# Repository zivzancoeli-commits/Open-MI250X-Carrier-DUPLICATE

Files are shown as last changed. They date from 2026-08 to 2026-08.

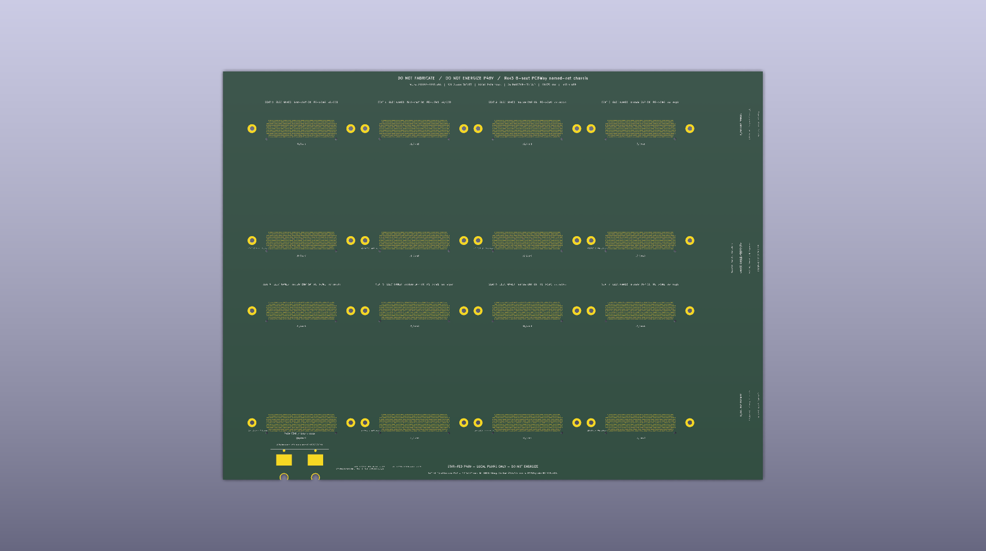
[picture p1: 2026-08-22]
Generated_Project/Rev3_8Seat_PCBWay_Chassis_v1/docs/previews/MI250X_8OAM_PCBWay_Chassis_Stub-top-render.png

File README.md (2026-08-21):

> **DUPLICATE working copy — not the original.**
> Original: https://github.com/zivzancoeli-commits/Open-MI250X-Carrier
> Marked duplicate: 2026-08-21

# Open MI250X Carrier

## Purpose
This project collects public evidence needed to design a minimal open-source carrier board for surplus AMD Instinct MI250X OAM modules. It is organized as a reverse-engineering knowledge base: public documentation is collected first, facts are extracted into notes, and unknown or proprietary behavior is tracked instead of assumed.

## Workflow
- Collect public links and local reference copies in [02_AMD_Docs](02_AMD_Docs/) and [13_Reference_Docs](13_Reference_Docs/).
- Extract design-relevant facts into [09_AI_Notes](09_AI_Notes/), separating verified information from questions.
- Use research in [08_Research_Papers](08_Research_Papers/) to understand topology, bandwidth, and system context before design decisions.
- Carry verified mechanical, PCIe, power, cooling, firmware, and software assumptions into schematic, layout, prototype, and validation work.

## Top-Level Folders
- [02_AMD_Docs](02_AMD_Docs/): upstream public links for OAM, AMD matrix cores, ROCm compatibility, and MI250X software support.
- [08_Research_Papers](08_Research_Papers/): architecture and data-movement research, currently focused on topology and bandwidth.
- [09_AI_Notes](09_AI_Notes/): topic notes for architecture, PCIe, power, cooling, clocking, management, ideas, questions, and unknowns.
- [13_Reference_Docs](13_Reference_Docs/): local indexes and reference material for AMD, ROCm, OAM/OCP, Molex, cooling, firmware, memory, and components.

## Known Information
- Manual project status items: gather public documentation, understand OAM, identify undocumented interfaces, create architecture, draw schematic, PCB layout, prototype.
- Manual note: undocumented behavior should be tracked as an open question rather than assumed.
- `Wanted_Documents.rtf` tracks OAM, AMD, PCIe, power, cooling, and photo references; no image files are currently present.
- MP2975 is listed as believed present on MI250X, but not visually confirmed.

## Project Roadmap
1. Documentation Collection
2. Knowledge Extraction
3. Reverse Engineering
4. Schematic Design
5. PCB Layout
6. Prototype
7. Bring-up and Validation

## Open Questions
- Mechanical, baseboard, connector, PCIe routing, REFCLK, PMBus, VRM, and OAM thermal references are listed as missing or incomplete.
- Three local PDFs could not be read because they report invalid PDF structure.

## TODO
- Keep `Wanted_Documents.rtf` aligned with files added under `13_Reference_Docs`.
- Move verified findings into `09_AI_Notes` with clear evidence and uncertainty labels.

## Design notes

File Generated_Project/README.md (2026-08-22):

# Generated Project — MI250X OAM Prototype Carrier Rev1

Auto-generated KiCad 9 hierarchical schematic for a **single AMD Instinct MI250X OAM** prototype carrier board.

**Status:** `0.1-prototype` — architectural scaffold, not layout-ready or procurement-ready.

## Open in KiCad

```
Generated_Project/Rev1_MI250X_Carrier/MI250X_Carrier_Rev1.kicad_pro
```

Requires **KiCad 9** (schematic format version `20250114`).

## Regenerate

```bash
python3 Generated_Project/tools/generate_kicad_project.py
```

## Hierarchy

| Sheet | File | Function |
|---|---|---|
| Root | `MI250X_Carrier_Rev1.kicad_sch` | Top-level sheet instances |
| OAM Interface | `sheets/02_oam_interface.kicad_sch` | Mirror Mezz Conn0/Conn1 placeholders |
| Host PCIe | `sheets/03_host_pcie.kicad_sch` | Gen4 x16 host edge / routing |
| Power System | `sheets/04_power_system.kicad_sch` | 12V input, OAM 12V, 3.3V management |
| Clocking & Reset | `sheets/05_clocking_reset.kicad_sch` | 100 MHz PE_REFCLK, PERST# |
| Management | `sheets/06_management.kicad_sch` | FRU EEPROM, I2C, PMBus, UART, temp sensor |
| Test Points | `sheets/07_test_points.kicad_sch` | Bring-up measurement access |
| Expansion | `sheets/08_expansion.kicad_sch` | Multi-OAM hooks (DNP on Rev1) |

## Documentation

- `Rev1_MI250X_Carrier/docs/sources.md` — verified references
- `Rev1_MI250X_Carrier/docs/assumptions.md` — prototype assumptions
- `Rev1_MI250X_Carrier/docs/open_questions.md` — blocking TODOs
- `Rev1_MI250X_Carrier/docs/oam_signal_map.md` — OCP logical signal names
- `ENGINEERING_REVIEW.md` — post-generation review report
- `BOM_Rev1_Prototype.md` — placeholder BOM

## Design rules

- OCP OAM signal **names** used where verified; physical pin numbers **TODO**.
- AMD-specific behavior marked **TODO** — not routed or assigned.
- Does not modify `16_KiCad_Design/` per `AI_DESIGN_RULES.md`.

## Buyable first system (copied tree, 2026-08-17)

Do not overwrite Rev1 or other Rev2 production folders. The 2-OAM **v1.0-mapped stub** (not fab-ready) is:

```
Generated_Project/Rev2_MI250X_Carrier_BuyableFirstSystem_v1/
```

Shopping list: `20_System_BOM/SHOPPING.md`. Pin map authority: `22_Pinmap_Research/` (OCP generic v1.0, 688 contacts, not r2.0).

## Rev3 8-seat PCBWay chassis (Chamber B PCB only, 2026-08-22)

**DO NOT ENERGIZE P48V.** POWER+MECH first-article zip is in `Rev3_8Seat_PCBWay_Chassis_v1/fab/`. Do not upload from this agent. Does not overwrite Rev1 or Rev2 trees.

```
Generated_Project/Rev3_8Seat_PCBWay_Chassis_v1/
```

Eight electrically designed OAM seats on a **12-layer 2.0 mm** stuffed-switch target. First article: seats **0–1** GCD0 x16. Compatible with the Chamber B sheet (X11DPH-T neighbour, not on this PCB). See `Rev3_8Seat_PCBWay_Chassis_v1/docs/STATUS.md`.

**8× full-width CONCEPT** (ideas only, **DO NOT FABRICATE** as live PE): `Rev3_8Seat_FULLWIDTH_CONCEPT/CONCEPT.md`. Late-bind reservations: `Rev3_8Seat_FULLWIDTH_CONCEPT/LATE_BIND.md` (**16× x16 + four BGA escapes = respin**). X11DPH-T **cannot light 8× full-width**. Do not invent overlay / ball maps / CEM/MCIO. **DO NOT ENERGIZE.** The POWER+MECH zip will **not** work as a live GPU chassis if sent to PCBWay.

## Exhaustive public-source hunt (copied tree, 2026-08-17)

Research only — **not fab-ready**. Findings: `Generated_Project/Rev2_MI250X_Carrier_ExhaustiveSourceHunt_v1/FINDINGS.md`.

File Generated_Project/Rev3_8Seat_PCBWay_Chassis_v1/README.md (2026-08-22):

# Rev3 — 8-seat chassis, 2-module first article (POWER+MECH)

**DO NOT ENERGIZE P48V** until Molex 1.2 A/contact at 48–59.5 V (2 oz) is written (ticket 167157).  
**Do not upload from this agent.** Eli uploads `fab/Rev3_8Seat_PCBWay_12L_492x372_qty5_gerbers.zip` if he accepts it.

Chamber B **OAM chassis PCB** only. Not a motherboard. Do not swap X11DPH-T.

- **First-article target: seats 0–1.** Without overlay, 2× MI250X = two modules **sit** and at most **GCD0** on each can be targeted (**2 GCDs**). **Not** 2× full-width (**4 GCDs**).
- Legal host PE today: Conn0 OCP `PCIE_*` = `PE_S0_GCD0_x16` + `PE_S1_GCD0_x16` toward the host keepout. GCD1 named-only. Not S1–S7. Conn1 has **0** `PCIE_*`.
- Host X11DPH-T: two GCD0 x16 **fit**; two full-width modules **do not**. **No CEM/MCIO MPN invented.**
- Same PCB populate **2 → 4 → 8**. Later-seat x16 names + SW0–SW3 DNP kept. Do not stuff switches this article.
- Pin names: OCP generic **v1.0**. **v1.x only.** r2.0 is UNUSABLE. P3V3 = Conn0 C1/C2.
- **P48V:** Anderson **6325G1** + 2× **1382** → star spines (not a 100 A flood) → per-seat **0476015.MR** 15 A. First populate F0/F1. Off-board 48 V: 240 V / 50 A single-phase class — **not** RST-5000-48 (3-phase).
- **P12V1 / P3V3:** **THL 40-4812WI** (40 W from 48 V) + **OKI-78SR-3.3/1.5-W36-C** (4.95 W from P12V1). No GPU VRM.
- TEST*/RFU/DO_NOT_USE **unmapped**. PVREF **not driven**. S1–S7 **no net**.
- Silk keeps **DO NOT ENERGIZE P48V**. PE stays unrouted (DNP switches).

| File | What |
|---|---|
| `fab/Rev3_8Seat_PCBWay_12L_492x372_qty5_gerbers.zip` | Gerbers, drill, IPC-356, PnP, FAB_NOTES, BOM |
| `docs/STATUS.md` | What Eli can upload vs what stays DNP |
| `docs/EPYC_2P_PUBLIC_SOURCES.md` | Research-only: opened AMD/OEM 2P xGMI URLs. **No 4P path in public docs.** Not a motherboard. |
| `docs/CONCEPT_8x_FULL_WIDTH.md` | Pointer to 8× full-width **CONCEPT** (ideas only) |
| `docs/LATE_BIND.md` | Pointer: reserved vs later-spin (**respin**, not silk ECO) |
| [`../Rev3_8Seat_FULLWIDTH_CONCEPT/LATE_BIND.md`](../Rev3_8Seat_FULLWIDTH_CONCEPT/LATE_BIND.md) | Late-bind table. **DO NOT FABRICATE** live PE. |
| [`../Rev3_8Seat_FULLWIDTH_CONCEPT/CONCEPT.md`](../Rev3_8Seat_FULLWIDTH_CONCEPT/CONCEPT.md) | 8× full-width fabric sketch. **DO NOT FABRICATE.** X11DPH-T cannot light 256 DS. |
| `docs/FAB_NOTES.md` | Stackup, skip-pin NC, do-not-energize |
| `docs/PCBWAY.md` | Guest quotes 2026-08-21. Agent does not upload. |
| `BOM.md` | PCB bill with buyable MPNs |
| `docs/previews/` | Top SVG/PNG |

```
python3 Generated_Project/Rev3_8Seat_PCBWay_Chassis_v1/tools/generate_from_v10_pinmap.py
python3 Generated_Project/Rev3_8Seat_PCBWay_Chassis_v1/tools/export_fab.py
```

Do not “Update PCB from Schematic”. Do not stuff PM8536 on this article. Do not upload to PCBWay from this tree. First article still cannot run 2 live GPUs without maps. **This zip will not work as a live GPU chassis if sent to PCBWay.**

**8× full-width CONCEPT** (sibling folder): ideas only. **DO NOT FABRICATE** as live PE. **DO NOT ENERGIZE.** Host stays X11DPH-T and **cannot light 8× full-width**. Routing 16× x16 + four 1311-ball escapes is a **respin** (`LATE_BIND.md`).

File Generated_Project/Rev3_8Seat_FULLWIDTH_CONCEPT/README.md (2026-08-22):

# Rev3 8× full-width CONCEPT (ideas only)

**CONCEPT / DO NOT FABRICATE / DO NOT ENERGIZE P48V.**

This is **not** a KiCad project to tape out and **not** the POWER+MECH first-article zip.

| File | What |
|---|---|
| [CONCEPT.md](CONCEPT.md) | Architecture: public fact vs hypothesis vs missing, mermaid + ASCII, can/cannot |
| [LATE_BIND.md](LATE_BIND.md) | Reserved vs later spin. **16× x16 + four BGA escapes = respin, not silk ECO.** |
| [concept_fabric.svg](concept_fabric.svg) | Block diagram (same story as the mermaid) |
| `../Rev3_8Seat_PCBWay_Chassis_v1/` | Existing 8-seat board (seats 0–1 first article). Four PM8536 DNP courtyards already placed. |

Host stays **X11DPH-T**. This CONCEPT **cannot light 8× full-width** on that host. Do not design a CPU board here. Do not invent overlay / ball maps / CEM/MCIO / r2.0 / S1–S7.

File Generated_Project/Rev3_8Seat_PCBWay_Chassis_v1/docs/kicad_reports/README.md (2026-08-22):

# KiCad 9.0.9 CLI reports (not a fab sign-off)

Run 2026-08-22 on the **12-layer 2.0 mm** POWER+MECH first article after zone fill (**2-module target: seats 0–1 GCD0 x16**).

- `drc.rpt` / `drc.json` — **0 errors**, **38** warnings, **268** unconnected items:
  - `lib_footprint_mismatch` **28** (warning): 16× 218910-1115 + SB175 + fuses/bucks (placed pads carry nets the library footprint does not).
  - `silk_overlap` / `silk_edge_clearance` / `text_height` (warning).
  - `isolated_copper` **5** (warning): leftover pour islands, not a submit blocker.
  - Unconnected **268**: PE / REFCLK / PERST# have names but no tracks (four DNP PM8536). Count may be truncated by the CLI.
- Layer SVG: Edge.Cuts, F.SilkS, F.Cu (filled), F.CrtYd, Dwgs.User, Cmts.User, In1/In4/In7/In10 (GND planes).
- PCB top preview: `../previews/MI250X_8OAM_PCBWay_Chassis_Stub-top.{svg,png}`.

Do not “Update PCB from Schematic”. **DO NOT ENERGIZE P48V.** Do not stuff the DNP switches. First article is seats 0–1 GCD0 x16 (2 GCDs). Later-seat 8-wide names stay; host X11DPH-T cannot light 4× x16 or 256 DS.

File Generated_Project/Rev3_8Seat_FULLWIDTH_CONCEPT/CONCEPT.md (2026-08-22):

# CONCEPT — 8× MI250X full-width chassis fabric

**CONCEPT / IDEAS ONLY. DO NOT FABRICATE. DO NOT ENERGIZE P48V.**  
**Not a motherboard. Not a PCBWay zip. Not a live PE design.**

This folder is an architecture sketch Eli can build later spins on. It sits beside the Rev3 8-seat board (`Generated_Project/Rev3_8Seat_PCBWay_Chassis_v1/`). First-article populate remains **seats 0–1, GCD0 x16 only**. The 8-wide names and four PM8536 DNP courtyards already on that board are the physical hooks for this CONCEPT — they are **not** routed, stuffed, or claimed DRC-clean as live PE.

Do **not** invent: AMD overlay pad numbers, PM8536 ball maps, CEM/MCIO pinouts, OAM r2.0 maps, S1–S7 assignments, TEST\*/RFU/DO_NOT_USE nets, or a host-cable MPN.

Labels: **Verified** (public doc / this repo’s pinmap CSVs) · **Hypothesis** (Eli invited; not a pin assignment) · **Missing** (blocks a later spin).

---

## What this CONCEPT is

Chassis **fabric** for eight OAM v1.x seats: 16 named x16 PE buses, four DNP switch courtyards, named host uplinks, and an xGMI mesh drawn as **boxes and port names only**.

Host of record stays SuperMicro **X11DPH-T** (~80 Gen3 lanes). **This CONCEPT cannot light 8× full-width on that host.** Do not design a new CPU board here.

## What this CONCEPT is not

- A fab package (Gerbers in `Rev3_8Seat_PCBWay_Chassis_v1/fab/` are POWER+MECH first article).
- A legal GCD1 pad map, xGMI pad map, or switch pinout.
- A claim that X11DPH-T can drive 256 downstream lanes.

---

## Public fact vs hypothesis vs missing

| Item | Class | Notes |
|---|---|---|
| 8 OAM v1.x seats, KOZ **103×166 mm**, 4×2 → floor **412×332 mm** on outline **492×372 mm** | **Verified** mech (KOZ/Fig 14); 4×2 tiling **Inferred** | Molex **218910-1115** ×16. P3V3 = Conn0 **C1/C2** only. **r2.0 unused.** |
| Conn0 `PCIE_TX/RX0–15` P/N = 64 pads, lanes 0–15 | **Verified** OCP host link | Architectural name `PE_Sn_GCD0_x16`. Pin list: PETp/n + PERp/n [15:0], Conn0, Required. |
| Conn1 `PCIE_*` | **Verified** **0** pads | GCD1 is **not** an OCP `PCIE_*` name. |
| `PE_Sn_GCD1_x16` (8 names) | **Hypothesis** name only | Overlay **Unknown**. **Do not assign S1–S7.** Conn1 `S7_*` = SERDES_7 reserved, **no net**. |
| 16 named x16 PE = “full width” | **Hypothesis** architecture | 8×2 GCD × x16. Dual-GCD is a public MI250X fact; the pad split is not. |
| PM8536B-FEI ×4, 96-lane Gen3, 1311-ball 37.5 mm 1.0 mm | **Verified** Microchip PFX package table | Courtyards **already on the Rev3 board**, **DNP**. **Ball map Missing.** |
| Each SW: 2 seats × 2 GCD × x16 DS + one x16 US (64 DS + 16 US) | **Hypothesis** partition | 80 of 96 lanes; 16 spare/SW. **Not a pinout.** |
| 256 DS + 64 US vs 4×96 = 384 | **Verified** arithmetic | Lane counts only. No balls, no routing. |
| X11DPH-T 3× x16 + 4× x8 ≈ **80** Gen3 | **Verified** SuperMicro | 4× US x16 = 64 **fit as a host uplink budget**. **256 DS do not.** CONCEPT **cannot light 8 full-width** on this host. |
| xGMI / Infinity Fabric mesh (`XGMI_Sn_P0`…) | **Hypothesis** boxes + port names | **Not** mapped to S1–S7. S1–S7 stay **no net**. |
| P48V SB175 star + per-seat `0476015.MR` | **Verified** on Rev3 copper | 240 V / 50 A **single-phase** → off-board **DPU-3200-48 class**. **Not** RST-5000-48 (3-phase). **DO NOT ENERGIZE.** |
| Host attach keepout + `PE_SWk_US_x16` names | **Hypothesis** names | **No** CEM/MCIO/SlimSAS MPN. Keepout only. |
| AMD 688-pad overlay | **Missing** | Blocks GCD1, xGMI, live PE. |
| PM8536 ball map | **Missing** | Blocks stuffing SW0–SW3. |
| Host plug + cable | **Missing** | Blocks lighting even named US links. |
| Molex 1.2 A/contact at 48–59.5 V (2 oz) | **Missing** (ticket 167157) | Blocks energize. |
| GPU cooling / cold plate | **Missing** | Not on this PCB. Do not shop onto the chassis BOM. |

---

## Seat grid (same PCB)

```
Y=20   SEAT0  SEAT1  SEAT2  SEAT3     |  SW0  SW1     host keepout
Y=186  SEAT4  SEAT5  SEAT6  SEAT7     |  SW2  SW3     (no cable MPN)
south: SB175 star + F0..F7           |  12V brick south of SW3
```

Populate on the **same copper**: seats **0–1** (first article, no stuffed switch) → **0–3** → all **8** + SW0–SW3. First article still cannot run live GPUs.

---

## PE fabric (named buses only)

**Verified** GCD0 pads: `OAM{n}_PCIE_*` = Conn0 OCP `PCIE_*`.  
**Hypothesis** names (not pad maps): `PE_Sn_GCD0_x16`, `PE_Sn_GCD1_x16`, `PE_SWk_US_x16`.

```
SW0 = seats 0,1    SW1 = seats 2,3    SW2 = seats 4,5    SW3 = seats 6,7
each:  PE_Sa_GCD0_x16 + PE_Sa_GCD1_x16 + PE_Sb_GCD0_x16 + PE_Sb_GCD1_x16  →  64 DS
       PE_SWk_US_x16  →  host keepout                                     →  16 US
```

```
8 × 2 × x16 = 256 DS
4 × x16 US  =  64 US
need 320 switch ports; 4 × 96 = 384  → 64 spare (hypothesis load)
```

Host **X11DPH-T ~80** can **name** 4× x16 US (64). It **cannot** present 256 host lanes. Switch concentration / oversubscription is an idea, not a working system. **Do not claim DRC-clean live PE.** PE / REFCLK / PERST# stay unrouted.

---

## Block diagram

```mermaid
flowchart LR
  subgraph HOST["Host of record — X11DPH-T  (~80 Gen3)  NOT on this PCB"]
    CPU["2× 6230  ·  3× x16 + 4× x8"]
  end

  subgraph KEEPOUT["Host keepout — names only · NO cable MPN"]
    US0["PE_SW0_US_x16"]
    US1["PE_SW1_US_x16"]
    US2["PE_SW2_US_x16"]
    US3["PE_SW3_US_x16"]
  end

  subgraph FABRIC["CONCEPT chassis fabric  ·  DO NOT FABRICATE as live PE"]
    SW0["U_SW0 DNP\nPM8536B-FEI\n96-lane · no ball map"]
    SW1["U_SW1 DNP"]
    SW2["U_SW2 DNP"]
    SW3["U_SW3 DNP"]
    S0["SEAT0\nGCD0 Verified Conn0 PCIE\nGCD1 named-only"]
    S1["SEAT1"]
    S2["SEAT2"]
    S3["SEAT3"]
    S4["SEAT4"]
    S5["SEAT5"]
    S6["SEAT6"]
    S7["SEAT7"]
  end

  CPU -.->|"64 US named; 256 DS do NOT fit"| KEEPOUT
  US0 --> SW0
  US1 --> SW1
  US2 --> SW2
  US3 --> SW3
  SW0 --> S0
  SW0 --> S1
  SW1 --> S2
  SW1 --> S3
  SW2 --> S4
  SW2 --> S5
  SW3 --> S6
  SW3 --> S7
```

---

## xGMI / Infinity Fabric — boxes and port names only

**Hypothesis.** These names are chassis-side idea labels (`XGMI_Sn_P0` …). They are **not** OCP pin names, **not** AMD overlay pads, and **must not** be tied to S1–S7 / TEST\* / RFU / DO_NOT_USE.

Legend (hypothesis): **P0** north · **P1** east · **P2** south · **P3** west. Edge ports that have no neighbour stay unused in the sketch.

### 4-OAM mesh (physical 2×2: seats 0, 1, 4, 5)

```
        XGMI_S0_P1 <----> XGMI_S1_P3
  SEAT0                    SEAT1
        XGMI_S0_P2          XGMI_S1_P2
           ^                   ^
           |                   |
           v                   v
        XGMI_S4_P0          XGMI_S5_P0
  SEAT4                    SEAT5
        XGMI_S4_P1 <----> XGMI_S5_P3
```

### 8-OAM mesh (4×2, all seats)

```mermaid
flowchart TB
  S0["SEAT0\nP0 P1 P2 P3"]
  S1["SEAT1"]
  S2["SEAT2"]
  S3["SEAT3"]
  S4["SEAT4"]
  S5["SEAT5"]
  S6["SEAT6"]
  S7["SEAT7"]
  S0 ---|"XGMI_S0_P1 ↔ XGMI_S1_P3"| S1
  S1 ---|"XGMI_S1_P1 ↔ XGMI_S2_P3"| S2
  S2 ---|"XGMI_S2_P1 ↔ XGMI_S3_P3"| S3
  S0 ---|"XGMI_S0_P2 ↔ XGMI_S4_P0"| S4
  S1 ---|"XGMI_S1_P2 ↔ XGMI_S5_P0"| S5
  S2 ---|"XGMI_S2_P2 ↔ XGMI_S6_P0"| S6
  S3 ---|"XGMI_S3_P2 ↔ XGMI_S7_P0"| S7
  S4 ---|"XGMI_S4_P1 ↔ XGMI_S5_P3"| S5
  S5 ---|"XGMI_S5_P1 ↔ XGMI_S6_P3"| S6
  S6 ---|"XGMI_S6_P1 ↔ XGMI_S7_P3"| S7
```

On-module GCD0↔GCD1 Infinity Fabric is a public dual-GCD fact and lives **on the module**, not as a chassis net.

---

## 48 V

Existing Rev3 path: Anderson **6325G1** + 2× **1382** (SB175) → star + Kelvin → per-seat **0476015.MR** 15 A → local Conn0 pours. **Not** a 100 A flood. **Not** Dell D3000E-S1 (12 V CRPS).

Wall: **240 V / 50 A single-phase** → off-board **DPU-3200-48 class**. **Do not specify RST-5000-48** (3-phase). Off-board PSU is **not** a PCB BOM item.

**DO NOT ENERGIZE** until Molex 1.2 A/contact at 48–59.5 V (2 oz) is written.

---

## Host attach

Keepout on the 40 mm strip + four named US links (`PE_SW0_US_x16` … `PE_SW3_US_x16`). First-article silk still calls **two** GCD0 x16 (`PE_S0_GCD0_x16` + `PE_S1_GCD0_x16`) because that is the only legal named host PE **today**.

No invented cable MPN. No CEM / SlimSAS / MCIO pinout. SuperMicro CBL-MCIO is a UBB cable, not this host.

---

## Later-spin checklist (do not do in this CONCEPT)

1. AMD overlay (GCD0 confirm, GCD1 pads, xGMI vs S1–S7 — or leave S1–S7 unmapped).
2. Public/legal PM8536 ball map, then escape (finer than 6/6 mil; requote).
3. Host plug with a **cited** datasheet; still do not invent OAM↔cable maps.
4. Molex 1.2 A/contact write-up, then reconsider energize.
5. Cooling — off this PCB.
6. A host that can actually light 256 DS if the goal is 8× full-width **host-equivalent** PE. X11DPH-T is not that host. This folder does **not** design that board.

See **[LATE_BIND.md](LATE_BIND.md)**: what is reserved vs what a later spin must add. **16× x16 PE + four 1311-ball escapes = respin, not a silk ECO.** Do not claim the POWER+MECH zip works as a live GPU chassis if sent to PCBWay.

---

## Can / cannot (this CONCEPT)

**Can (ideas / names / mech already on Rev3):**

- Sit 8 modules (KOZ, Molex, NPTH) on the existing 8-seat PCB.
- Name 16× x16 PE buses and 4× US x16 toward the keepout.
- Cite Conn0 OCP `PCIE_*` as GCD0 on every seat.
- Keep four PM8536 DNP courtyards as the public-MPN switch idea (384 vs 320 lane arithmetic).
- Draw xGMI as boxes and `XGMI_Sn_P*` names.
- Keep P48V star + per-seat fuses; 2→4→8 populate.

**Cannot:**

- Light **8× full-width** on X11DPH-T (~80 vs 256 DS).
- Map GCD1 pins, xGMI ports, or switch balls.
- Assign S1–S7 or TEST\*/RFU/DO_NOT_USE.
- Route or DRC-clean live PE.
- Invent CEM/MCIO/r2.0.
- Energize P48V or upload this CONCEPT to PCBWay as a live 8-wide.

**DO NOT FABRICATE this CONCEPT as live PE. DO NOT ENERGIZE P48V.**

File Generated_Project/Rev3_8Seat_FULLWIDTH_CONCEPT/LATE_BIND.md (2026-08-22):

# LATE BIND — what is reserved vs what a later spin must add

**DO NOT ENERGIZE P48V. First-article POWER+MECH zip remains sit-only.**  
**CONCEPT 8× full-width: DO NOT FABRICATE as live PE.**  
**Do not claim this board will work as a GPU chassis if sent to PCBWay.**

Routing **16× x16 PE** and escaping **four 1311-ball 1.0 mm BGAs** is a **copper respin**, not a silkscreen ECO. Named nets, courtyards, and comment-layer corridors do **not** become tracks when an overlay arrives.

Do **not** invent: AMD overlay pads, PM8536 balls, CEM/MCIO pinouts, r2.0 maps, S1–S7, TEST\*/RFU/DO_NOT_USE, or a host-cable MPN.

Same PCB **outline** (492×372 mm) for populate **2 → 4 → 8**. That is the only “no-respin” promise. PE / BGA / host plug are not.

Canonical CONCEPT: [CONCEPT.md](CONCEPT.md). Rev3 tree: `Generated_Project/Rev3_8Seat_PCBWay_Chassis_v1/`.

---

## Honesty: small change vs respin

| When maps arrive | Small (same outline / populate) | Respin (new copper / geometry) |
|---|---|---|
| Stuff more OAMs / F2–F7 | **Yes** — seats and fuses already on the board | |
| Assign already-named Conn0 `PCIE_*` nets | Names exist | **Tracks, vias, impedance** still a respin |
| GCD1, 16× x16, four-switch fabric | Names + DNP courtyards exist | **Escape + route 256 DS + 64 US** is a respin |
| Host connector | Keepout rectangle exists | **Footprint + pin map + routes** is a respin |
| PM8536 stuffed | 40 mm courtyards exist | **1311-ball fanout** (finer than guest **6/6 mil**, requote) is a respin |

---

## Missing doc → reserved now → later spin adds

### Overlay (AMD 688-pad)

| | |
|---|---|
| Reserved | **GCD0:** public Conn0 `PCIE_TX/RX0–15` P/N (64 pads/seat) already named `OAM{n}_PCIE_*`. Architectural bus `PE_Sn_GCD0_x16`. Seats **0–1** called out toward the host keepout. **GCD1:** names `PE_Sn_GCD1_x16` only. Conn1 has **0** `PCIE_*`. S1–S7 **no net**. |
| Later spin | Confirm GCD0 against overlay. Assign **GCD1 pads and nets**, then **route**. Do **not** guess tracks now. Do **not** assign S1–S7 / TEST\*/RFU/DO_NOT_USE here. |
| Not small | Any PE pair routing. |

### PM8536B-FEI ×4

| | |
|---|---|
| Reserved | Four **DNP** 40 mm courtyards **SW0–SW3** (already on the Rev3 board). Package table (public): 96-lane Gen3, 1311-ball 37.5 mm, 1.0 mm. Hypothesis load (not a pinout): 64 DS + 16 US per switch. |
| Later spin | Legal/public **ball map** → footprint → **escape**. Requote vs 6/6 mil guest stack. |
| Not small | BGA fanout. Courtyard ≠ footprint. |

### Host plug

| | |
|---|---|
| Reserved | Host-strip **keepout** + names `PE_S0_GCD0_x16`, `PE_S1_GCD0_x16` (first article) and `PE_SW0..3_US_x16` (CONCEPT). **No MPN.** |
| Later spin | Place a **real** connector from a cited datasheet. Still do not invent OAM↔cable maps. |
| Not small | Footprint + PE to that connector. X11DPH-T still **cannot light 256 DS**. |

### Molex 1.2 A / cooling

| | |
|---|---|
| Reserved | Silk **DO NOT ENERGIZE P48V**. Ticket **167157** OPEN. Coolers **not on this PCB**. |
| Later spin | Molex current write-up (off-board decision to energize). Cooling is **off-board** — do not shop onto the chassis BOM. |
| Not a PCB ECO | Neither item is a silkscreen fix. |

### 2 → 4 → 8 populate

| | |
|---|---|
| Reserved | Same **492×372** outline, 8 KOZ, 16× Molex, 32× M3.5 NPTH, SB175 star, per-seat `0476015.MR`. First article: seats **0–1**, F0/F1. |
| Later spin | Stuff more seats/fuses. **Still no live PE** until overlay + routes + host plug + Molex current. |

---

## Comment-layer corridors (no copper, no fake pins)

On the Rev3 PCB, **Dwgs.User / Cmts.User** only (not fab silk, not tracks):

| Corridor | Approx. box (mm) | Meaning |
|---|---|---|
| Seats 0–1 GCD0 → host keepout | (105, 138) – (452, 178) | Planning note for `PE_S0_GCD0_x16` + `PE_S1_GCD0_x16` toward the existing keepout. Conn0 Y-band. |
| Seats 0–1 GCD0 → SW0 courtyard | (105, 22) – (452, 56) | Planning note toward **U_SW0** DNP courtyard. Not a ball map. |

These boxes overlap later KOZs on purpose: they are **intent**, not a route. Inner layers named `signal_reserved` in generation meta are the same class of note — **not** escaped pairs.

---

## PCBWay

The zip in `Rev3_8Seat_PCBWay_Chassis_v1/fab/` is **POWER+MECH sit-only**. Sending it does **not** yield a working 2× or 8× GPU chassis. **Do not upload from this agent.** **DO NOT ENERGIZE.**

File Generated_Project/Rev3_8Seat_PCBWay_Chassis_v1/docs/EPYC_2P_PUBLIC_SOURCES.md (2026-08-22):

# AMD EPYC 2P platform — public source list and synthesis

**Tree:** `Generated_Project/Rev3_8Seat_PCBWay_Chassis_v1/docs/`  
**Date:** 2026-08-22  
**Scope:** research only. Public AMD architecture overviews, NUMA pubs, tuning guides, OEM board/server manuals that show 2P xGMI, and older SP3 material if it actually specifies 4P.  
**Not in scope:** a 4-socket motherboard, an SP5 pin map, an invented xGMI mesh, PE/OAM maps, or any Gerber change.

Labels used below:

| Label | Meaning |
|---|---|
| **Opened** | This URL was retrieved and read for this note. |
| **Login-gated** | AMD names the document publicly but the body requires an AMD Documentation Hub login. The title is real; the body was **not** used. |
| **NDA / not public** | AMD (or an AMD reply on a public forum) states the document is partner-only. |

---

## Conclusion (quote-backed)

**No 4P path in public docs** for Socket SP5 (EPYC 9004 Genoa / 9005 Turin), and no public SP3 4P design document was found either.

Every AMD architecture overview that was opened states **single- or dual-socket only**. Inter-socket xGMI is written as a **pairwise** connection between **two identical** SoCs, using **3 or 4** G-links (each up to x16, i.e. 48 or 64 lanes per socket consumed, leaving **80 or 64 PCIe Gen5 lanes per socket**, **160 or 128 system-wide**). No opened AMD or OEM document specifies a 4-socket SP5 topology, a 4-way xGMI mesh, or a way to scale a 2P board to 4P.

Closest AMD sentence (Turin, opened):

> “AMD EPYC 9005 Series Processors support **single- or dual-socket** system configurations. […] In dual-socket systems, **two identical** EPYC 9005 series SoCs are connected via their corresponding External Global Memory Interconnect [xGMI] links. […] System manufacturers can elect to use either **3 or 4** of these xGMI/Infinity Fabric links […]. A typical dual socket system will reconfigure **64 PCIe lanes (4 links)** from each socket […] the system has a total of **128 PCIe lanes**. […] reducing the number of Infinity Fabric G-Links […] from 4 to 3 […] up to **160 lanes** for PCIe (**80 per socket**) by utilizing only **48 lanes** per socket […].”  
> — [AMD EPYC 9005 Processor Architecture Overview (58462)](https://docs.amd.com/api/khub/documents/iZ5eCtQ5v6PyPN7wEd8HQg/content)

Closest SP3 sentence (Naples, opened):

> “**Platform support for one or two SoCs (1P or 2P).**”  
> — [NUMA Topology for AMD EPYC Naples Family Processors (56308)](https://www.amd.com/content/dam/amd/en/documents/epyc-technical-docs/specifications/56308-numa-topology-for-epyc-naples-family-processors.pdf)

There is **no quote-backed exception** in the opened set that says “wire four SP5 sockets together.” SuperMicro’s **H13QSH** is a **quad MI300A / socket SH5** board, not SP5 EPYC 4P. That is a different product and socket. It is listed below so it is not mistaken for an SP5 4P path.

This note does **not** design a 4P board.

---

## How this list was built

Public AMD Documentation Hub / `amd.com` DAM PDFs, OEM motherboard manuals (SuperMicro, GIGABYTE, ASUS), Dell technical guides, and a small number of secondary pages that restate AMD BIOS wording were opened. Search queries included `SP5`, `9004`, `9005`, `xGMI`, `G-link`, `4P`, `quad-socket`, `NUMA topology`, `thermal design guide`, and SP3 `7001/7002/7003`.

URLs that timed out, returned a login splash, or were not retrieved are marked that way. Nothing below invents a pin, a G-link pairing beyond “socket 0 ↔ socket 1”, or an OAM/PE map.

---

## 1. AMD architecture overviews (opened)

These are the primary public statements of 1P/2P, xGMI link count, and leftover PCIe.

| # | Title | URL | Socket / gen | What it actually specifies |
|---|---|---|---|---|
| A1 | AMD EPYC 9005 Processor Architecture Overview (58462, 2025-04-23) | https://docs.amd.com/api/khub/documents/iZ5eCtQ5v6PyPN7wEd8HQg/content | SP5 / 9005 Turin | **1P or 2P only.** `P` SKUs are 1P. 2P requires identical OPNs. IOD “extend[s] the data fabric to a **potential second processor** via its xGMI, or G-links.” **Up to 4 xGMI (G-links), up to 32 Gbps.** Each processor has **4 P-links and 4 G-links**. A G-link is either 2P Infinity Fabric **or** extra PCIe Gen5. **1P: 128 PCIe Gen5.** **2P: 3 or 4 xGMI links** (each up to 16 lanes). **4×x16 xGMI → 64 leftover lanes/socket, 128 system.** **3×x16 xGMI → 80 leftover lanes/socket, 160 system.** Figure 3-3 caption: “Two EPYC 9005 Processors connect through **4 xGMI links** (NPS1).” Lists **login-required** SP5/SP6 NUMA topology (not used here). |
| A2 | Catalog page for 58462 | https://docs.amd.com/v/u/en-US/58462_amd-epyc-9005-tg-architecture-overview | same | Confirms document ID 58462, rev 1.0, 2025-04-23. Points at A1. |
| A3 | 5th Gen AMD EPYC Processor Architecture white paper (70353, March 2025) | https://docs.amd.com/api/khub/documents/UIqhAbjRhgnzgzzdVU4pUw/content | SP5 / 9005 | Marketing/architecture WP. “most powerful **two-socket** servers.” Infinity Fabric is “for interprocessor communication in **2P configurations**.” “We support the use of **three or four links**, each […] **32 Gb/s x16 PCIe**.” Three links → extra 16 lanes/CPU → **160 lanes** total. Four links → “**512 GB/s** between processors.” I/O die has **eight 16-lane SERDES** (128 lanes) with constraints in “server design documentation” (**not attached, not public here**). Bonus PCIe Gen3: **12 lanes in 2-socket**, 8 in 1-socket. Figure 7: 2-socket configuration. **No 4P.** |
| A4 | 4th Gen AMD EPYC Processor Architecture white paper | https://www.amd.com/content/dam/amd/en/documents/products/epyc/4th-gen-epyc-processor-architecture-white-paper.pdf | SP5 / 9004 Genoa; also 8004/SP6 | “**UP TO 128 PCIE GEN 5 LANES IN A 1P CONFIGURATION; UP TO 160 LANES IN A 2P CONFIGURATION (EPYC 9004 SERIES)**.” Non-`P` SKUs: “single-socket and **2-socket**.” `P` SKUs dedicate G-links to PCIe. “**three or four 16-lane ‘G’ links** are used to connect to the **second processor**.” Three links + one extra PCIe link/CPU → **160 lanes** (Figure 9 in the paper). IOD: typically four SERDES to the **second processor**, four to I/O. “**Up to 4 links** of […] Infinity Fabric.” **No 4P.** |
| A5 | Same 4th-gen white paper (Boston mirror) | https://download.boston.co.uk/downloads/1/3/4/13433918-2d48-4eb6-846d-edac7581d95e/221704010-A_en_4th%20Gen%20AMD%20EPYC%20Architecture%20-%20White%20Paper_pdf.pdf | same as A4 | Same text as A4 (opened as a second copy). “no-compromise single-socket servers as well as […] **two-socket** servers.” |
| A6 | AMD EPYC 7003 Series Microarchitecture Overview (57075 rev 3.0, Mar 2022) | https://docs.amd.com/api/khub/documents/cdbcpYJAub6P1i3lB2DRJg/content | SP3 / 7003 Milan | **1P or 2P only.** `P` SKUs 1P. Identical OPNs in 2P. Figure 2-6: “Two EPYC 7003 Processors connect through **4 xGMI links** (NPS1).” 3 or 4 Infinity Fabric links. Each link up to 16 PCIe lanes. Typical 2P: **64 lanes/socket for xGMI, 64 leftover, 128 system**; 3-link: **80 leftover/socket, 160 system.** 1P: 128 PCIe Gen4. Dual-socket: 16 memory channels (8/socket). Resources list **login-required** SP3 NUMA topology. **No 4P.** |

---

## 2. AMD tuning / datacenter guides that restate 2P xGMI (opened)

These copy the architecture-overview 2P language. They are listed because they are public, opened, and consistent. They do **not** add a 4P topology.

| # | Title | URL | What it actually specifies |
|---|---|---|---|
| T1 | Best Practices for Cloud Infrastructure… AMD EPYC 9005 (58466) | https://www.amd.com/content/dam/amd/en/documents/epyc-technical-docs/tuning-guides/58466-amd-epyc-9005-tg-cloud-datacenter.pdf | “support both **single- (1P) and dual- (2P)** socket systems.” §3.3.2: two SoCs connect via xGMI; OEM may use **3 or 4** Infinity Fabric links; links share PCIe PHY; “up to half of the 128 PCIe” per socket used for fabric in typical 2P. |
| T2 | Windows Network Tuning Guide, EPYC 9005 (58473) | https://www.amd.com/content/dam/amd/en/documents/epyc-technical-docs/tuning-guides/58473_amd-epyc-9005-tg-windows-network.pdf | “**Dual-socket systems use xGMI links between the sockets.**” Width can be reduced to save power. No 4P. |
| T3 | Linux Network Tuning Guide, EPYC 9005 | https://docs.amd.com/api/khub/documents/N_j16eBDeBn3UvmUky4C_w/content | Points at A1 sections Memory/I/O, NUMA, Dual-Socket. 12 DDR5 channels/socket; 24 on 2P. LLC-as-NUMA points at **login-required** SP5/SP6 NUMA PDF. |
| T4 | RHEL Tuning Guide, EPYC 9005 (58469) | https://www.amd.com/content/dam/amd/en/documents/epyc-technical-docs/tuning-guides/58469_amd-epyc-9005-tg-redhat-enterprise-linux.pdf | NUMA distances; cites **login-required** SP5/SP6 NUMA topology. 1P/2P language only. |
| T5 | Windows Server Tuning Guide, EPYC 9005 (58471) | https://www.amd.com/content/dam/amd/en/documents/epyc-technical-docs/tuning-guides/58471_amd-epyc-9005-tg-windows-server.pdf | NPS 0/1/2/4. NPS0 = one NUMA node across **both sockets** (2P only). Cites login-required SP5/SP6 NUMA. Example: “**2 socket**, 128-core.” |
| T6 | Cloud Infrastructure… EPYC 9004 | https://docs.amd.com/api/khub/documents/lMgojqchIqt9ewPEdr8Mzw/content | Same 2P block as A1 but for 9004: “**potential second processor**,” **up to 4 xGMI @ 32 Gbps**, **4 P-links + 4 G-links**, **128 lanes 1P / 160 lanes 2P**. Figure 2-9 / 5-2: two processors through **4 xGMI links**. §5.3.2: 3 or 4 links; typical 64 leftover/socket (128 system) or 80 leftover (160 system). BIOS: 3–4 xGMI max speed up to 32 Gbps; force width x4/x8/x16. **NPS0 only on dual-socket.** |
| T7 | HPC Tuning Guide, EPYC 9004 | https://docs.amd.com/api/khub/documents/NgOfoW49HKdzztTeLBbekA/content | Same 2P xGMI / 128 vs 160 lane text as T6. |
| T8 | Linux Network Tuning Guide, EPYC 9004 | https://docs.amd.com/api/khub/documents/ScFqtjHuoA5CBw6e~hb01Q/content | Same IOD/xGMI paragraph as T6. Dual-socket chapter. Cites **login-required** “Socket SP5 Platform NUMA Topology for AMD Family 19h Models 10h–1Fh.” |
| T9 | DPDK Tuning Guide, EPYC 9004 (58017) | https://www.amd.com/content/dam/amd/en/documents/epyc-technical-docs/tuning-guides/58017-amd-epyc-9004-tg-data-plane-dpdk.pdf | §2.13 Dual-Socket. Figure: two 9004 CPUs through **4 xGMI links (NPS1)**. 3 or 4 links; 64 leftover/socket typical; 80 leftover if 3-link. |
| T10 | FSI Tuning Guide, EPYC 9004 | https://docs.amd.com/api/khub/documents/LIobwJKhWK3VDZV53PMpdw/content | Same dual-socket xGMI paragraph. Resources: login-required SP5 NUMA + memory population. |
| T11 | EPYC 9004 Series Memory Population Recommendations (public summary) | https://docs.amd.com/api/khub/documents/zynTogiENLgLxWEd4075vQ/content | Public DIMM-population advice. Full “Memory Population Guidelines for AMD Family 19h Models 10h–1Fh” is **login required**. No 4P. |
| T12 | Workload Tuning Guide, EPYC 7002 (56745 rev 0.80, 2019) | https://www.amd.com/content/dam/amd/en/documents/epyc-technical-docs/tuning-guides/2019-amd-epyc-7002-tg-bios-workload-56745_0_80.pdf | BIOS: xGMI link max speed, Dynamic Link Width Management (16→8 lanes). Socket-to-socket only. No 4P topology. |
| T13 | Workload Tuning Guide, EPYC 7003 | https://docs.amd.com/api/khub/documents/KFDbj~3u_tw4TqOAZdwoDA/content | xGMI DLWM 16→8; force width 8 or 2 “on certain platforms.” Still 2-socket language. |
| T14 | Linux Network Tuning Guide, EPYC 7003 | https://docs.amd.com/api/khub/documents/C4jRQ~IJbgFXMY7_n0n4ZQ/content | “In a **two-socket** system, there are xGMI links between the sockets.” |
| T15 | NGINX Tuning Guide, EPYC 7002 | https://www.amd.com/content/dam/amd/en/documents/epyc-technical-docs/tuning-guides/amd-epyc-7002-tg-nginx.pdf | “**Platform support for one or two sockets (1P or 2P).**” Example: “2P, 128C/256T.” |
| T16 | NGINX Tuning Guide, EPYC 7003 | https://docs.amd.com/api/khub/documents/QEMcz2ixKRwqpE6WbWO18A/content | “support **single- or dual-socket** […] except […] ‘P’ suffix […] single-socket.” |

---

## 3. AMD NUMA topology pubs (opened)

| # | Title | URL | Socket / gen | What it actually specifies |
|---|---|---|---|---|
| N1 | NUMA Topology for AMD EPYC Naples Family Processors (56308) | https://www.amd.com/content/dam/amd/en/documents/epyc-technical-docs/specifications/56308-numa-topology-for-epyc-naples-family-processors.pdf | SP3 / 7001 Naples | Bullet: “**Platform support for one or two SoCs (1P or 2P).**” Figures show Socket0 and Socket1 with Infinity Fabric **between those two**. Channel / channel-pair / **socket interleaving (2P system)**. **No 4P figure, no 4P interleave mode.** |
| N2 | Socket SP3 Platform NUMA Topology for AMD Family 19h Models 00h–0Fh (56795 rev 1.00, July 2021) | https://www.amd.com/content/dam/amd/en/documents/processor-tech-docs/design-guides/56795_1_00-PUB.pdf | SP3 / 7003 Milan (Family 19h 00h–0Fh) | “**Platform support for one or two sockets (1P or 2P).**” NPS4 / NPS2 / NPS1 / **NPS0 (2P only)**. Far-hop is “**1-hop xGMI**” to the **other socket** (singular). In 2P, “the system allows for one of the sockets to have no memory.” **No third/fourth socket.** |

Public 9004/9005 NUMA *behavior* (NPS0/1/2/4, LLC-as-NUMA) is in A1 and T6–T10. The dedicated SP5 NUMA PDFs are **login-gated** (section 7). Those gated titles do **not** claim 4P in the public citations; they are named “Socket SP5” / “SP5/SP6,” not 4P.

---

## 4. OEM manuals that show 2P xGMI (opened)

None of these manuals is a 4-socket SP5 board. Block diagrams that were readable show **two** SP5 sockets with xGMI **between them**.

| # | Title | URL | 1P/2P/4P | xGMI as published | PCIe leftover (as published) |
|---|---|---|---|---|---|
| O1 | SuperMicro H13DSG-OM User’s Manual (MNL-2665) | https://www.supermicro.com/manuals/motherboard/H13/MNL-2665.pdf | **Dual** AMD EPYC 9004/9005, **two SP5** sockets (rev 2.00+ for 9005). GPU-oriented. | Block diagram labels **xGMI x16** at **32.0 GT/s** between SOCKET1 and the second SP5 socket (PEG G0/G1/G2/G3 style G-links). BIOS: xGMI Link Width Control / Link Max Speed. | Manual is a GPU board with many PCIe 5.0 x16 / MCIO ports via switches; it does **not** publish an AMD-style “128 vs 160 leftover” table. It **does** show pairwise xGMI, not a 4-socket mesh. |
| O2 | SuperMicro H13DSH User’s Manual (MNL-2577) | https://www.supermicro.com/manuals/motherboard/H13/MNL-2577.pdf | **Dual** 9004/9005 SP5, 24 DIMM, 400 W TDP. | Dual-socket SP5. One extracted label **xGMI x4** (OCR of a dense block diagram; treat width as OEM drawing, not an AMD 4P spec). | Dual-socket I/O: risers + 10× MCIO. No 4P. |
| O3 | SuperMicro H13DSG-O-CPU User’s Manual (MNL-2560) | https://www.supermicro.com/manuals/motherboard/H13/MNL-2560.pdf | **Dual** 9004/9005 SP5. | Silkscreen/block text: **xGMI0, xGMI1, xGMI2, xGMI3** on CPU 1 (P0) and CPU 2 (P1), plus a **“2 Link xGMI”** callout. BIOS xGMI Configuration / Link Width / Max Speed. Still **two** sockets. | Dual GPU-class I/O. “2 Link xGMI” is an OEM 2P option (fewer fabric links, more PE), not a 4P recipe. AMD public docs emphasize 3 or 4 links; this OEM drawing also mentions a 2-link 2P variant. **Do not generalize it into a 4-socket map.** |
| O4 | GIGABYTE MZ73-LM2 User Manual (rev 3.0) | https://download.gigabyte.com/FileList/Manual/server_manual_e_mz73lm2_e_v3.0.pdf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 | **Dual** EPYC 9005/9004, **2× LGA 6096 SP5**, cTDP 500 W. | Block diagram: **“4 x16 xGMI3 up to 32GT/s”** drawn **between CPU0 and CPU1**. BIOS: “Configures the number of **xGMI2 links used on a multi-socket system**. Options: Auto, **3 xGMI Links**, **4 xGMI Links**, **2 xGMI Links + 2 PCI**.” 3-link and 4-link max speed settings. | Four PCIe Gen5 x16 slots (two from each CPU) + MCIO/SlimSAS. BIOS explicitly trades 2 xGMI links for 2 PCI. Matches AMD 3-vs-4-link 2P story. **No fourth socket.** |
| O5 | GIGABYTE MZ73-LM2 product page | https://www.gigabyte.com/Enterprise/Server-Motherboard/MZ73-LM2-rev-3x | Dual SP5, 24 DIMM, 4× PCIe Gen5 x16 | Dual processor. “If only 1 CPU is installed, some PCIe or memory functions might be unavailable.” | Slot_4/3 from CPU_0, Slot_2/1 from CPU_1. No xGMI pinout beyond “dual processor.” |
| O6 | ASUS RS720A-E12-RS12 User Guide | https://dlcdnets.asus.com/pub/ASUS/E25587_RS720A-E12-RS12_UM_V3_WEB.pdf?model=RS720A-E12-RS12 | **2 × Socket SP5**, board **K14PP-D24** | Spec table: “**xGMI (External Global Memory Interface Link)**.” TOC lists “K14PP-D24 block diagram.” Dual-socket server, not 4P. | Up to 9 PCIe Gen5 slots on the system; no AMD leftover-lane table. |
| O7 | ASUS RS720A-E12-RS12 datasheet (Genoa SP5) | https://dlcdnets.asus.com/pub/ASUS/server/RS720A-E12-RS12/Datasheet/Datasheet_RS720A-E12-RS12_AMD_GenoaSP5_9004_V4.pdf | 2 × SP5, 9004 | Same “xGMI (External Global Memory Interface Link)” line. | Expansion slots as in O6. |
| O8 | Dell PowerEdge R7625 Technical Guide | https://www.delltechnologies.com/asset/en-us/products/servers/technical-support/poweredge-r7625-technical-guide.pdf | **Two** EPYC 9004, 2U | New-tech table: “**AMD Interchip global memory interconnect (xGMI) up to 64 lanes**.” CPU interconnect: **xGMI 32 GT/s** (vs 16 GT/s on prior 2P). | “Integrated I/O support for up to **128 lanes** with PCI Express 5 **on Dell platforms (AMD support up to 160 I/O lanes with 2P)**.” Dell chose 128 on this platform; AMD’s 160 is acknowledged as a 2P option, not 4P. |
| O9 | Dell PowerEdge R7615 Technical Guide | https://www.delltechnologies.com/asset/en-gb/products/servers/technical-support/poweredge-r7615-technical-guide.pdf | **One** EPYC 9004 (1P sibling of R7625) | Still lists xGMI as a CPU feature (up to 64 lanes) because the silicon has G-links; this chassis is 1P. | 1P PCIe Gen5. Useful contrast: Dell 1P vs 2P SKUs, not 4P. |
| O10 | ASUS K14PA-U12 User Manual | https://dlcdnets.asus.com/pub/ASUS/server/K14PA-U12/Manual/C22536_K14PA-U12_WEB.pdf?model=K14PA-U12 | **1 × SP5** (contrast) | Single-socket CEB. **No second socket, no xGMI between CPUs.** 1P uses G-links as PCIe (AMD `P`-link/G-link story). | 3× PCIe Gen5 x16 + 8× MCIO. Included so 1P boards are not misread as 2P/4P. |

### Related OEM that is **not** SP5 4P (opened so it is not an accidental “exception”)

| # | Title | URL | What it actually is |
|---|---|---|---|
| X1 | SuperMicro H13QSH User’s Manual (MNL-2692) | https://www.supermicro.com/manuals/motherboard/H13/MNL-2692.pdf | “**Quad AMD Instinct MI300A APUs in sockets SH5**.” BIOS has xGMI Configuration (link width). **Socket SH5, Instinct APU, not EPYC SP5.** A 4-package MI300A board is **not** a written path to scale SP5 2P to 4P. |
| X2 | SuperMicro H13QSH product page | https://www.supermicro.com/en/products/motherboard/h13qsh | “Quad Socket **SH5**,” MI300A, up to 760 W. Same non-exception. |
| X3 | SuperMicro + AMD H13 MI300A System Solution (channel PDF) | https://www.supermicro.com/sites/default/files/content_resources/static_resources/channel_training/20240828_Supermicro_+_AMD_H13_MI300A_System_Solution.pdf | Quad MI300A, motherboard MBD-H13QSH. Not SP5 EPYC. |

---

## 5. Other opened public pages (BIOS / secondary)

| # | Title | URL | Use |
|---|---|---|---|
| S1 | Broadcom: Socket/Inter-Chip Global Memory Interconnect (xGMI) | https://techdocs.broadcom.com/us/en/storage-and-ethernet-connectivity/ethernet-nic-controllers/bcm957xxx/adapters/Tuning/bios-tuning/socketinter-chip-global-memory-i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 | Restates AMD CBS xGMI width (16→8 DLWM). Explicit: “**The Socket/Inter-Chip Global Memory Interconnect option only applies to a 2P system.**” |
| S2 | Cisco UCS C225 M6 / C245 M6 performance tuning (7003) | https://www.cisco.com/c/en/us/products/collateral/servers-unified-computing/ucs-c-series-rack-servers/performance-tuning-wp.html | 2-socket Milan. C245: **4 xGMI** up to 18 Gbps. C225: **3 xGMI** up to 16 Gbps. BIOS can set link count 1–4. Still 2P servers. |
| S3 | NASA HECC: AMD Rome processors | https://www.nas.nasa.gov/hecc/support/kb/entry/658 | One 2P Rome node: **3 xGMI links, 48 PCIe lanes**, xGMI speed BIOS 10.667–18 GT/s, DLWM 16→8. |
| S4 | ServeTheHome: Dell 160 PCIe lane design (SP3 2P) | https://www.servethehome.com/dell-and-amd-showcase-future-of-servers-160-pcie-lane-design/ | Dell R7525 2P; some SKUs “**without XGMI**” so G-links become extra PCIe (the 3-link / 160-lane 2P option). Not 4P. |
| S5 | Hot Chips 35: Zen 4 core and 4th Gen EPYC (AMD, 2023) | https://hc2023.hotchips.org/assets/program/conference/day1/CPU1/HC_Zen4_Epyc_Final_20230825%20-%20Embargoed%20until%20Aug%2029%202023.pdf | Slides label **xGMI / PCIe** on the IOD. Benchmarks are **2P**. No 4P SP5 topology. |
| S6 | SUSE SBP: Optimizing Linux for EPYC 9004 | https://documentation.suse.com/sbp/tuning-performance/html/SBP-AMD-EPYC-4-SLES15SP4/index.html | “**1-socket and 2-socket** models.” Dual-socket must use identical processors. |
| S7 | Giga Computing: EPYC 9005 SP5 platform blog | https://www.gigacomputing.com/en/blog-detail/amd-epyc-9005/ | SP5 shared by 9004 and 9005. Dual-socket “adds […] I/O.” Not a design guide. |
| S8 | Wikipedia: Epyc (secondary) | https://en.wikipedia.org/wiki/Epyc | SKU tables list **1P/2P** and “128 (160 in 2-socket systems).” Not an AMD design spec; consistent with A1–A4. |
| S9 | AMD EPYC product page | https://www.amd.com/en/products/processors/server/epyc.html | OEM list. No 4P SP5 claim. |

Dell Naples NUMA white paper (opened): https://dl.dell.com/manuals/all-products/esuprt_software/esuprt_it_ops_datcentr_mgmt/servers-solution-resources_white-papers3_en-us.pdf — “at most […] **eight NUMA nodes in a dual sockets system**.” Socket interleaving “**only available with 2-processor configurations**.”

---

## 6. Synthesis — only from the opened sources

### Socket and generation

| Platform | Socket | Public AMD max sockets | xGMI in 2P | Leftover PCIe (AMD text) |
|---|---|---|---|---|
| 7001 Naples | SP3 | **1P or 2P** (N1) | Infinity Fabric between S0 and S1 (figures in N1). Link count not numbered as “3 or 4” in 56308. | Not tabulated in 56308. |
| 7002 Rome / 7003 Milan | SP3 | **1P or 2P** (A6, T15, N2) | **3 or 4** links, each up to x16 (A6). OEM 2P examples: 3 links (NASA Rome, Cisco C225) or 4 links (Cisco C245). | **1P: 128 Gen4.** **2P typical: 64 leftover/socket, 128 system.** **2P 3-link: 80 leftover/socket, 160 system.** |
| 9004 Genoa / 9005 Turin | SP5 | **1P or 2P** (A1, A3, A4, T1, T6) | **Up to 4 G-links**, 3 or 4 used between **two** identical SoCs, up to 32 Gbps / 32 GT/s class (A1, A3, O1, O4, O8). | **1P: 128 Gen5** (+ bonus Gen3). **2P 4-link: 64 leftover/socket, 128 system.** **2P 3-link: 80 leftover/socket, 160 system.** Dell R7625: 128 on that OEM, while “AMD support up to 160 […] with 2P” (O8). |

`P`-suffix SKUs are 1P: G-links stay PCIe (A1, A4, A6).

### What “xGMI” is, in writing

- Same **PHY** as PCIe. Protocol on those lanes is Infinity Fabric when used as G-links (A1, A3, A4).
- Each G-link is **up to 16 lanes** (A1, A4, A6).
- A 2P OEM picks **3 or 4** of the four G-links for socket-to-socket fabric (A1, A4, T6). Gigabyte BIOS also offers **2 xGMI + 2 PCI** (O4). SuperMicro H13DSG-O-CPU silkscreen includes **“2 Link xGMI”** (O3). Those are still **two sockets**.
- AMD figures are captioned “**Two** EPYC … Processors connect through **4 xGMI links**” (A1 Fig. 3-3; A6 Fig. 2-6; T6 Fig. 2-9 / 5-2). Pairwise, not a ring of four.
- Far NUMA hop is “**the other processor**” / “**1-hop xGMI**” (A1, N2) — singular other socket.

### What public docs do **not** specify

- No SP5 **4-socket** supported configuration.
- No G-link pairing for sockets 2 and 3.
- No public SP5 **pin map**, G-link ball map, or WAFL pin map (A3 defers SERDES constraints to “server design documentation”).
- No public **Thermal Design Guide** or **Mechanical Design Guide** for SP5 (section 7).
- No public instruction to daisy-chain two 2P boards, or to treat unused G-links as a second xGMI pair to a third CPU.

---

## 7. Documents AMD names but that are not public (not used as design sources)

These titles are real (cited from opened public PDFs). Their bodies were **not** read.

| Document (as named by AMD) | Status | Cited from |
|---|---|---|
| Socket SP5 Platform NUMA Topology for AMD Family 19h Models 10h–1Fh | **Login required** | T8, T10, T11 |
| Socket SP5/SP6 Platform NUMA Topology for AMD Family 1Ah Models 00h–0Fh and Models 10h–1Fh | **Login required** | A1, T3, T4, T5 |
| Memory Population Guidelines for AMD Family 19h Models 10h–1Fh | **Login required** | T10, T11 |
| Memory Population Guidelines for AMD Family 1Ah … Socket SP5 | **Login required** | A1, T5 |
| Socket SP3 Platform NUMA Topology for AMD Family 19h Models 00h–0Fh | A **public** copy of 56795 **was** opened (N2). 7003 overview still says “Login required” for some listings. | A6 vs N2 |
| Memory Population Guidelines for AMD EPYC 7003 | **Login required** | A6 |
| Processor Programming Reference (PPR) / “server design documentation” (SERDES constraints, bifurcation) | **devhub.amd.com; login** (A1, A3) | A1, A3 |
| Thermal Design Guide (TDG) and Mechanical Design Guide (MDG) for SP5 / EPYC 9005 | **NDA / TIP.** Public AMD Community thread: AMD reply that TDG/MDG “are NDA-restricted and only available through AMD’s Technical Information Portal (TIP) to qualified partners.” | Search hit https://pcforum.amd.com/s/question/0D5Pd00001HFLveKAH/where-are-the-thermal-design-guide-and-mechanical-drawings-for-the-epyc-9005-series-processors (page fetch timed out; title and AMD quote are from the public search snippet). **Do not treat as a pin map.** |
| 58015 EPYC 9004 architecture overview on DAM | https://www.amd.com/content/dam/amd/en/documents/epyc-technical-docs/tuning-guides/58015-epyc-9004-tg-architecture-overview.pdf returned an **AMD Technical Information Portal login splash** when fetched. Same 2P facts are already in A4/T6. | — |

---

## 8. Is there an obvious, written way to scale SP5 2P to 4P?

**No.** Reasoned only from the opened sources:

1. **AMD’s written socket max is 2.** A1: “single- or dual-socket.” A3: Infinity Fabric “in **2P** configurations,” “three or four **links between processors**.” A4: “connect to the **second** processor.” A6/N1/N2: “one or two.” T15: “1P or 2P.” S1: xGMI BIOS “**only applies to a 2P system**.”
2. **xGMI is pairwise.** Figures show two packages and four G-links **between those two**. There is no public 4-node xGMI diagram for SP5. Four G-links on one IOD are accounted for as **all going to the one other socket** (or converted back to PCIe). Using them to reach *two* other sockets would contradict the published 3-vs-4-link **2P** I/O tradeoff (A1, A3, A4).
3. **OEM 2P boards match that pairwise picture.** MZ73-LM2: “4 x16 xGMI3” between CPU0 and CPU1 (O4). H13DSG-OM: xGMI x16 between two SP5 sockets (O1). ASUS K14PP-D24: two SP5 + xGMI (O6). Dell R7625: two CPUs, xGMI up to 64 lanes (O8). None is a 4-socket SP5 motherboard.
4. **SP3 does not supply a hidden 4P recipe.** Naples NUMA (N1) and Milan NUMA (N2) both say **1P or 2P**. No opened AMD SP3 PDF specified 4P, a 4-socket pinout, or a 4-way xGMI map. Searching Dell/HPE/SuperMicro for a public EPYC 4P *SP3* board that publishes such a map did not yield one to open. **Do not invent one.**
5. **The only 4-package AMD board opened is not SP5 EPYC.** H13QSH is **quad MI300A / SH5** (X1–X3). Different socket, different product. It is not a written SP5 2P→4P path.

If a later NDA document (TDG, PPR, SP5 NUMA PDF behind login) said otherwise, that text is **not public** and is **not used here**. Public writing stops at 2P, pairwise xGMI.

---

## 9. What this note does not do

- Does not design, sketch, or imply a 4-socket SP5 motherboard.
- Does not invent G-link ↔ G-link pairing, WAFL maps, or SP5 pin maps.
- Does not invent PE/OAM maps or host-slot maps for the Rev3 chassis.
- Does not touch Gerbers, schematics, or netlists in this tree.
- Does not treat login-gated or NDA titles as readable specs.

**End of sourced note.**

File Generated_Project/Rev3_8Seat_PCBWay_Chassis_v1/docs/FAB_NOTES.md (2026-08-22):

# Fab notes — Rev3 8-seat PCBWay POWER+MECH first article

**Do not upload from this agent.** Eli uploads if he accepts the zip.  
**DO NOT ENERGIZE P48V** until the Molex **1.2 A/contact at 48–59.5 V (2 oz)** write-up is in hand (ticket **167157**).

## What this zip is

Gerbers + drill + IPC-D-356 + pick-and-place for a **12-layer, 2.0 mm, 492 × 372 mm** FR-4 coupon matching the live **2026-08-21** PCBWay guest quote (qty **5**, **ENIG**, **2 oz outer / 1 oz inner**, green soldermask / white silk). Min geometry in the project is **6/6 mil (0.15 mm)** and **0.3 mm** drill — the quoted form.

Silk keeps **DO NOT ENERGIZE P48V**. “DO NOT FABRICATE” is dropped on this first article because POWER+MECH copper DRC is **0 errors** after zone fill. PE / switch balls are **not** routed.

**This zip will not work as a live GPU chassis if sent to PCBWay.** It is sit-only (mech + named P48V). Routing **16× x16 PE** and escaping four **1311-ball** BGAs is a **respin**, not a silk ECO — see `docs/LATE_BIND.md`. The 8× full-width CONCEPT stays **DO NOT FABRICATE**.

## Stackup (planning, matches the quoted coupon)

| Layer | KiCad | Cu | Use |
|---:|---|---:|---|
| 1 | F.Cu | 2 oz | Mezz, local P48V / P12V1 / P3V3, SB175, fuses, bucks |
| 2 | In1.Cu | 1 oz | GND plane |
| 3–4 | In2/In3 | 1 oz | PE reserved (empty this article) |
| 5 | In4.Cu | 1 oz | GND plane |
| 6–7 | In5/In6 | 1 oz | Reserved |
| 8 | In7.Cu | 1 oz | GND plane |
| 9–10 | In8/In9 | 1 oz | Reserved |
| 11 | In10.Cu | 1 oz | GND plane |
| 12 | B.Cu | 2 oz | Reserved / host-stub |

Dielectric thicknesses in the `.kicad_pcb` are evened to ~2.0 mm. PCBWay will issue the signed stack after engineering review.

## Skip-pin / NC

Published OCP v1.0 P48V map **already satisfies Skip Pins**. TEST* / RFU / DO_NOT_USE pads have **no net and no extra copper**. Do **not** add NC pads. Do **not** short them.

## P48V

- Inlet: Anderson **6325G1** housing + **2× 1382** 1/0 AWG contacts (SB175, 175 A / 600 V). PCB landing is on-board (NPTH copper inside Edge.Cuts). Kelvin pads at the star.
- Star net `P48V_STAR` is **not** a board-wide 100 A flood.
- Per seat: Littelfuse **0476015.MR** (15 A, 125 VDC Nano2) then a **local** F.Cu island on the 16 verified Conn0 P48V pads.
- Brick input: Littelfuse **0476002.MR** (2 A, 125 VDC) into THL 40-4812WI.
- **Dell D3000E-S1 is 12 V — never tie to OAM P48V.**
- First populate: seats **0–1** / fuses **F0–F1**. Off-board 48 V is 240 V / 50 A **single-phase** class (DPU-3200-48 class). **Not** RST-5000-48 (3-phase). Not a PCB BOM item.
- Mezz pad-to-pad gap is **0.40 mm** (Molex 0.9 mm pitch). OCP 25 mil (0.64 mm) is held on star/fuse copper. Custom DRC waives vendor pitch on mezz pads only.

## P12V1 / P3V3

- **TRACO THL 40-4812WI**: 18–75 V in, 12 V / 3.35 A / **40 W**. OCP allows P12V1 ≤50 W; this buyable 1×1 module is the first-article cap. Isolated module; primary and secondary returns bonded to board GND.
- **Murata OKI-78SR-3.3/1.5-W36-C**: 3.3 V / 1.5 A / 4.95 W from P12V1 (≤5 W). No GPU multiphase VRM.
- P12V2 is named from v1.0 and is **Unknown / may be NC** — not supplied.

## Switches / host

- **2-module first article** does **not** stuff PM8536. Four **PM8536B-FEI** courtyards stay DNP for the later 8-seat path.
- Legal named host PE: Conn0 OCP `PCIE_*` = `PE_S0_GCD0_x16` + `PE_S1_GCD0_x16` toward the existing host keepout. GCD1 named-only (Conn1 has 0 `PCIE_*`; not S1–S7).
- Host **X11DPH-T**: two GCD0 x16 **fit**; two full-width modules (4× x16) **do not**. No CEM / SlimSAS / MCIO MPN invented. Do not swap the host board.
- Later-seat 16× x16 names remain. No PE tracks this article.

## SMT / mezz attach

16× 688-ball Molex **218910-1115** is **not** a default PCBWay stack. Call it out on the order. Guest form only showed an $88 SMT floor.

## What Eli can upload vs what stays DNP

See `docs/STATUS.md`. Upload the `fab/` zip as a Standard 12L coupon. Do not stuff PM8536. Do not energize P48V. POWER+MECH still cannot run 8 live GPUs without maps.

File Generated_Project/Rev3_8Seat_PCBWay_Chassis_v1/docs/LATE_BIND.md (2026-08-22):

# Pointer — late-bind reservations

**DO NOT ENERGIZE. CONCEPT: DO NOT FABRICATE as live PE.**

Routing 16× x16 PE and four 1311-ball escapes is a **respin**, not a silk ECO. This board will **not** work as a live GPU chassis if sent to PCBWay.

Canonical: [`Generated_Project/Rev3_8Seat_FULLWIDTH_CONCEPT/LATE_BIND.md`](../../Rev3_8Seat_FULLWIDTH_CONCEPT/LATE_BIND.md)

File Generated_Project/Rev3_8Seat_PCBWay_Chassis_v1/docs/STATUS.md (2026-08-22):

# STATUS — Rev3 8-seat PCBWay chassis PCB

**Tree:** `Generated_Project/Rev3_8Seat_PCBWay_Chassis_v1/`  
**Date:** 2026-08-22  
**Pin map:** `22_Pinmap_Research/extracted/OAM_v1.0_OCP_Generic_Pin_Map.csv` (1376 named pads). xlsx in `22_Pinmap_Research/downloads/` wins on mismatch; this generator consumes the CSV (P3V3 = Conn0 C1/C2 checked). **v1.x only.** r2.0 is UNUSABLE.

**DO NOT ENERGIZE P48V.** POWER+MECH first-article Gerbers are in `fab/`. **Do not upload from this agent.** Eli uploads if he accepts the zip.

Labels: **Verified** / **Inferred** / **Unknown**. Do not treat Inferred as a pin assignment.

This tree is the **Chamber B OAM chassis PCB only** (8-seat OAM carrier). It is **not** a motherboard. Do **not** swap or design an X11/Xeon host board. It must stay compatible with Eli’s 2026-08-21 sheet. It does **not** shop GPUs, 48 V shelves, cooling loops, or a whole-system cart.

**First-article target:** seats **0–1** (2 modules) on this same 8-seat PCB. **Without an AMD overlay, “2× MI250X” on this zip means two modules can sit and at most GCD0 on each can be targeted (2 GCDs) — not 2 modules at full width (4 GCDs).** Host **X11DPH-T** (3× x16 + 4× x8): two GCD0 x16 **fit**; two full-width modules **do not**. Later-seat 8-wide names stay. POWER+MECH: still cannot run live GPUs without maps + Molex current write-up. **DO NOT ENERGIZE.**

Regenerate (do not hand-edit pad nets):

```
python3 Generated_Project/Rev3_8Seat_PCBWay_Chassis_v1/tools/generate_from_v10_pinmap.py
```

---

## Compatibility vs the sheet

| Sheet item | On this PCB? | Fits / does not |
|---|---|---|
| 8× OAM KOZ 103×166 mm, 16× Molex **218910-1115**, 32× M3.5 NPTH φ3.9 mm | **Yes** (this board) | **Fits.** 4×2 tiling **412×332 mm** (Inferred) on outline **492×372 mm**. |
| Board in Chamber B next to E-ATX **304.8×330.2 mm** | Mechanical neighbour, not a part | **Fits as a neighbour.** Chassis PCB 492×372 can sit in Chamber B beside the host. Coolers are **not** on this PCB. |
| 8× MI250X when modules exist | 8 electrically designed seats | **Later-seat names kept.** Chassis can still sit/wire 8× named x16. **This host cannot LIGHT 8× full-width** (~80 vs 256 DS). Not the first-article target. |
| SuperMicro **X11DPH-T** (3× Gen3 x16 + 4× Gen3 x8) | **Not on this PCB** | **Fits as the host.** First-article keepout: **two** named x16 (`PE_S0_GCD0_x16` + `PE_S1_GCD0_x16`). Two GCD0 x16 **fit**. Two full-width modules (4× x16) **do not**. **No CEM/MCIO MPN invented.** |
| First stuffing **2×** MI250X (**P41933-001**) | Seats **0–1** | **Stated first-article target.** Two modules can **sit**. At most **GCD0** on each can be **named toward the host keepout** (2 GCDs). **Not** 2× full-width (4 GCDs). GPUs **do-not-order**. Same PCB for 4 then 8. |
| 2× Xeon Gold **6230** | **Not on this PCB** | Host CPUs. Compatible as the locked host SKU. |
| **NH-D9 DX-3647** (NOT U14S) | **Not on this PCB** | **Fits the sheet.** U14S collides on dual 3647 — do not use U14S. Coolers live on the host, not here. |
| 1000 W ATX/EPS | **Not on this PCB** | **Host only.** Do not treat it as OAM P48V. |
| Chamber A desk **mATX B550M 244×244** | **Not on this PCB** | Chamber A. Do not put it on the chassis. |
| Dell **D3000E-S1** | **Not on this PCB** | **Does not fit as GPU P48V.** It is **12 V CRPS**. Do not tie OAM P48V to it. |
| Molex **218910-1115** ×16 | **Yes** | **Fits** the OCP 5.00 mm stack. Street ~$50–$96 ea. **Do not order** from this tree. |
| **PM8536B-FEI** ×4 | Courtyard **DNP** | **Not stuffed for 2-module first article.** Kept for later 8-seat path. Ball map not public. |
| xGMI / Infinity Fabric S1–S7 | No net | **Does not fit** (overlay Unknown). Not routed. |
| Custom cold plate / GPU HS | **Not on this PCB** | **Do not shop** onto this BOM. |

---

## What 2× can and cannot do (this zip)

Hypothesis **verified** from `22_Pinmap_Research/extracted/OAM_v1.0_OCP_Generic_Pin_Map.csv` (1376 pads) + `OAM_Pin_list_Rev1.0.csv`:

| Fact | Evidence | Label |
|---|---|---|
| Conn0 `PCIE_TX/RX0–15` P/N = **64 pads**, lanes 0–15 | Generic pin map; pin list `PETp/n` + `PERp/n [15:0]` = “PCIe or equivalent **host link**”, Conn0, Required | **Verified** OCP names. Architectural name: `PE_Sn_GCD0_x16`. |
| Conn1 `PCIE_*` count | **0** | **Verified** |
| Conn1 `S7_*` = SERDES_7 reserved link, 64 pads | Pin list “SerDes Reserved Link”; interconnect “defined by Module and System integrator” | **Named, no net.** Not a legal GCD1 PE map. |
| S1–S7 | 448 SerDes pads, **no net** | **Verified** unmapped on this chassis. |

**Can (first article, seats 0–1):**

- Two OAM modules **sit** (KOZ, Molex, M3.5 NPTH, named P48V after F0/F1, P12V1, P3V3, GND).
- At most **GCD0** on each is a legal named host PE (`PE_S0_GCD0_x16`, `PE_S1_GCD0_x16`) toward the existing host keepout — **2 GCDs**, not 4.
- Those two x16 names **fit** X11DPH-T’s 3× x16 slots **as a lane budget**. No connector MPN is placed.

**Cannot:**

- 2 modules at **full width** (4 GCDs). GCD1 pins **Unknown**; not assigned to S1–S7.
- Light even the 2 GCD0 links: Molex 1.2 A/contact **OPEN**, no host cable MPN, PE **not routed**, switches **DNP**.
- Invent CEM / Molex-to-CEM / MCIO-on-carrier without a cited public footprint **and** without inventing the OAM↔MCIO map. None placed. SuperMicro CBL-MCIO is a UBB cable, not this host.
- Feed P48V from RST-5000-48 (3-phase) on a 240 V / 50 A **single-phase** wall. Off-board 48 V stays DPU-3200-48 class, not a PCB BOM item.
- Use OAM r2.0 (P3V3 = Conn0 C1/C2 only).

---

## 8× full-width CONCEPT (ideas only — DO NOT FABRICATE)

Eli asked for an **8× MI250X full-width chassis CONCEPT** to build ideas on. It is **not** this zip, **not** a new CPU board, and **not** a live PE design.

Canonical doc: [`Generated_Project/Rev3_8Seat_FULLWIDTH_CONCEPT/CONCEPT.md`](../../Rev3_8Seat_FULLWIDTH_CONCEPT/CONCEPT.md) (also `docs/CONCEPT_8x_FULL_WIDTH.md`).

| | |
|---|---|
| What | 8 seats, 16 named x16 PE, four DNP PM8536 courtyards already on this board, xGMI as **boxes + port names** (`XGMI_Sn_P*`) only |
| Host | Still **X11DPH-T** (~80 lanes). **This CONCEPT cannot light 8× full-width on that host** (256 DS). 4× named US x16 = 64 **fit as an uplink budget only**. |
| Do not | Invent overlay pads, PM8536 balls, CEM/MCIO, r2.0, S1–S7, TEST\*/RFU/DO_NOT_USE, or a cable MPN |
| Silk / comments | CONCEPT / DO NOT FABRICATE on **Cmts.User** (not fab silk). **Do not claim DRC-clean live PE.** **DO NOT ENERGIZE.** |

Lane arithmetic (not a pinout): 256 DS + 64 US vs 4×96 = 384. Each SW hypothesis: 2 seats × 2 GCD × x16 DS + one x16 US.

---

## Late bind (maps later — not a silk ECO)

Eli wants the chassis ready so overlay / switch balls / host-plug MPNs need only small changes. **Honest bound:** named nets, DNP courtyards, host keepout, and comment-layer corridors are reserved. **Routing 16× x16 PE and escaping four 1311-ball BGAs is a copper respin, not a silkscreen ECO.** This zip will **not** work as a live GPU chassis if sent to PCBWay.

Canonical: [`Generated_Project/Rev3_8Seat_FULLWIDTH_CONCEPT/LATE_BIND.md`](../../Rev3_8Seat_FULLWIDTH_CONCEPT/LATE_BIND.md) (also `docs/LATE_BIND.md`).

| Missing doc | Already reserved | Later spin must add |
|---|---|---|
| **Overlay** | GCD0 = public Conn0 `PCIE_*` named on every seat. GCD1 **named-only**. S1–S7 **no net**. | Assign GCD1 from overlay; **route**. No guessed tracks now. |
| **PM8536** | Four DNP 40 mm courtyards SW0–SW3. | Footprint + **escape** when a public/NDA map exists. Finer than 6/6 mil; requote. |
| **Host plug** | Keepout + named US x16 (`PE_SWk_US_x16`) and first-article `PE_S0/S1_GCD0_x16`. | Place a **real** MPN. No CEM/MCIO invented now. |
| **Molex 1.2 A** | Silk DO NOT ENERGIZE. Ticket 167157 OPEN. | Off-board write-up. Blocks energize. |
| **Cooling** | Not on this PCB. | Off-board. Do not shop onto the chassis BOM. |
| **2→4→8** | Same **492×372** outline, 8 seats, star + per-seat fuses. | Populate more seats. Still no live PE until routes exist. |

Comment-layer corridors (Dwgs.User / Cmts.User, **no copper**): seats 0–1 GCD0 toward host keepout and toward SW0. Not fake pins.

---

## What this tree is

8 electrically designed OAM seats on one **12-layer, 2.0 mm** FR-4 chassis. **First article = seats 0–1.** Later 4- and 8-seat names stay on the same copper.

| | |
|---|---|
| Outline | **492 × 372 mm** (fits PCBWay advanced finished ML **508 × 600**) |
| 8-KOZ floor | **412 × 332 mm** = 4×2 of 103×166 mm |
| Seat grid | col pitch 103 mm, row pitch 166 mm. Row 0 (Y=20): seats **0 1 2 3**. Row 1 (Y=186): seats **4 5 6 7**. |
| Connectors | **16×** Molex **218910-1115** (2 per seat), rot 180 **Inferred** |
| Holes | **32×** M3.5 NPTH φ3.9 mm (Fig 2), 8 mm MIN land |
| Layers | **12L 2.0 mm** stuffed-switch **prefer** (guest **$2237.90 + $68.43 DHL = $2306.33**, 14–15 days). **8L 2.0 mm $832.74** is the DNP-switch / mezz+power prefer. 16L Advanced **$2937.84**. |
| P48V | Anderson **6325G1** + 2× **1382** → star + Kelvin → per-seat **0476015.MR** 15 A → **local F.Cu pours**. **Not** a 100 A flood. |
| P12V1 / P3V3 | **THL 40-4812WI** (40 W from 48 V) + **OKI-78SR-3.3/1.5-W36-C** (4.95 W from P12V1). No GPU VRM. |
| Switches | **U_SW0–U_SW3** **PM8536B-FEI DNP** (later path; **not** stuffed for 2-module first article). |
| Host region | X=452–492 mm strip. First-article silk: **two** x16 names toward keepout. **No CEM/MCIO invented.** |
| PE names | First article: `PE_S0_GCD0_x16` + `PE_S1_GCD0_x16`. Later seats keep `PE_S2…S7_GCD0/GCD1_x16`. GCD1 = **named only**. |

Populate path: **2** (seats 0–1, no stuffed switch) → **4** (seats 0–3) → **8** (all seats + SW0–SW3). Same copper.

---

## Verified (this named-net chassis)

| Item | Evidence |
|---|---|
| 1376 named pads, Conn0+Conn1 688 each | v1.0 CSV row count |
| P3V3 = Conn0 C1, C2 (2 pads) | v1.0 map; matches v1.5 Table 4. r2.0 (P3V3=6) UNUSABLE |
| Shared OCP rails `P48V` `P12V1` `P12V2` `P3V3` `GND` | v1.0 names on all 8. **No VRM.** P12V2 **Unknown / may be NC**. |
| P48V: 16 Conn0 pads/seat | H59 K59 H60 K60 H61 J61 K61 L61 H62 J62 K62 L62 H63 J63 H64 J64 |
| Molex 218910-1115 CSA **60 V** at OCP P48V | Written **2026-08-18** Molex engineering via Brian Park / ticket **167157**, COFC **80170713**. Eli ack **2026-08-19**. Published OCP P48V map **already satisfies Skip Pins** — do **not** add extra NC pads. |
| Connector MPN 218910-1115, hermaphroditic, 5.00 mm | Farnell 2189101115; OCP v1.5 §5/§6.2 |
| Module PCB 102×165; KOZ 103×166; M3.5 φ3.9 | OCP v1.5 Fig 2 / Fig 14 |
| PM8536B-FEI package | Microchip PFX: 96-lane Gen3, **1311-ball 37.5×37.5 mm FCBGA, 1.0 mm pitch**. PCBWay can assemble 1.0 mm without HDI. ~$460–475, ~18 wk. PRIMARY DNP ×4. |
| Conn0 host PE | 64 `PCIE_*` pads, lanes 0–15. Pin list: PETp/n + PERp/n “PCIe or equivalent host link”. **Only legal named host PE.** |
| Conn1 PCIE | **0** pads. S7_* = SERDES_7 reserved, **no net**. |
| X11DPH-T lane budget | SuperMicro: 3× Gen3 x16 + 4× Gen3 x8 = **80** Gen3 lanes. Two GCD0 x16 **fit**. Two full-width modules (4× x16) **do not**. DRAM/PMem does **not** add lanes. |
| HOST_PWRGD | OCP: Power Enable when rails in spec. ≥100 ms after MODULE_PWRGD (v1.5). |
| PCBWay guest quotes 2026-08-21, 492×372, qty 5, ENIG, 2 oz outer / 1 oz inner (12L/16L) | See `PCBWAY.md`. **Prefer 12L 2.0 mm stuffed-switch: PCB $2237.90 + DHL $68.43 = $2306.33**, 14–15 days (four PM8536 DNP courtyards; this article does not stuff them). **Prefer 8L 2.0 mm DNP-switch: $832.74 + $68.43**. Caveat: quotes are **6/6 mil + 0.3 mm hole**; 1.0 mm 1311-ball escape will cost more. SMT 16× 688-ball Unknown ($88 floor). **Do not upload.** |

### Pad accounting (one 688+688 map; PCB instantiates it eight times)

| Class | Pads / map | All 8 seats |
|---|---:|---|
| `power_shared` | 728 | named `P48V`/`P12V1`/`P12V2`/`P3V3`/`GND` |
| `pcie_stub` | 64 | Conn0 16-lane PCIE = `PE_Sn_GCD0_x16`. First article: seats 0–1 toward host keepout. GCD1 named-only. **No CEM.** |
| `clock_reset` | 16 | per-seat REFCLK / PERST# / HOST_PWRGD (+ other OCP clock/reset names) |
| `mgmt_stub` | 17 | named (SMBus etc.). Overlay still Unknown. |
| `ocp_sideband` | 19 | named; ID/CONFIG resistors **not placed** |
| `module_output_do_not_drive` | 2 | PVREF. **Never drive.** |
| `serdes_named_not_routed` | 448 | **No net.** No xGMI. SERDES_7 as GCD1 PE is **Inferred**, not routed. |
| `unmapped_nc` | **59** | TEST*/RFU/DO_NOT_USE. **No net.** |

Seat 0 connector centres (match Rev2 2-seat): Conn0 **(71.5, 154.0)**, Conn1 **(71.5, 52.0)** mm.

---

## Inferred

| Item | Basis | Do not treat as |
|---|---|---|
| 8-GPU floor **412 × 332 mm** | 4×2 tiling of 103×166 mm KOZ | A Universal Baseboard drawing |
| 20 mm service margin + 40 mm host strip → **492 × 372 mm** | Planning envelope | A fab panel drawing or CEM connector |
| Footprint rotation **180°** | Fig 2 PIN A3 on +X vs candidate land A3 at x=−29.45 | Proven module↔baseboard silk until overlay-checked |
| Four 40 mm PM8536 courtyards in the 40 mm host strip | SW0–SW3 stacked in Y; 12 V brick moved south of SW3 | A stuffed BGA pinout |
| Calling Conn0 PCIE “GCD0” | OCP host-link name + dual-GCD public fact; overlay still Unknown | AMD pin assignment |
| First-article host path = two Conn0 x16 toward keepout | Lane budget vs X11DPH-T 3× x16 | A CEM/MCIO cable or PE-to-slot map |
| GCD1 = Conn1 SERDES_7 | OAM v1.5 “second PE x16 may be SERDES_7” | Proven MI250X mapping |

---

## Unknown (blocking energize / overlay / order)

| Item | Status |
|---|---|
| AMD MI250X 688-pad overlay | **Unknown** (NDA) |
| Which S1–S7 are xGMI / Infinity Fabric | **Unknown**. **No net.** |
| Dual-GCD host PCIe 1×16 vs 2×8 / `PE_BIF[1:0]` | **Unknown** |
| Host connector in the silk REGION | **Unknown**. Not invented. |
| P12V2 required on 48 V MI250X | **Unknown**. Do not short to P12V1. |
| SMBus slave / FRU / PMBus map | **Unknown**. Do not invent 0x50. |
| HOST_PWRGD delays vs rail windows | AMD timing **Unknown** (OCP ≥100 ms note only) |
| LINK_CONFIG[4:0] MI250X coding | **Unknown** |
| PIN A3 footprint rotation 180° | **Inferred** |
| 1.2 A per used 218910-1115 power contact at 48–59.5 V (2 oz) | **OPEN** (ticket 167157 follow-up) |
| skip/void is NC on the same MPN | **OPEN** (same follow-up) |

---

## P48V — DO NOT ENERGIZE

| Item | Status |
|---|---|
| Dell D3000E-S1 | **Verified 12 V CRPS**. Not GPU P48V. Never mix. |
| OCP P48V window | **Verified** 44–59.5 V |
| Molex 218910-1115 catalog line | Still prints 30 V; **written CSA 60 V** at OCP P48V 2026-08-18 (COFC 80170713) |
| Skip Pins | Published OCP P48V assignment **already satisfies**; no extra NC pads |
| 1.2 A/contact at 48–59.5 V, 2 oz | **OPEN** |
| P48V copper | **Local per-seat F.Cu pours** + SB175 star. **Not** a board-wide 100 A plane |
| Off-board 48 V PSU / shelf | **Not a PCB BOM item.** 240 V / 50 A **single-phase** wall class (DPU-3200-48 class). **Not** RST-5000-48 (3-phase). First populate: seats 0–1 / F0–F1 only. |

Voltage/skip-pin is no longer a 30 V catalog brick wall. **Current-rating follow-up still blocks energize.** Keep silk **DO NOT ENERGIZE P48V**.

---

## What Eli can upload vs what stays DNP

| Eli can upload / buy onto this PCB | Stays DNP / not this zip |
|---|---|
| `fab/Rev3_8Seat_PCBWay_12L_492x372_qty5_gerbers.zip` (Gerbers, drill, IPC-356, PnP, FAB_NOTES, BOM, top preview) | **Sit-only POWER+MECH.** Will **not** work as a live GPU chassis. **Do not upload from this agent.** |
| 12L 2.0 mm 492×372 ENIG 2 oz/1 oz green/white qty 5 — guest **$2237.90 + $68.43 DHL** | 8L DNP-switch coupon is cheaper if he never stuffs switches |
| 16× **218910-1115**, 32× M3.5 NPTH, Anderson **6325G1** + **2× 1382**, **0476015.MR** ×8, **0476002.MR**, **THL 40-4812WI**, **OKI-78SR-3.3/1.5-W36-C** | **PM8536B-FEI** ×4 (courtyard only; ball map not public) |
| Local P48V / P12V1 / P3V3 copper + GND planes + star/fuses | PE / REFCLK / PERST# **tracks** (named, not routed) |
| Silk **DO NOT ENERGIZE P48V** | Host CEM connector (keepout only; no MPN invented) |
| Skip-pin NC (TEST*/RFU/DO_NOT_USE have no net) | AMD overlay, xGMI S1–S7, PVREF drive, D3000E-S1 |

**Energize is still blocked** on Molex 1.2 A/contact (ticket 167157). First article is POWER+MECH **sit-only**. Routing 16× x16 / four BGA escapes is a **respin** — see `LATE_BIND.md`.

---

## KiCad CLI

See `docs/kicad_reports/` (KiCad **9.0.9**). ERC dangling hierarchical labels are expected. DRC on fabricated copper: **0 errors**, **38** warnings (lib footprint mismatch, leftover silk at SB175, isolated copper). Unconnected PE / REFCLK / PERST# nets are expected (four DNP switches). Do not “Update PCB from Schematic”.

---

## Still open (not a reason to withhold the zip)

1. **Molex 1.2 A/contact at 48–59.5 V (2 oz)** — silk stays DO NOT ENERGIZE.
2. **AMD overlay** still Unknown. Do not invent it.
3. **PM8536B-FEI** ×4 DNP until a public/legal ball map exists. 1.0 mm escape will need finer than **6/6 mil** and a requote.
4. **No CEM / MCIO host MPN** (deliberate). Two GCD0 x16 fit the host; two full-width modules do not.
5. **218910-1115 mezz attach** is a factory process.
6. **PIN A3** rotation 180° still Inferred.
7. P12V1 first-article module is **40 W** (THL 40-4812WI) vs OCP ≤50 W.
8. GCD1 x16 pins remain **Unknown**. `PE_Sn_GCD1_x16` is a name, not a pad map. First article cannot run 2 live GPUs without maps + Molex current.

**Do not energize OAMs. Do not stuff the DNP switches on this article.**

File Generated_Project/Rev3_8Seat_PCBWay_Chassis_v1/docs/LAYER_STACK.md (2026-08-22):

# Layer stack — planning only (not a PCBWay-signed stackup)

**Generated KiCad:** **12 layer, 2.0 mm** stuffed-switch **target** (8× electrically designed seats + four DNP **PM8536B-FEI PRIMARY**, full-width capable). Plan **12–16L, not 4**. PCBWay can assemble 1.0 mm without HDI.  
**Documented cheaper option:** **8 layer, 2.0 mm** DNP-switch / mezz+power-only — **not** the 8×-running target.  
**PEX8780-AB80BI G** is a cheaper 80-lane alt in **docs only** — not placed.  
**DO NOT ENERGIZE P48V.** Fab zip is in `fab/`. Do not upload from this agent.

PCBWay: 12L is inside Standard 1–14. Outline 492×372 < advanced finished ML **508×600**. Guest quotes 2026-08-21 used **2 oz outer / 1 oz inner**, ENIG, qty 5. See `PCBWAY.md`.

Thickness sum below is **planning**. Dielectric thicknesses are evened to hit ~2.0 mm with 2 oz outer (70 µm) and 1 oz inner (35 µm). A real stackup comes from PCBWay after an engineering review (especially for 1.0 mm-pitch 1311-ball escape).

## 12L 2.0 mm — stuffed-switch TARGET (this `.kicad_pcb`)

| Layer | KiCad name | Type | Cu | Assignment |
|---:|---|---|---:|---|
| 1 | F.Cu | signal | 2 oz | Mezz SMD, **local P48V pours**, SB175, silk |
| 2 | In1.Cu | power | 1 oz | **GND** plane |
| 3 | In2.Cu | signal | 1 oz | PE / switch reserved |
| 4 | In3.Cu | signal | 1 oz | PE / switch reserved |
| 5 | In4.Cu | power | 1 oz | **GND** plane |
| 6 | In5.Cu | signal | 1 oz | Reserved |
| 7 | In6.Cu | signal | 1 oz | Reserved |
| 8 | In7.Cu | power | 1 oz | **GND** plane |
| 9 | In8.Cu | signal | 1 oz | Reserved |
| 10 | In9.Cu | signal | 1 oz | Reserved |
| 11 | In10.Cu | power | 1 oz | **GND** plane |
| 12 | B.Cu | signal | 2 oz | Reserved / host-stub |

Guest **8L 2.0 mm $832.74** (qty 5, 7–8 days) is the **preferred 8L / no-switch / DNP-switch** coupon if all four PM8536 stay DNP; stuffing them is a **12–16L** job.

**Hypothesis discarded:** a board-wide inner/outer **P48V plane** carrying ~100 A. Replaced by SB175 star + per-seat fuse keepouts + **local** 2 oz F.Cu pours on the 16 verified Conn0 P48V pads.

Inner GND planes are via-stitched at the inlet, bucks, and around each mezz (not via-in-pad).

## 8L 2.0 mm — cheaper DNP-switch option (not generated)

| Layer | Type | Cu | Assignment |
|---:|---|---:|---|
| 1 | signal | 2 oz | Mezz + local P48V + SB175 |
| 2 | GND | 1 oz | GND |
| 3 | signal | 1 oz | Reserved |
| 4 | GND | 1 oz | GND |
| 5 | signal | 1 oz | Reserved |
| 6 | GND | 1 oz | GND |
| 7 | signal | 1 oz | Reserved |
| 8 | signal | 2 oz | Reserved |

Use only if all four PM8536 stay DNP forever and PE is not fanned out. **Not** the 8×-running target. Do not treat this as the PEX8780 stuffed stack — PEX8780 is docs-only.

## Rules of thumb used

- P48V star/fuse copper clearance **0.64 mm** (OCP UBB v1.5 >40 V internal 25 mil). Mezz pad islands use **0.20 mm** (vendor 0.9 mm pitch). Custom DRC waives vendor pitch on mezz pads only.
- GND zone clearance **0.25 mm**.
- Min geometry in this zip **6/6 mil (0.15 mm)** and **0.3 mm** drill — the quoted form. A 1.0 mm 1311-ball PM8536 escape will need finer than 6/6 and a requote; switches stay DNP on this article.
- Inner GND planes are via-stitched at KOZ interiors, bucks, and the P12V1/P3V3 alley (not via-in-pad).

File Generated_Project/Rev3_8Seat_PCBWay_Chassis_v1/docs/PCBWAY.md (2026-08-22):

# PCBWay target (planning + first-article zip)

**Date:** 2026-08-21 quotes; fab zip generated 2026-08-22.  
**Source of limits:** https://www.pcbway.com/capabilities.html (Standard PCB + Advanced PCB tables).  
**Guest quotes:** live PCBWay guest cart 2026-08-21, outline **492 × 372 mm**, **qty 5 minimum** (**qty 1 rejected**), **2 oz outer OK**, **ENIG**.  
**Prefer 2.0 mm thickness.**  
**Do not upload from this agent.** Eli uploads `fab/Rev3_8Seat_PCBWay_12L_492x372_qty5_gerbers.zip` if he accepts it.

## Target coupon

## Target coupon

| Item | This stub | PCBWay capability used | Status |
|---|---|---|---|
| Outline | **492 × 372 mm** | Standard multilayer max **560 × 1150 mm**; advanced finished multilayer **508 × 600 mm** (normal process) | **Fits both.** |
| 8-KOZ reserve | **412 × 332 mm** | n/a (mechanical) | **Inferred** 4×2 tiling of verified 103×166 mm KOZ. |
| Margin | 20 mm service + 40 mm host-stub strip | n/a | Host strip holds 4× 37.5 mm PM8536 courtyards stacked in Y + cable keepout. |
| Layers (**no-switch / DNP-switch**) | **8L 2.0 mm** preferred 8L stack | Standard | Live guest quote below. Mezz + local P48V only. |
| Layers (**stuffed-switch**) | **12L 2.0 mm Standard** preferred (four PM8536B-FEI DNP courtyards) | Standard 1–14; 16L is Advanced | **Live guest quote.** Generated KiCad is **12L 2.0 mm**. |
| Copper | **2 oz outer** (quotes); 1 oz inner on 12L/16L | Outer 1–8 oz; inner 1–4 oz (4–10 L) | Local P48V pours live on **F.Cu 2 oz**. |
| Finish | ENIG **in the guest quote**; still **TBD** for attach | HASL / ENIG / OSP | Do not pick until Molex attach process is known. |
| Qty | Guest form **qty 5 min** (qty 1 rejected). **Not ordered.** | — | |

## Live 4L / 8L guest quotes 2026-08-21 (do not upload / do not order)

All: **492 × 372 mm**, **qty 5**, **ENIG**, **2 oz outer**. Prefer **2.0 mm**.

| Stack | PCB | DHL | Total | Days | Use |
|---|---:|---:|---:|---|---|
| 4L 1.6 mm | $528.88 | $57.23 | $586.11 | 4–5 | Too thin for 8 mezz + future switch. |
| 4L 2.0 mm | $501.50 | $68.43 | $569.93 | — | Cheaper than 4L 1.6. Form reset track/space to **8/8 mil**. Still not the switch stack. |
| **8L 2.0 mm** | **$832.74** | **$68.43** | **$901.17** | **7–8** | **Preferred 8L stack. No-switch / DNP-switch / mezz+power.** |
| 8L 1.6 mm | $1498.93 | — | — | 12–13 | **Avoid.** |

SMT for **16× 688-ball Molex** is **Unknown** (form only showed an **$88 floor**). Mezz attach is not a default PCBWay stack.

## Live 12L / 16L guest quotes 2026-08-21 (do not upload / do not order)

All: **492 × 372 mm**, **qty 5**, **ENIG**, **2 oz outer / 1 oz inner**. Prefer **12L 2.0 mm** as the stuffed-switch stack (four PM8536B-FEI DNP courtyards). Prefer **8L 2.0 mm ($832.74)** as the DNP-switch / mezz+power-only stack.

| Stack | PCB | DHL | Total | Days | Use |
|---|---:|---:|---:|---|---|
| **12L 2.0 mm Standard** | **$2237.90** | **$68.43** | **$2306.33** | **14–15** | **Preferred stuffed-switch. Generated KiCad.** |
| 12L 1.6 mm Standard | $2194.09 | $57.23 | $2251.32 | — | Prefer 2.0 mm. |
| 16L 2.0 mm Advanced | $2937.84 | $68.43 | $3006.27 | 20–21 | Standard form max **14L**; 16L is Advanced. |
| 16L 1.6 mm Advanced | $2937.84 | $57.23 | $2995.07 | — | Prefer 2.0 mm if 16L ever needed. |

**Caveat:** these quotes are **6/6 mil + 0.3 mm hole**. A **1.0 mm-pitch 1311-ball** PM8536 escape likely needs finer rules and will cost more.

## Old MFC cart is UNRELATED

A previous qty-**5** MFC/PCBWay-style cart for a **220 × 120 mm** board is **not this coupon**.

- Do **not** reuse that quote, that qty, or that outline.
- This board is **492 × 372 mm**, 16× 218910-1115, 8 electrically designed seats.
- **Do not upload from this agent.** Eli uploads the `fab/` zip if he accepts it.

## Layer stack

See `docs/LAYER_STACK.md`.

- **8L 2.0 mm ($832.74)** = preferred DNP-switch / mezz+power-only.
- **12L 2.0 mm Standard ($2237.90 + $68.43 DHL = $2306.33)** = preferred stuffed-switch (generated KiCad).

**Do not upload. Do not order from this agent.**

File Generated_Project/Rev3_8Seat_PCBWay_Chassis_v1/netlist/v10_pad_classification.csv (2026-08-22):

connector | pad | v10_signal | class | oam0_net | oam1_net | oam2_net | oam3_net | oam4_net | oam5_net | oam6_net | oam7_net | wired_on_all_8 | notes
Conn0 | C1 | P3V3 | power_shared | P3V3 | P3V3 | P3V3 | P3V3 | P3V3 | P3V3 | P3V3 | P3V3 | yes | OCP-named power/ground on all 8 seats. P48V = local per-seat pour on 16 Conn0 pads after fuse keepout; NOT a 100A flood. P12V2 Unknown/may be NC. Do not tie P48V to D3000E-S1 (12 V). DO NOT ENERGIZE.
Conn0 | D1 | PERST# | clock_reset | OAM0_PERST# | OAM1_PERST# | OAM2_PERST# | OAM3_PERST# | OAM4_PERST# | OAM5_PERST# | OAM6_PERST# | OAM7_PERST# | yes
Conn0 | E1 | GND | power_shared | GND | GND | GND | GND | GND | GND | GND | GND | yes | OCP-named power/ground on all 8 seats. P48V = local per-seat pour on 16 Conn0 pads after fuse keepout; NOT a 100A flood. P12V2 Unknown/may be NC. Do not tie P48V to D3000E-S1 (12 V). DO NOT ENERGIZE.
Conn0 | F1 | RFU | unmapped_nc |  |  |  |  |  |  |  |  | no | Named in v1.0 but AMD overlay unknown or reserved; no copper
Conn0 | G1 | PVREF | module_output_do_not_drive | OAM0_PVREF | OAM1_PVREF | OAM2_PVREF | OAM3_PVREF | OAM4_PVREF | OAM5_PVREF | OAM6_PVREF | OAM7_PVREF | yes | Module output. Never drive from carrier. Per-OAM nets. Do not short seats together.
Conn0 | H1 | HOST_PWRGD | clock_reset | OAM0_HOST_PWRGD | OAM1_HOST_PWRGD | OAM2_HOST_PWRGD | OAM3_HOST_PWRGD | OAM4_HOST_PWRGD | OAM5_HOST_PWRGD | OAM6_HOST_PWRGD | OAM7_HOST_PWRGD | yes
Conn0 | J1 | GND | power_shared | GND | GND | GND | GND | GND | GND | GND | GND | yes | OCP-named power/ground on all 8 seats. P48V = local per-seat pour on 16 Conn0 pads after fuse keepout; NOT a 100A flood. P12V2 Unknown/may be NC. Do not tie P48V to D3000E-S1 (12 V). DO NOT ENERGIZE.
Conn0 | C2 | P3V3 | power_shared | P3V3 | P3V3 | P3V3 | P3V3 | P3V3 | P3V3 | P3V3 | P3V3 | yes | OCP-named power/ground on all 8 seats. P48V = local per-seat pour on 16 Conn0 pads after fuse keepout; NOT a 100A flood. P12V2 Unknown/may be NC. Do not tie P48V to D3000E-S1 (12 V). DO NOT ENERGIZE.
Conn0 | D2 | WARMRST# | clock_reset | OAM0_WARMRST# | OAM1_WARMRST# | OAM2_WARMRST# | OAM3_WARMRST# | OAM4_WARMRST# | OAM5_WARMRST# | OAM6_WARMRST# | OAM7_WARMRST# | yes
Conn0 | E2 | GND | power_shared | GND | GND | GND | GND | GND | GND | GND | GND | yes | OCP-named power/ground on all 8 seats. P48V = local per-seat pour on 16 Conn0 pads after fuse keepout; NOT a 100A flood. P12V2 Unknown/may be NC. Do not tie P48V to D3000E-S1 (12 V). DO NOT ENERGIZE.
Conn0 | F2 | RFU | unmapped_nc |  |  |  |  |  |  |  |  | no | Named in v1.0 but AMD overlay unknown or reserved; no copper
Conn0 | G2 | PVREF | module_output_do_not_drive | OAM0_PVREF | OAM1_PVREF | OAM2_PVREF | OAM3_PVREF | OAM4_PVREF | OAM5_PVREF | OAM6_PVREF | OAM7_PVREF | yes | Module output. Never drive from carrier. Per-OAM nets. Do not short seats together.
Conn0 | H2 | MODULE_PWRGD | clock_reset | OAM0_MODULE_PWRGD | OAM1_MODULE_PWRGD | OAM2_MODULE_PWRGD | OAM3_MODULE_PWRGD | OAM4_MODULE_PWRGD | OAM5_MODULE_PWRGD | OAM6_MODULE_PWRGD | OAM7_MODULE_PWRGD | yes
Conn0 | J2 | GND | power_shared | GND | GND | GND | GND | GND | GND | GND | GND | yes | OCP-named power/ground on all 8 seats. P48V = local per-seat pour on 16 Conn0 pads after fuse keepout; NOT a 100A flood. P12V2 Unknown/may be NC. Do not tie P48V to D3000E-S1 (12 V). DO NOT ENERGIZE.
Conn0 | A3 | MANF_MODE# | ocp_sideband | OAM0_MANF_MODE# | OAM1_MANF_MODE# | OAM2_MANF_MODE# | OAM3_MANF_MODE# | OAM4_MANF_MODE# | OAM5_MANF_MODE# | OAM6_MANF_MODE# | OAM7_MANF_MODE# | yes
Conn0 | B3 | GND | power_shared | GND | GND | GND | GND | GND | GND | GND | GND | yes | OCP-named power/ground on all 8 seats. P48V = local per-seat pour on 16 Conn0 pads after fuse keepout; NOT a 100A flood. P12V2 Unknown/may be NC. Do not tie P48V to D3000E-S1 (12 V). DO NOT ENERGIZE.
Conn0 | C3 | PWRBRK# | clock_reset | OAM0_PWRBRK# | OAM1_PWRBRK# | OAM2_PWRBRK# | OAM3_PWRBRK# | OAM4_PWRBRK# | OAM5_PWRBRK# | OAM6_PWRBRK# | OAM7_PWRBRK# | yes
Conn0 | D3 | GND | power_shared | GND | GND | GND | GND | GND | GND | GND | GND | yes | OCP-named power/ground on all 8 seats. P48V = local per-seat pour on 16 Conn0 pads after fuse keepout; NOT a 100A flood. P12V2 Unknown/may be NC. Do not tie P48V to D3000E-S1 (12 V). DO NOT ENERGIZE.
Conn0 | E3 | UART_TXD | mgmt_stub | OAM0_UART_TXD | OAM1_UART_TXD | OAM2_UART_TXD | OAM3_UART_TXD | OAM4_UART_TXD | OAM5_UART_TXD | OAM6_UART_TXD | OAM7_UART_TXD | yes
Conn0 | F3 | GND | power_shared | GND | GND | GND | GND | GND | GND | GND | GND | yes | OCP-named power/ground on all 8 seats. P48V = local per-seat pour on 16 Conn0 pads after fuse keepout; NOT a 100A flood. P12V2 Unknown/may be NC. Do not tie P48V to D3000E-S1 (12 V). DO NOT ENERGIZE.
Conn0 | G3 | I2C_D | mgmt_stub | OAM0_I2C_D | OAM1_I2C_D | OAM2_I2C_D | OAM3_I2C_D | OAM4_I2C_D | OAM5_I2C_D | OAM6_I2C_D | OAM7_I2C_D | yes
Conn0 | H3 | GND | power_shared | GND | GND | GND | GND | GND | GND | GND | GND | yes | OCP-named power/ground on all 8 seats. P48V = local per-seat pour on 16 Conn0 pads after fuse keepout; NOT a 100A flood. P12V2 Unknown/may be NC. Do not tie P48V to D3000E-S1 (12 V). DO NOT ENERGIZE.
Conn0 | J3 | SMBus_SLV_CLK | mgmt_stub | OAM0_SMBus_SLV_CLK | OAM1_SMBus_SLV_CLK | OAM2_SMBus_SLV_CLK | OAM3_SMBus_SLV_CLK | OAM4_SMBus_SLV_CLK | OAM5_SMBus_SLV_CLK | OAM6_SMBus_SLV_CLK | OAM7_SMBus_SLV_CLK | yes
Conn0 | K3 | GND | power_shared | GND | GND | GND | GND | GND | GND | GND | GND | yes | OCP-named power/ground on all 8 seats. P48V = local per-seat pour on 16 Conn0 pads after fuse keepout; NOT a 100A flood. P12V2 Unknown/may be NC. Do not tie P48V to D3000E-S1 (12 V). DO NOT ENERGIZE.
Conn0 | L3 | SMBus_SLV_D | mgmt_stub | OAM0_SMBus_SLV_D | OAM1_SMBus_SLV_D | OAM2_SMBus_SLV_D | OAM3_SMBus_SLV_D | OAM4_SMBus_SLV_D | OAM5_SMBus_SLV_D | OAM6_SMBus_SLV_D | OAM7_SMBus_SLV_D | yes
Conn0 | A4 | FW_RECOVERY# | ocp_sideband | OAM0_FW_RECOVERY# | OAM1_FW_RECOVERY# | OAM2_FW_RECOVERY# | OAM3_FW_RECOVERY# | OAM4_FW_RECOVERY# | OAM5_FW_RECOVERY# | OAM6_FW_RECOVERY# | OAM7_FW_RECOVERY# | yes
Conn0 | B4 | GND | power_shared | GND | GND | GND | GND | GND | GND | GND | GND | yes | OCP-named power/ground on all 8 seats. P48V = local per-seat pour on 16 Conn0 pads after fuse keepout; NOT a 100A flood. P12V2 Unknown/may be NC. Do not tie P48V to D3000E-S1 (12 V). DO NOT ENERGIZE.
Conn0 | C4 | TEST_MODE# | unmapped_nc |  |  |  |  |  |  |  |  | no | Named in v1.0 but AMD overlay unknown or reserved; no copper
Conn0 | D4 | GND | power_shared | GND | GND | GND | GND | GND | GND | GND | GND | yes | OCP-named power/ground on all 8 seats. P48V = local per-seat pour on 16 Conn0 pads after fuse keepout; NOT a 100A flood. P12V2 Unknown/may be NC. Do not tie P48V to D3000E-S1 (12 V). DO NOT ENERGIZE.
Conn0 | E4 | UART_RXD | mgmt_stub | OAM0_UART_RXD | OAM1_UART_RXD | OAM2_UART_RXD | OAM3_UART_RXD | OAM4_UART_RXD | OAM5_UART_RXD | OAM6_UART_RXD | OAM7_UART_RXD | yes
Conn0 | F4 | GND | power_shared | GND | GND | GND | GND | GND | GND | GND | GND | yes | OCP-named power/ground on all 8 seats. P48V = local per-seat pour on 16 Conn0 pads after fuse keepout; NOT a 100A flood. P12V2 Unknown/may be NC. Do not tie P48V to D3000E-S1 (12 V). DO NOT ENERGIZE.
Conn0 | G4 | I2C _CLK | mgmt_stub | OAM0_I2C_CLK | OAM1_I2C_CLK | OAM2_I2C_CLK | OAM3_I2C_CLK | OAM4_I2C_CLK | OAM5_I2C_CLK | OAM6_I2C_CLK | OAM7_I2C_CLK | yes
Conn0 | H4 | GND | power_shared | GND | GND | GND | GND | GND | GND | GND | GND | yes | OCP-named power/ground on all 8 seats. P48V = local per-seat pour on 16 Conn0 pads after fuse keepout; NOT a 100A flood. P12V2 Unknown/may be NC. Do not tie P48V to D3000E-S1 (12 V). DO NOT ENERGIZE.
Conn0 | J4 | PRSNT0# | clock_reset | OAM0_PRSNT0# | OAM1_PRSNT0# | OAM2_PRSNT0# | OAM3_PRSNT0# | OAM4_PRSNT0# | OAM5_PRSNT0# | OAM6_PRSNT0# | OAM7_PRSNT0# | yes
Conn0 | K4 | GND | power_shared | GND | GND | GND | GND | GND | GND | GND | GND | yes | OCP-named power/ground on all 8 seats. P48V = local per-seat pour on 16 Conn0 pads after fuse keepout; NOT a 100A flood. P12V2 Unknown/may be NC. Do not tie P48V to D3000E-S1 (12 V). DO NOT ENERGIZE.
Conn0 | L4 | SLV_ALERT# | mgmt_stub | OAM0_SLV_ALERT# | OAM1_SLV_ALERT# | OAM2_SLV_ALERT# | OAM3_SLV_ALERT# | OAM4_SLV_ALERT# | OAM5_SLV_ALERT# | OAM6_SLV_ALERT# | OAM7_SLV_ALERT# | yes
Conn0 | A5 | GND | power_shared | GND | GND | GND | GND | GND | GND | GND | GND | yes | OCP-named power/ground on all 8 seats. P48V = local per-seat pour on 16 Conn0 pads after fuse keepout; NOT a 100A flood. P12V2 Unknown/may be NC. Do not tie P48V to D3000E-S1 (12 V). DO NOT ENERGIZE.
Conn0 | B5 | S1_RX15P | serdes_named_not_routed |  |  |  |  |  |  |  |  | no | Named SerDes (xGMI/IF candidate). NO NET on any seat. Do not route S1-S7.
Conn0 | C5 | GND | power_shared | GND | GND | GND | GND | GND | GND | GND | GND | yes | OCP-named power/ground on all 8 seats. P48V = local per-seat pour on 16 Conn0 pads after fuse keepout; NOT a 100A flood. P12V2 Unknown/may be NC. Do not tie P48V to D3000E-S1 (12 V). DO NOT ENERGIZE.
Conn0 | D5 | S1_RX7P | serdes_named_not_routed |  |  |  |  |  |  |  |  | no | Named SerDes (xGMI/IF candidate). NO NET on any seat. Do not route S1-S7.
Conn0 | E5 | GND | power_shared | GND | GND | GND | GND | GND | GND | GND | GND | yes | OCP-named power/ground on all 8 seats. P48V = local per-seat pour on 16 Conn0 pads after fuse keepout; NOT a 100A flood. P12V2 Unknown/may be NC. Do not tie P48V to D3000E-S1 (12 V). DO NOT ENERGIZE.
Conn0 | F5 | RFU | unmapped_nc |  |  |  |  |  |  |  |  | no | Named in v1.0 but AMD overlay unknown or reserved; no copper
Conn0 | G5 | GND | power_shared | GND | GND | GND | GND | GND | GND | GND | GND | yes | OCP-named power/ground on all 8 seats. P48V = local per-seat pour on 16 Conn0 pads after fuse keepout; NOT a 100A flood. P12V2 Unknown/may be NC. Do not tie P48V to D3000E-S1 (12 V). DO NOT ENERGIZE.
Conn0 | H5 | S1_TX15P | serdes_named_not_routed |  |  |  |  |  |  |  |  | no | Named SerDes (xGMI/IF candidate). NO NET on any seat. Do not route S1-S7.
Conn0 | J5 | GND | power_shared | GND | GND | GND | GND | GND | GND | GND | GND | yes | OCP-named power/ground on all 8 seats. P48V = local per-seat pour on 16 Conn0 pads after fuse keepout; NOT a 100A flood. P12V2 Unknown/may be NC. Do not tie P48V to D3000E-S1 (12 V). DO NOT ENERGIZE.
Conn0 | K5 | S1_TX7P | serdes_named_not_routed |  |  |  |  |  |  |  |  | no | Named SerDes (xGMI/IF candidate). NO NET on any seat. Do not route S1-S7.
Conn0 | L5 | GND | power_shared | GND | GND | GND | GND | GND | GND | GND | GND | yes | OCP-named power/ground on all 8 seats. P48V = local per-seat pour on 16 Conn0 pads after fuse keepout; NOT a 100A flood. P12V2 Unknown/may be NC. Do not tie P48V to D3000E-S1 (12 V). DO NOT ENERGIZE.
Conn0 | A6 | GND | power_shared | GND | GND | GND | GND | GND | GND | GND | GND | yes | OCP-named power/ground on all 8 seats. P48V = local per-seat pour on 16 Conn0 pads after fuse keepout; NOT a 100A flood. P12V2 Unknown/may be NC. Do not tie P48V to D3000E-S1 (12 V). DO NOT ENERGIZE.
Conn0 | B6 | S1_RX15N | serdes_named_not_routed |  |  |  |  |  |  |  |  | no | Named SerDes (xGMI/IF candidate). NO NET on any seat. Do not route S1-S7.
Conn0 | C6 | GND | power_shared | GND | GND | GND | GND | GND | GND | GND | GND | yes | OCP-named power/ground on all 8 seats. P48V = local per-seat pour on 16 Conn0 pads after fuse keepout; NOT a 100A flood. P12V2 Unknown/may be NC. Do not tie P48V to D3000E-S1 (12 V). DO NOT ENERGIZE.
Conn0 | D6 | S1_RX7N | serdes_named_not_routed |  |  |  |  |  |  |  |  | no | Named SerDes (xGMI/IF candidate). NO NET on any seat. Do not route S1-S7.
Conn0 | E6 | GND | power_shared | GND | GND | GND | GND | GND | GND | GND | GND | yes | OCP-named power/ground on all 8 seats. P48V = local per-seat pour on 16 Conn0 pads after fuse keepout; NOT a 100A flood. P12V2 Unknown/may be NC. Do not tie P48V to D3000E-S1 (12 V). DO NOT ENERGIZE.
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

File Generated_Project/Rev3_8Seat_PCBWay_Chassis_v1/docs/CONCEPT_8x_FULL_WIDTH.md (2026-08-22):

# Pointer — 8× full-width CONCEPT

**CONCEPT / DO NOT FABRICATE / DO NOT ENERGIZE.**

Canonical write-up (sibling folder, not a fab zip):

[`Generated_Project/Rev3_8Seat_FULLWIDTH_CONCEPT/CONCEPT.md`](../../Rev3_8Seat_FULLWIDTH_CONCEPT/CONCEPT.md)

First article on this board remains seats **0–1**, GCD0 x16 only. The 8-wide names and SW0–SW3 DNP courtyards are hooks for that CONCEPT. Routing 16× x16 and four 1311-ball escapes is a **respin** — [`LATE_BIND.md`](../../Rev3_8Seat_FULLWIDTH_CONCEPT/LATE_BIND.md). **X11DPH-T cannot light 8× full-width.** Do not claim DRC-clean live PE.

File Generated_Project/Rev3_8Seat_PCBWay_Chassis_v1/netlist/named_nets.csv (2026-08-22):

net | oam | connector | pads
GND | 0 | Conn0 | E1 J1 E2 J2 B3 D3 F3 H3 K3 B4 D4 F4 H4 K4 A5 C5 E5 G5 J5 L5 A6 C6 E6 G6 J6 L6 B7 D7 F7 H7 K7 B8 D8 F8 H8 K8 A9 C9 E9 G9 J9 L9 A10 C10 E10 G10 J10 L10 B11 D11 F11 H11 K11 B12 D12 F12 H12 K12 A13 C13 E13 G13 J13 L13 A14 C14 E14 G14 J14 L14 B15 D15 F15 H15 K15 B16 D16 F16 H16 K16 A17 C17 E17 G17 J17 L17 A18 C18 E18 G18 J18 L18 B19 D19 F19 H19 K19 B20 D20 F20 H20 K20 A21 C21 E21 G21 J21 L21 A22 C22 E22 G22 J22 L22 B23 D23 F23 H23 K23 B24 D24 F24 H24 K24 A25 C25 E25 G25 J25 L25 A26 C26 E26 G26 J26 L26 B27 D27 F27 H27 K27 B28 D28 F28 H28 K28 A29 C29 E29 G29 J29 L29 A30 C30 E30 G30 J30 L30 B31 D31 F31 H31 K31 B32 D32 F32 H32 K32 A33 C33 E33 G33 J33 L33 A34 C34 E34 G34 J34 L34 B35 D35 F35 H35 K35 B36 D36 F36 H36 K36 A37 C37 E37 G37 J37 L37 A38 C38 E38 G38 J38 L38 B39 D39 F39 H39 K39 B40 D40 F40 H40 K40 A41 C41 E41 G41 J41 L41 A42 C42 E42 G42 J42 L42 B43 D43 F43 H43 K43 B44 D44 F44 H44 K44 A45 C45 E45 G45 J45 L45 A46 C46 E46 G46 J46 L46 B47 D47 F47 H47 K47 B48 D48 F48 H48 K48 A49 C49 E49 G49 J49 L49 A50 C50 E50 G50 J50 L50 B51 D51 F51 H51 K51 B52 D52 F52 H52 K52 A53 C53 E53 F53 G53 J53 L53 A54 C54 E54 F54 G54 J54 L54 B55 D55 E55 F55 G55 H55 K55 B56 D56 E56 F56 G56 H56 K56 A57 B57 C57 D57 E57 F57 G57 H57 J57 K57 L57 A58 B58 C58 D58 E58 F58 G58 J58 L58 G59 J59 L59 G60 G61 G62 G63 G64
GND | 0 | Conn1 | C1 E1 G1 J1 C2 E2 G2 J2 B3 D3 F3 H3 K3 B4 D4 F4 H4 K4 A5 C5 E5 G5 J5 L5 A6 C6 E6 G6 J6 L6 B7 D7 F7 H7 K7 B8 D8 F8 H8 K8 A9 C9 E9 G9 J9 L9 A10 C10 E10 G10 J10 L10 B11 D11 F11 H11 K11 B12 D12 F12 H12 K12 A13 C13 E13 G13 J13 L13 A14 C14 E14 G14 J14 L14 B15 D15 F15 H15 K15 B16 D16 F16 H16 K16 A17 C17 E17 G17 J17 L17 A18 C18 E18 G18 J18 L18 B19 D19 F19 H19 K19 B20 D20 F20 H20 K20 A21 C21 E21 G21 J21 L21 A22 C22 E22 G22 J22 L22 B23 D23 F23 H23 K23 B24 D24 F24 H24 K24 A25 C25 E25 G25 J25 L25 A26 C26 E26 G26 J26 L26 B27 D27 F27 H27 K27 B28 D28 F28 H28 K28 A29 C29 E29 G29 J29 L29 A30 C30 E30 G30 J30 L30 B31 D31 F31 H31 K31 B32 D32 F32 H32 K32 A33 C33 E33 G33 J33 L33 A34 C34 E34 G34 J34 L34 B35 D35 F35 H35 K35 B36 D36 F36 H36 K36 A37 C37 E37 G37 J37 L37 A38 C38 E38 G38 J38 L38 B39 D39 F39 H39 K39 B40 D40 F40 H40 K40 A41 C41 E41 G41 J41 L41 A42 C42 E42 G42 J42 L42 B43 D43 F43 H43 K43 B44 D44 F44 H44 K44 A45 C45 E45 G45 J45 L45 A46 C46 E46 G46 J46 L46 B47 D47 F47 H47 K47 B48 D48 F48 H48 K48 A49 C49 E49 G49 J49 L49 A50 C50 E50 G50 J50 L50 B51 D51 F51 H51 K51 B52 D52 F52 H52 K52 A53 C53 E53 G53 J53 L53 A54 C54 E54 G54 J54 L54 B55 D55 F55 H55 K55 B56 D56 F56 H56 K56 A57 C57 E57 G57 J57 L57 A58 C58 E58 G58 J58 L58 B59 D59 F59 H59 K59 B60 D60 F60 H60 K60 A61 C61 E61 G61 J61 L61 A62 C62 E62 G62 J62 L62 D63 F63 H63 D64 F64 H64
GND | 1 | Conn0 | E1 J1 E2 J2 B3 D3 F3 H3 K3 B4 D4 F4 H4 K4 A5 C5 E5 G5 J5 L5 A6 C6 E6 G6 J6 L6 B7 D7 F7 H7 K7 B8 D8 F8 H8 K8 A9 C9 E9 G9 J9 L9 A10 C10 E10 G10 J10 L10 B11 D11 F11 H11 K11 B12 D12 F12 H12 K12 A13 C13 E13 G13 J13 L13 A14 C14 E14 G14 J14 L14 B15 D15 F15 H15 K15 B16 D16 F16 H16 K16 A17 C17 E17 G17 J17 L17 A18 C18 E18 G18 J18 L18 B19 D19 F19 H19 K19 B20 D20 F20 H20 K20 A21 C21 E21 G21 J21 L21 A22 C22 E22 G22 J22 L22 B23 D23 F23 H23 K23 B24 D24 F24 H24 K24 A25 C25 E25 G25 J25 L25 A26 C26 E26 G26 J26 L26 B27 D27 F27 H27 K27 B28 D28 F28 H28 K28 A29 C29 E29 G29 J29 L29 A30 C30 E30 G30 J30 L30 B31 D31 F31 H31 K31 B32 D32 F32 H32 K32 A33 C33 E33 G33 J33 L33 A34 C34 E34 G34 J34 L34 B35 D35 F35 H35 K35 B36 D36 F36 H36 K36 A37 C37 E37 G37 J37 L37 A38 C38 E38 G38 J38 L38 B39 D39 F39 H39 K39 B40 D40 F40 H40 K40 A41 C41 E41 G41 J41 L41 A42 C42 E42 G42 J42 L42 B43 D43 F43 H43 K43 B44 D44 F44 H44 K44 A45 C45 E45 G45 J45 L45 A46 C46 E46 G46 J46 L46 B47 D47 F47 H47 K47 B48 D48 F48 H48 K48 A49 C49 E49 G49 J49 L49 A50 C50 E50 G50 J50 L50 B51 D51 F51 H51 K51 B52 D52 F52 H52 K52 A53 C53 E53 F53 G53 J53 L53 A54 C54 E54 F54 G54 J54 L54 B55 D55 E55 F55 G55 H55 K55 B56 D56 E56 F56 G56 H56 K56 A57 B57 C57 D57 E57 F57 G57 H57 J57 K57 L57 A58 B58 C58 D58 E58 F58 G58 J58 L58 G59 J59 L59 G60 G61 G62 G63 G64
GND | 1 | Conn1 | C1 E1 G1 J1 C2 E2 G2 J2 B3 D3 F3 H3 K3 B4 D4 F4 H4 K4 A5 C5 E5 G5 J5 L5 A6 C6 E6 G6 J6 L6 B7 D7 F7 H7 K7 B8 D8 F8 H8 K8 A9 C9 E9 G9 J9 L9 A10 C10 E10 G10 J10 L10 B11 D11 F11 H11 K11 B12 D12 F12 H12 K12 A13 C13 E13 G13 J13 L13 A14 C14 E14 G14 J14 L14 B15 D15 F15 H15 K15 B16 D16 F16 H16 K16 A17 C17 E17 G17 J17 L17 A18 C18 E18 G18 J18 L18 B19 D19 F19 H19 K19 B20 D20 F20 H20 K20 A21 C21 E21 G21 J21 L21 A22 C22 E22 G22 J22 L22 B23 D23 F23 H23 K23 B24 D24 F24 H24 K24 A25 C25 E25 G25 J25 L25 A26 C26 E26 G26 J26 L26 B27 D27 F27 H27 K27 B28 D28 F28 H28 K28 A29 C29 E29 G29 J29 L29 A30 C30 E30 G30 J30 L30 B31 D31 F31 H31 K31 B32 D32 F32 H32 K32 A33 C33 E33 G33 J33 L33 A34 C34 E34 G34 J34 L34 B35 D35 F35 H35 K35 B36 D36 F36 H36 K36 A37 C37 E37 G37 J37 L37 A38 C38 E38 G38 J38 L38 B39 D39 F39 H39 K39 B40 D40 F40 H40 K40 A41 C41 E41 G41 J41 L41 A42 C42 E42 G42 J42 L42 B43 D43 F43 H43 K43 B44 D44 F44 H44 K44 A45 C45 E45 G45 J45 L45 A46 C46 E46 G46 J46 L46 B47 D47 F47 H47 K47 B48 D48 F48 H48 K48 A49 C49 E49 G49 J49 L49 A50 C50 E50 G50 J50 L50 B51 D51 F51 H51 K51 B52 D52 F52 H52 K52 A53 C53 E53 G53 J53 L53 A54 C54 E54 G54 J54 L54 B55 D55 F55 H55 K55 B56 D56 F56 H56 K56 A57 C57 E57 G57 J57 L57 A58 C58 E58 G58 J58 L58 B59 D59 F59 H59 K59 B60 D60 F60 H60 K60 A61 C61 E61 G61 J61 L61 A62 C62 E62 G62 J62 L62 D63 F63 H63 D64 F64 H64
GND | 2 | Conn0 | E1 J1 E2 J2 B3 D3 F3 H3 K3 B4 D4 F4 H4 K4 A5 C5 E5 G5 J5 L5 A6 C6 E6 G6 J6 L6 B7 D7 F7 H7 K7 B8 D8 F8 H8 K8 A9 C9 E9 G9 J9 L9 A10 C10 E10 G10 J10 L10 B11 D11 F11 H11 K11 B12 D12 F12 H12 K12 A13 C13 E13 G13 J13 L13 A14 C14 E14 G14 J14 L14 B15 D15 F15 H15 K15 B16 D16 F16 H16 K16 A17 C17 E17 G17 J17 L17 A18 C18 E18 G18 J18 L18 B19 D19 F19 H19 K19 B20 D20 F20 H20 K20 A21 C21 E21 G21 J21 L21 A22 C22 E22 G22 J22 L22 B23 D23 F23 H23 K23 B24 D24 F24 H24 K24 A25 C25 E25 G25 J25 L25 A26 C26 E26 G26 J26 L26 B27 D27 F27 H27 K27 B28 D28 F28 H28 K28 A29 C29 E29 G29 J29 L29 A30 C30 E30 G30 J30 L30 B31 D31 F31 H31 K31 B32 D32 F32 H32 K32 A33 C33 E33 G33 J33 L33 A34 C34 E34 G34 J34 L34 B35 D35 F35 H35 K35 B36 D36 F36 H36 K36 A37 C37 E37 G37 J37 L37 A38 C38 E38 G38 J38 L38 B39 D39 F39 H39 K39 B40 D40 F40 H40 K40 A41 C41 E41 G41 J41 L41 A42 C42 E42 G42 J42 L42 B43 D43 F43 H43 K43 B44 D44 F44 H44 K44 A45 C45 E45 G45 J45 L45 A46 C46 E46 G46 J46 L46 B47 D47 F47 H47 K47 B48 D48 F48 H48 K48 A49 C49 E49 G49 J49 L49 A50 C50 E50 G50 J50 L50 B51 D51 F51 H51 K51 B52 D52 F52 H52 K52 A53 C53 E53 F53 G53 J53 L53 A54 C54 E54 F54 G54 J54 L54 B55 D55 E55 F55 G55 H55 K55 B56 D56 E56 F56 G56 H56 K56 A57 B57 C57 D57 E57 F57 G57 H57 J57 K57 L57 A58 B58 C58 D58 E58 F58 G58 J58 L58 G59 J59 L59 G60 G61 G62 G63 G64
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

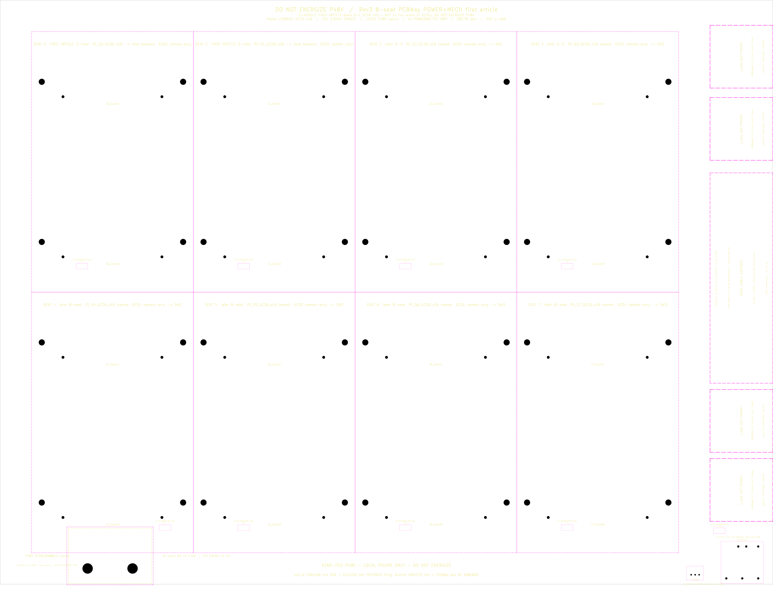
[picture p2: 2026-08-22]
Generated_Project/Rev3_8Seat_PCBWay_Chassis_v1/docs/previews/MI250X_8OAM_PCBWay_Chassis_Stub-silk.png

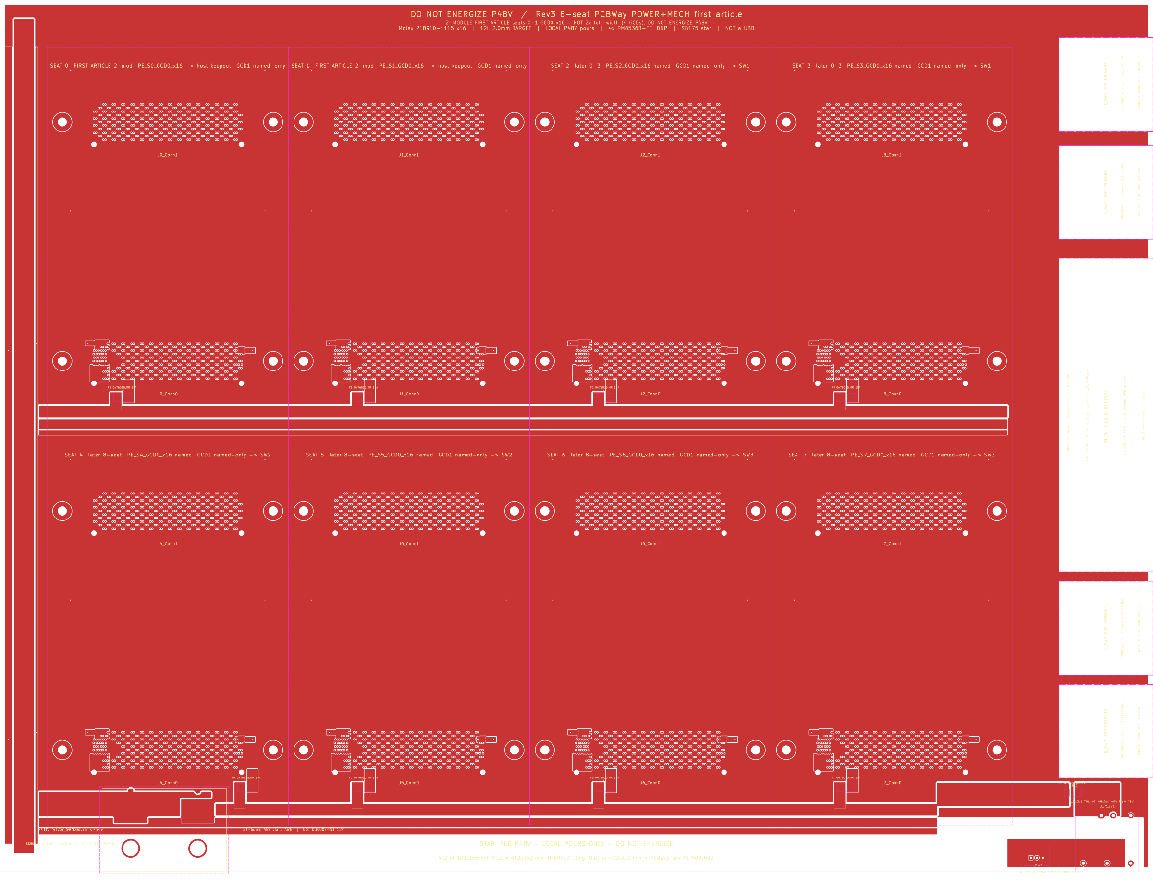
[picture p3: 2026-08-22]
Generated_Project/Rev3_8Seat_PCBWay_Chassis_v1/docs/previews/MI250X_8OAM_PCBWay_Chassis_Stub-top.png

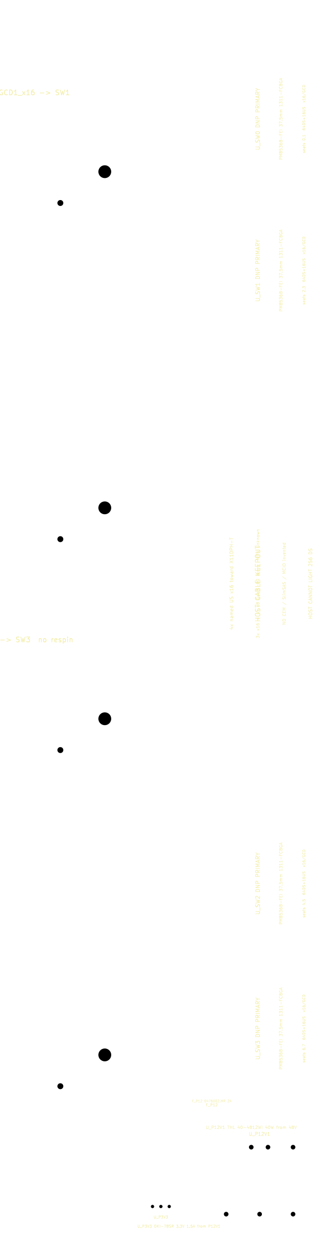
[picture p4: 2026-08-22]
Generated_Project/Rev3_8Seat_PCBWay_Chassis_v1/docs/previews/host_strip_sw0_sw3.png

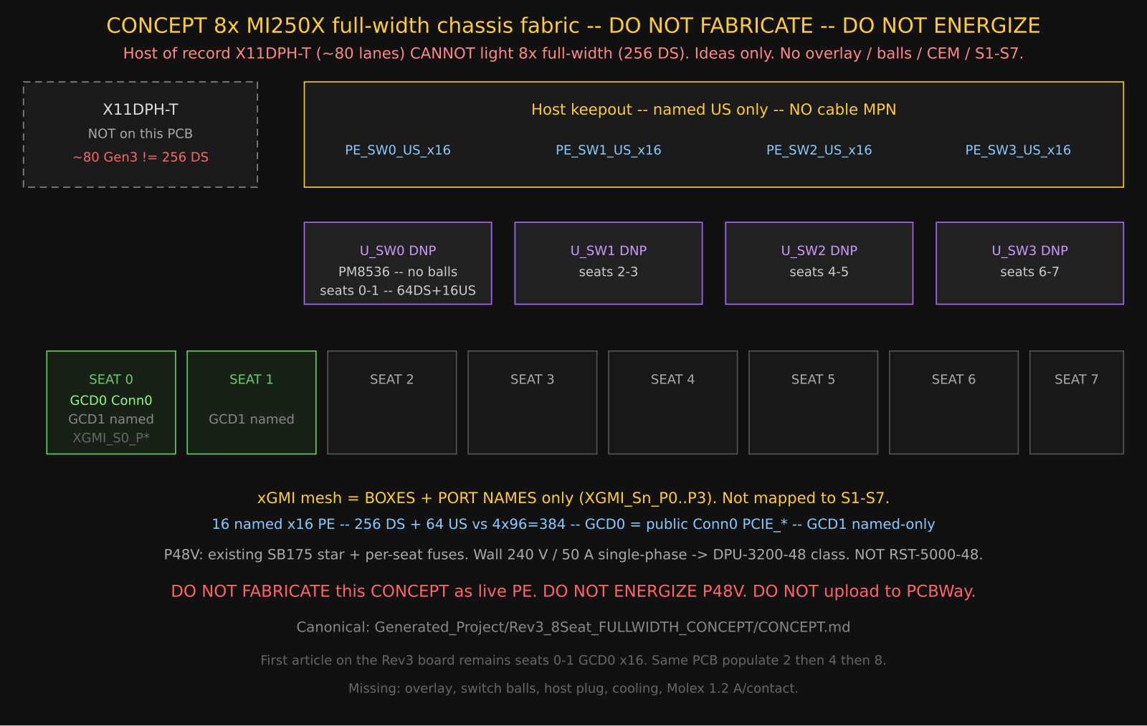
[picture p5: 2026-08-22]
Generated_Project/Rev3_8Seat_FULLWIDTH_CONCEPT/concept_fabric.png

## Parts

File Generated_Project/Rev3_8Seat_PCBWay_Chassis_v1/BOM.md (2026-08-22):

# BOM — Rev3 8-seat PCBWay chassis PCB (POWER+MECH first article)

**PCB bill only.** Not a GPU order, not a 48 V shelf, not a cooling loop.  
**First article: seats 0–1.** Stuff F0/F1 when modules exist; F2–F7 may stay DNP until 4- then 8-seat populate.  
**DO NOT ENERGIZE P48V** until Molex 1.2 A/contact at 48–59.5 V is written (ticket 167157).  
**Do not upload from this tree** — Eli uploads the `fab/` zip if he accepts it.

Host SuperMicro X11DPH-T is **not** on this PCB. GPUs (P41933-001) are **do-not-order**.

| Qty | Ref | MPN | Description | Status | Notes |
|---:|---|---|---|---|---|
| 16 | J0_Conn0 … J7_Conn1 | **Molex 218910-1115** | Mirror Mezz Pro, 688 contact, 5.00 mm | **Buy** | CSA 60 V at OCP P48V (COFC 80170713). 1.2 A/contact OPEN. Skip-pin = published map. SMT of 16× 688-ball is a factory process. |
| 1 | J_SB175 | Anderson **6325G1** | SB175 2-pole gray housing | **Buy** | 175 A / 600 V. Cable-side housing. |
| 2 | — | Anderson **1382** | SB175 1/0 AWG silver contact | **Buy** | Pair with 6325G1. Not D3000E-S1. |
| 8 | F0–F7 | Littelfuse **0476015.MR** | Nano2 15 A 125 VDC | **Buy** | Per-seat P48V. First article stuffs **F0/F1**. Land = KiCad `Fuse_Littelfuse-NANO2-451_453`. |
| 1 | F_P12 | Littelfuse **0476002.MR** | Nano2 2 A 125 VDC | **Buy** | THL40 input. Same land. |
| 1 | U_P12V1 | TRACO **THL 40-4812WI** | 18–75 Vin, 12 V / 3.35 A / 40 W isolated 1×1 | **Buy** | OCP P12V1 ≤50 W; this MPN is the 40 W first-article cap. Returns bonded to board GND. |
| 1 | U_P3V3 | Murata **OKI-78SR-3.3/1.5-W36-C** | 7–36 Vin, 3.3 V / 1.5 A / 4.95 W SIP | **Buy** | From P12V1. No GPU VRM. |
| 0 | U_SW0, U_SW1, U_SW2, U_SW3 | **PM8536B-FEI** | 96-lane Gen3 1311-FCBGA 1.0 mm | **DNP** ×4 | Courtyard only. Ball map not public. SW0=seats 0–1, SW1=2–3, SW2=4–5, SW3=6–7. Do not stuff this article. |
| 32 | H0{1–4}…H7{1–4} | (NPTH φ3.9 mm) | OAM Fig 2 M3.5 | **Fab** | Not a fastener SKU. |
| 1 | PCB | 12L 492×372 mm 2.0 mm ENIG 2 oz/1 oz green/white | FR-4 chassis | **Fab zip** | Guest qty-5 **$2237.90 + $68.43 DHL**. See `fab/`. |

## Explicitly not on this PCB

| Item | Why it is absent |
|---|---|
| SuperMicro **X11DPH-T**, 2× Gold **6230**, **NH-D9 DX-3647** | Host Chamber B. Not this PCB. |
| 1000 W ATX/EPS | Host only. Not OAM P48V. |
| HPE **P41933-001** / any MI250X | Do-not-order. Seats exist; modules are not a chassis line. |
| Dell **D3000E-S1** | 12 V CRPS. Must not feed OAM P48V. |
| Mean Well / any 48 V shelf | No PSU shopping. SB175 is the inlet. 240 V / 50 A single-phase class — **not** RST-5000-48 (3-phase). |
| CEM x16 / SlimSAS / MCIO / retimer | Not invented (no public on-carrier MPN chosen without inventing OAM↔MCIO). |
| GPU multiphase VRM / cold plate | Forbidden. |

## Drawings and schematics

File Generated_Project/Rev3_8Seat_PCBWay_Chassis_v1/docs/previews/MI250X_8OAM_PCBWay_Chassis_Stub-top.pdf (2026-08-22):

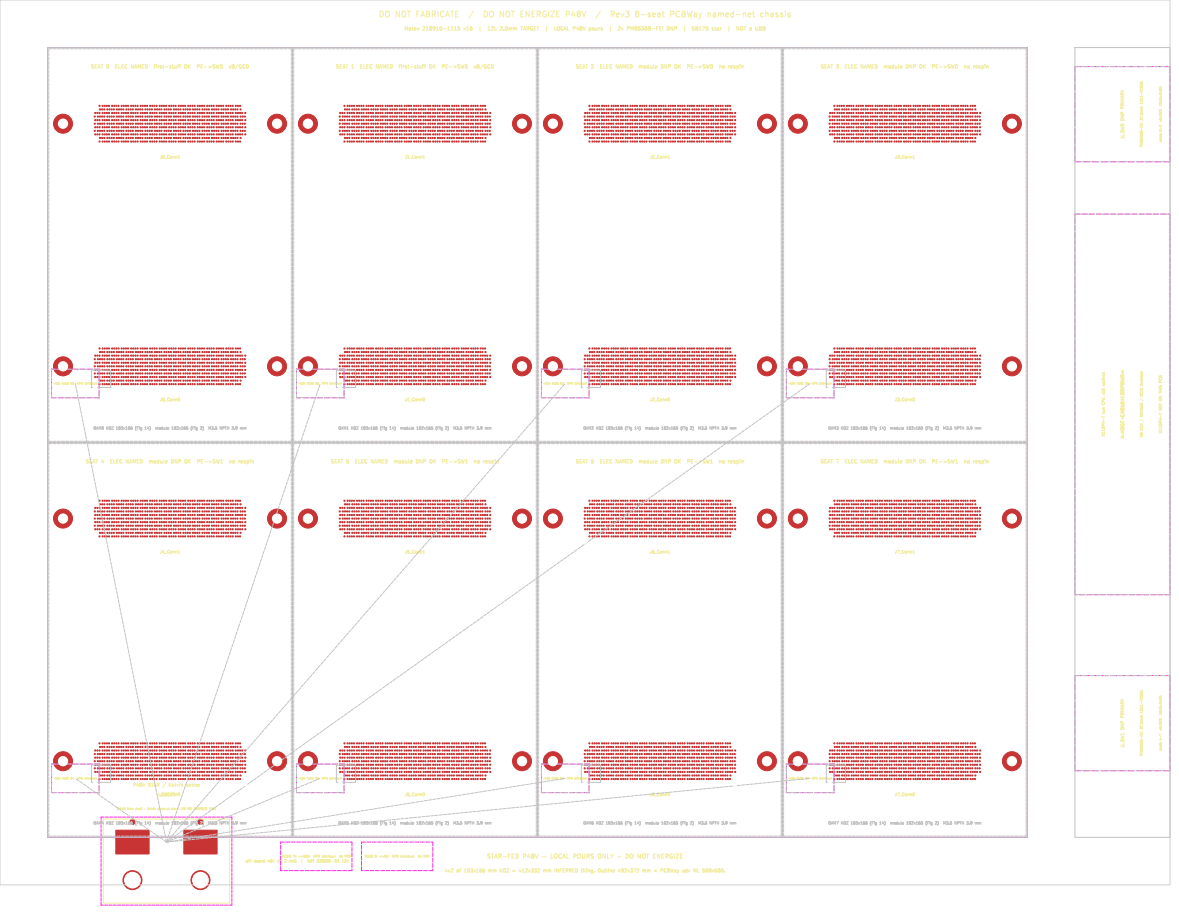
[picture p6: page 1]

2 AWG from shelf þÿ Kelvin sense at star þÿ DO NOT ENERGIZE P48V

STAR-FED P48V þÿ LOCAL POURS ONLY þÿ DO NOT ENERGIZE

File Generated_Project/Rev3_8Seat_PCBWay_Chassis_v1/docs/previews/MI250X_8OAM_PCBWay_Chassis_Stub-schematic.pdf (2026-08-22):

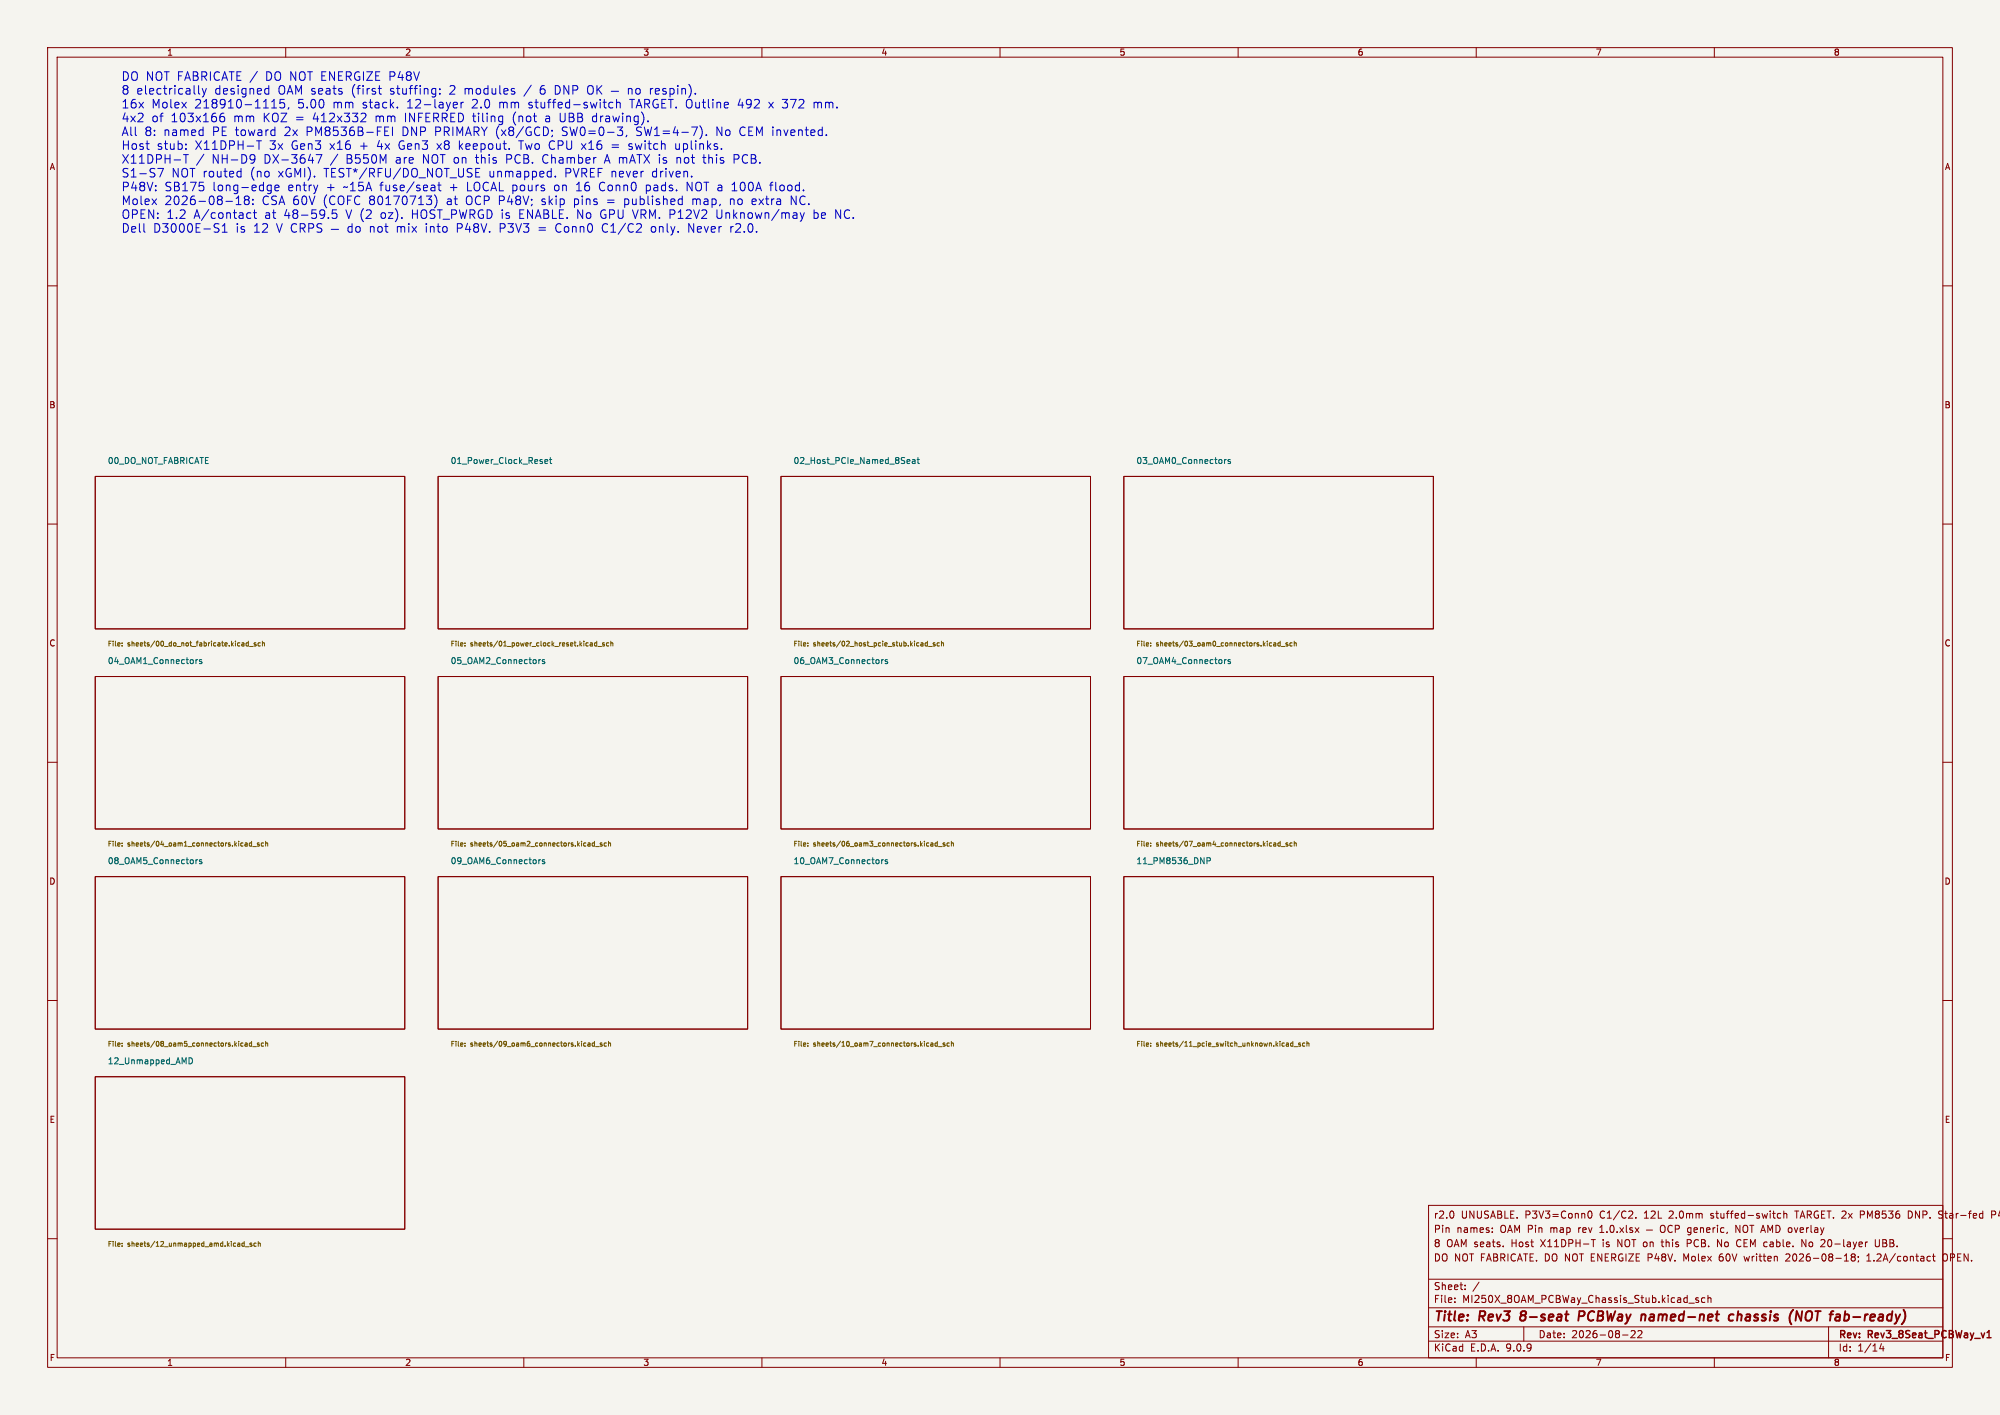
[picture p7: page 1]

DO NOT FABRICATE / DO NOT ENERGIZE P48V

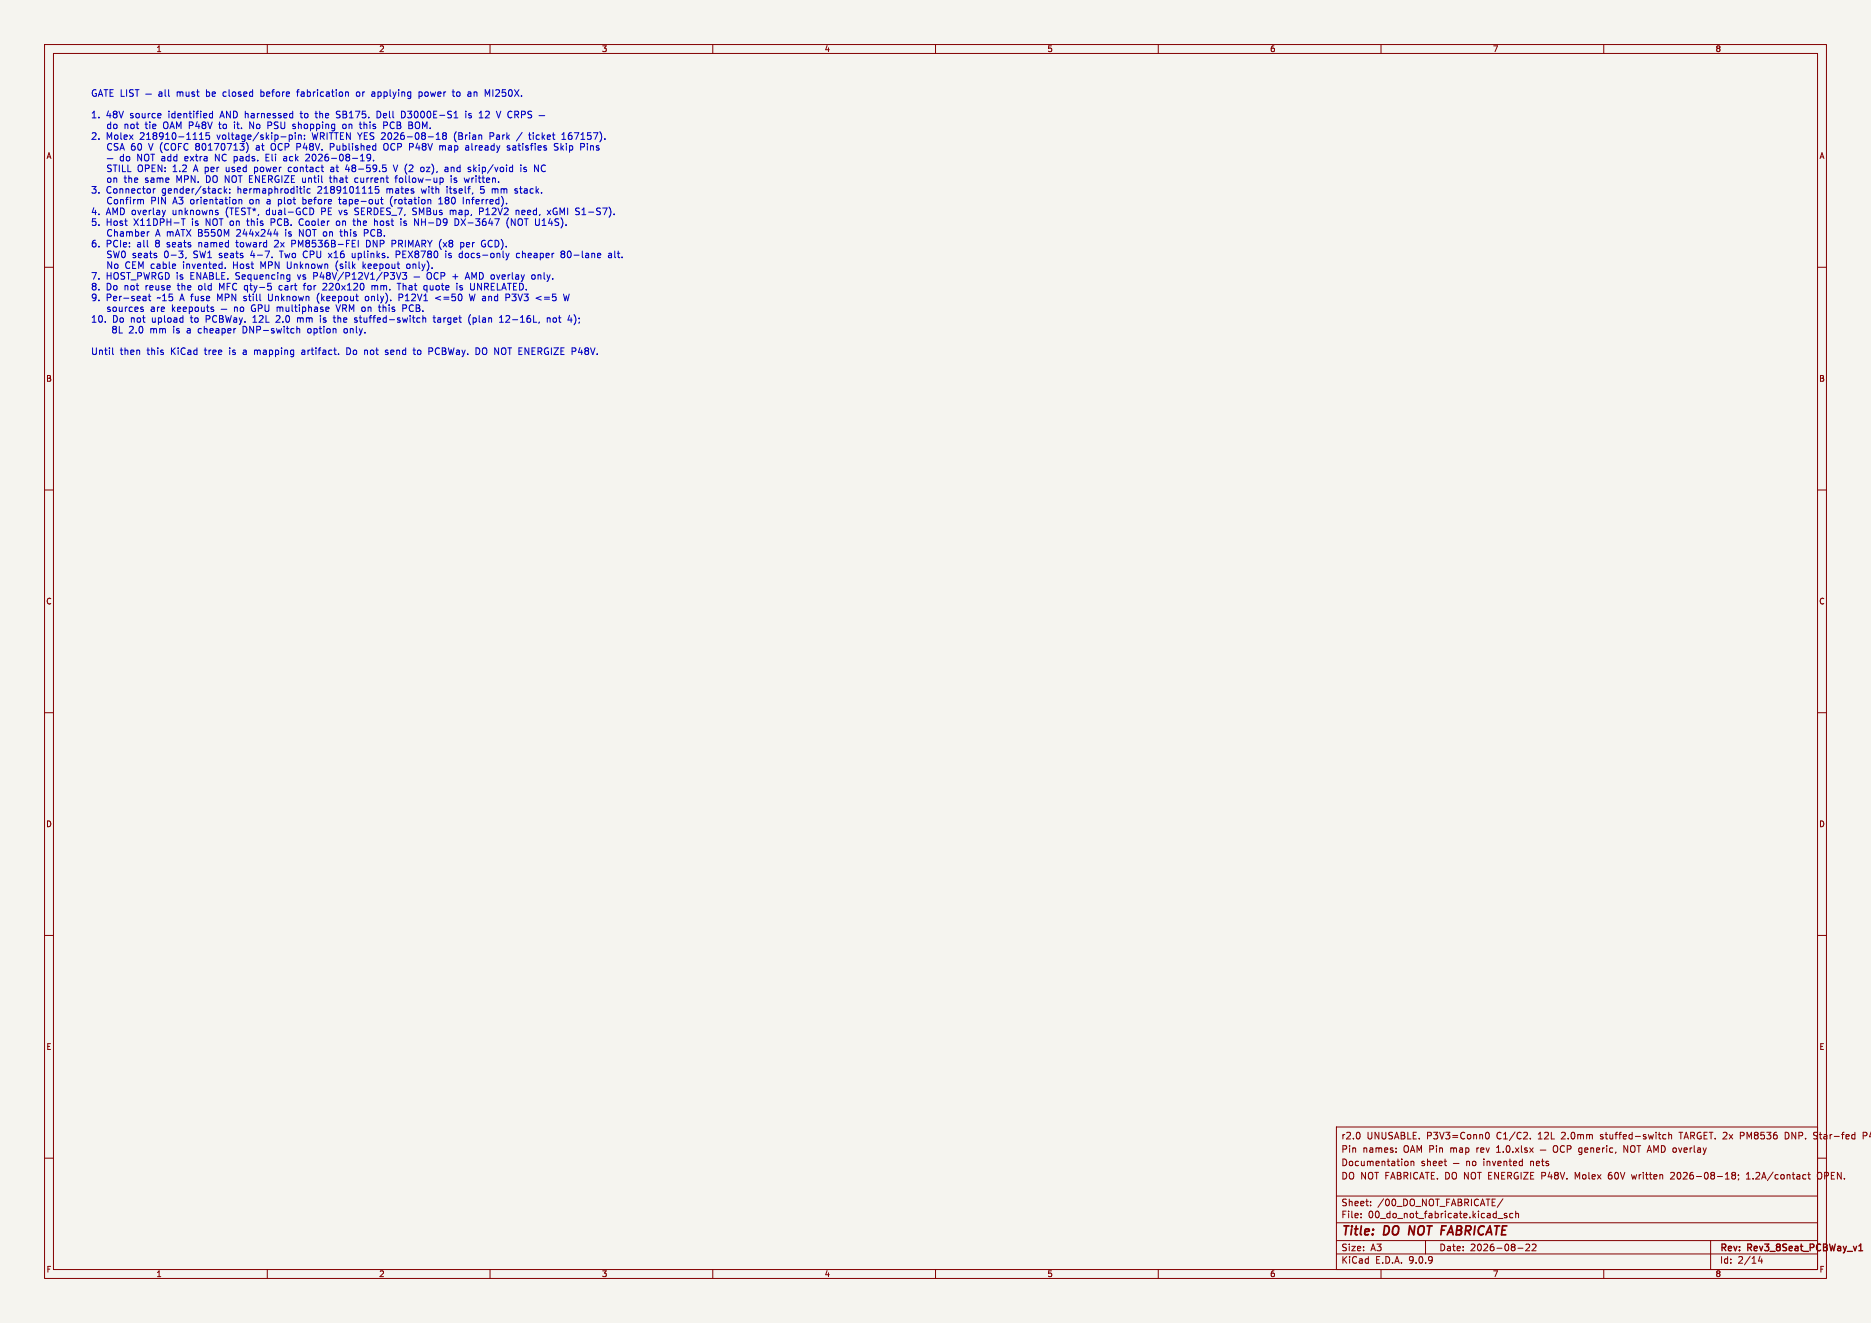
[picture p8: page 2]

Id: 2/14 Title: DO NOT FABRICATE

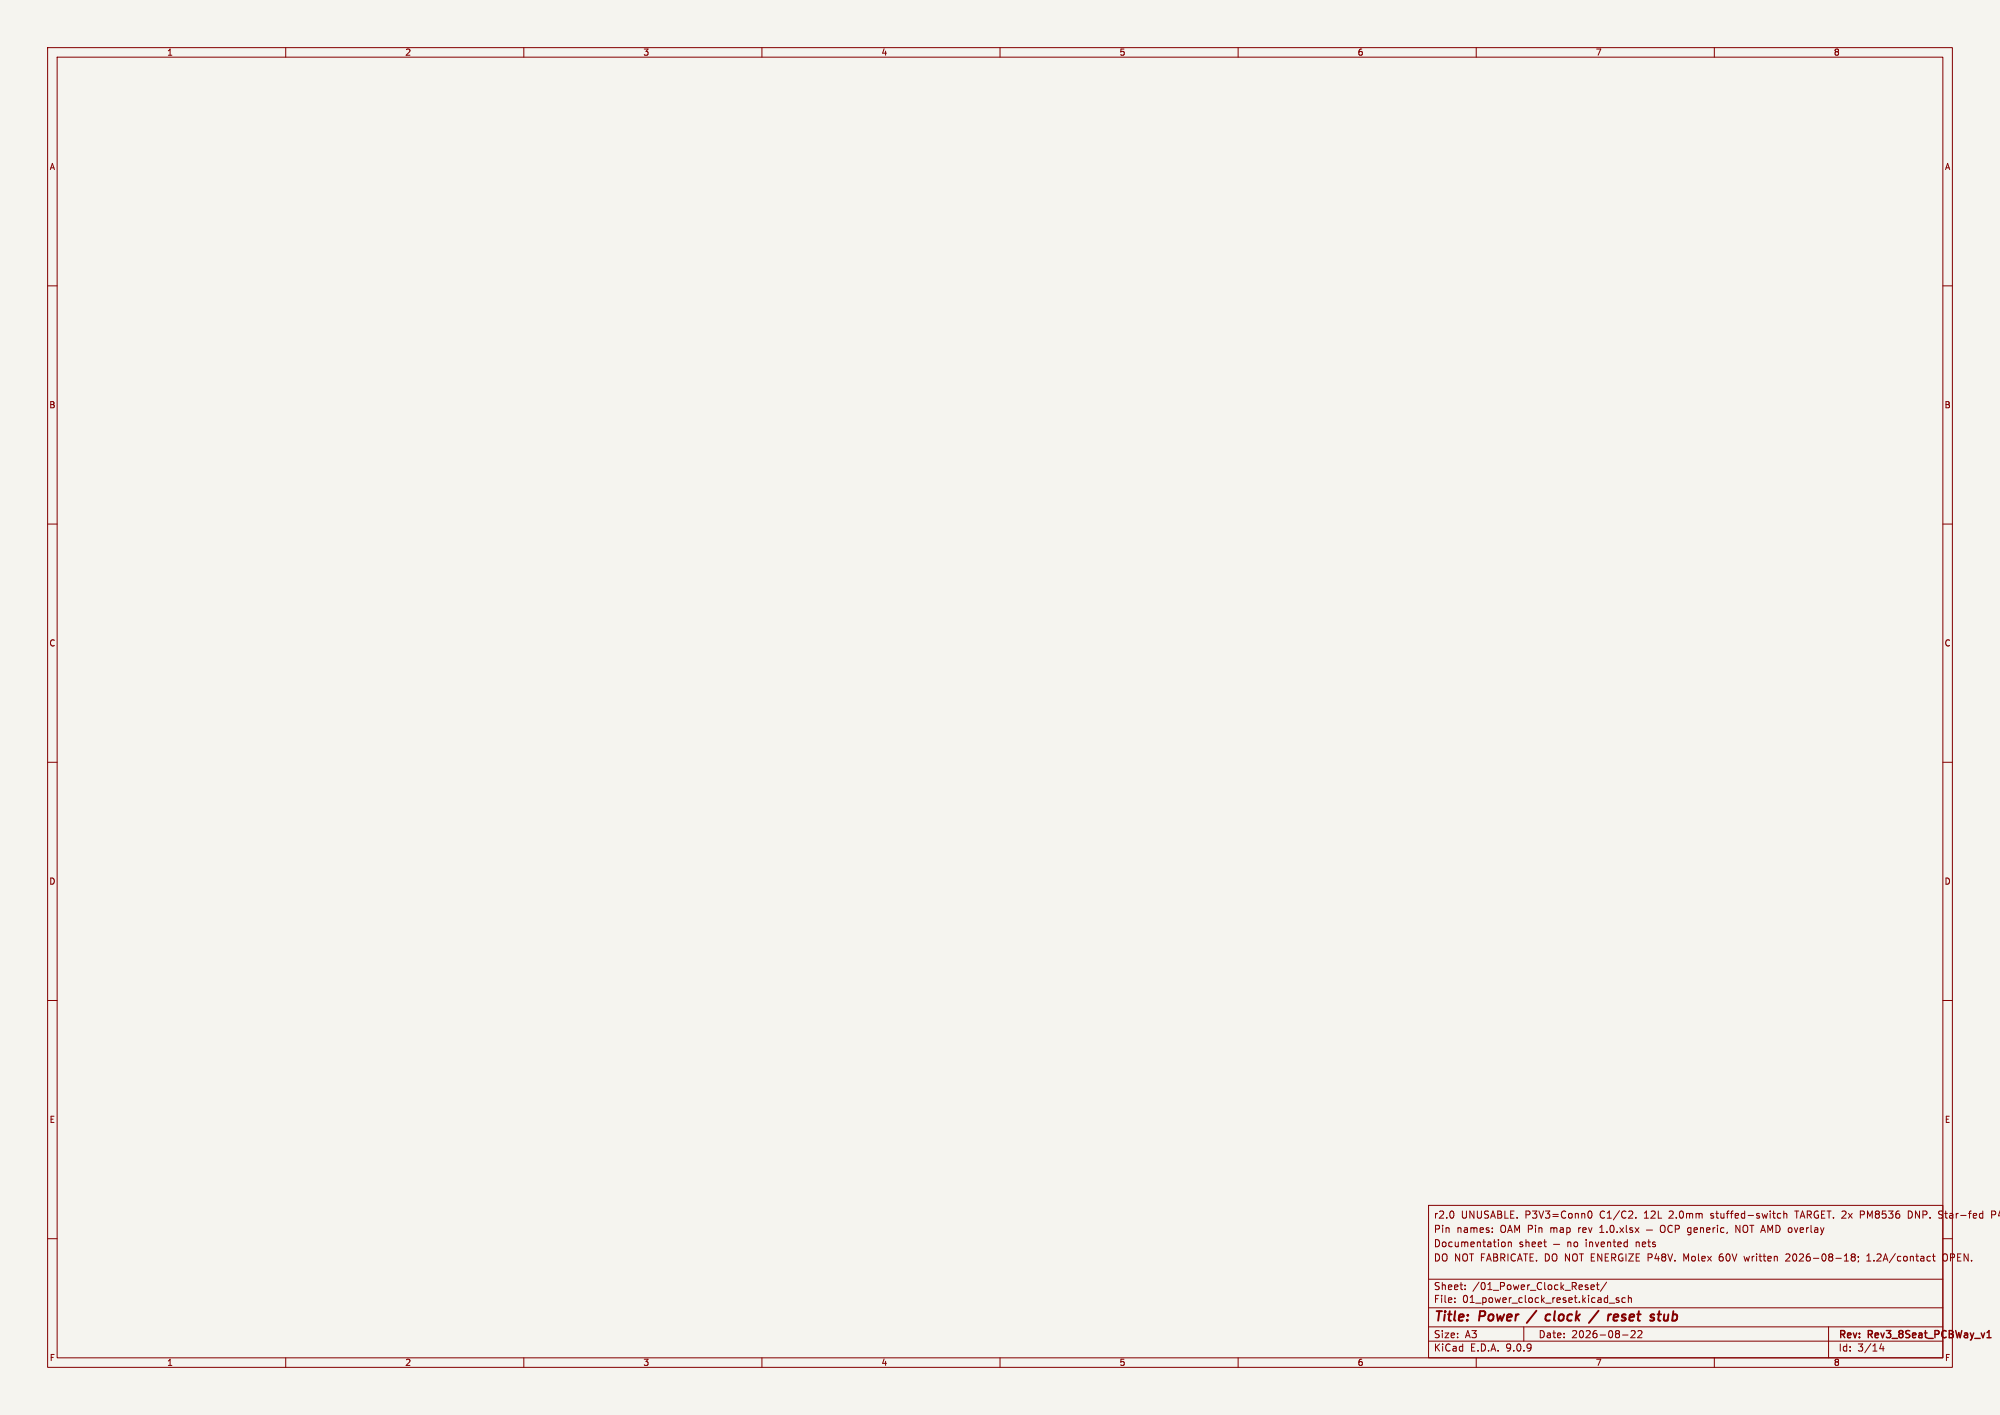
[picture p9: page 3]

Id: 3/14 Title: Power / clock / reset stub

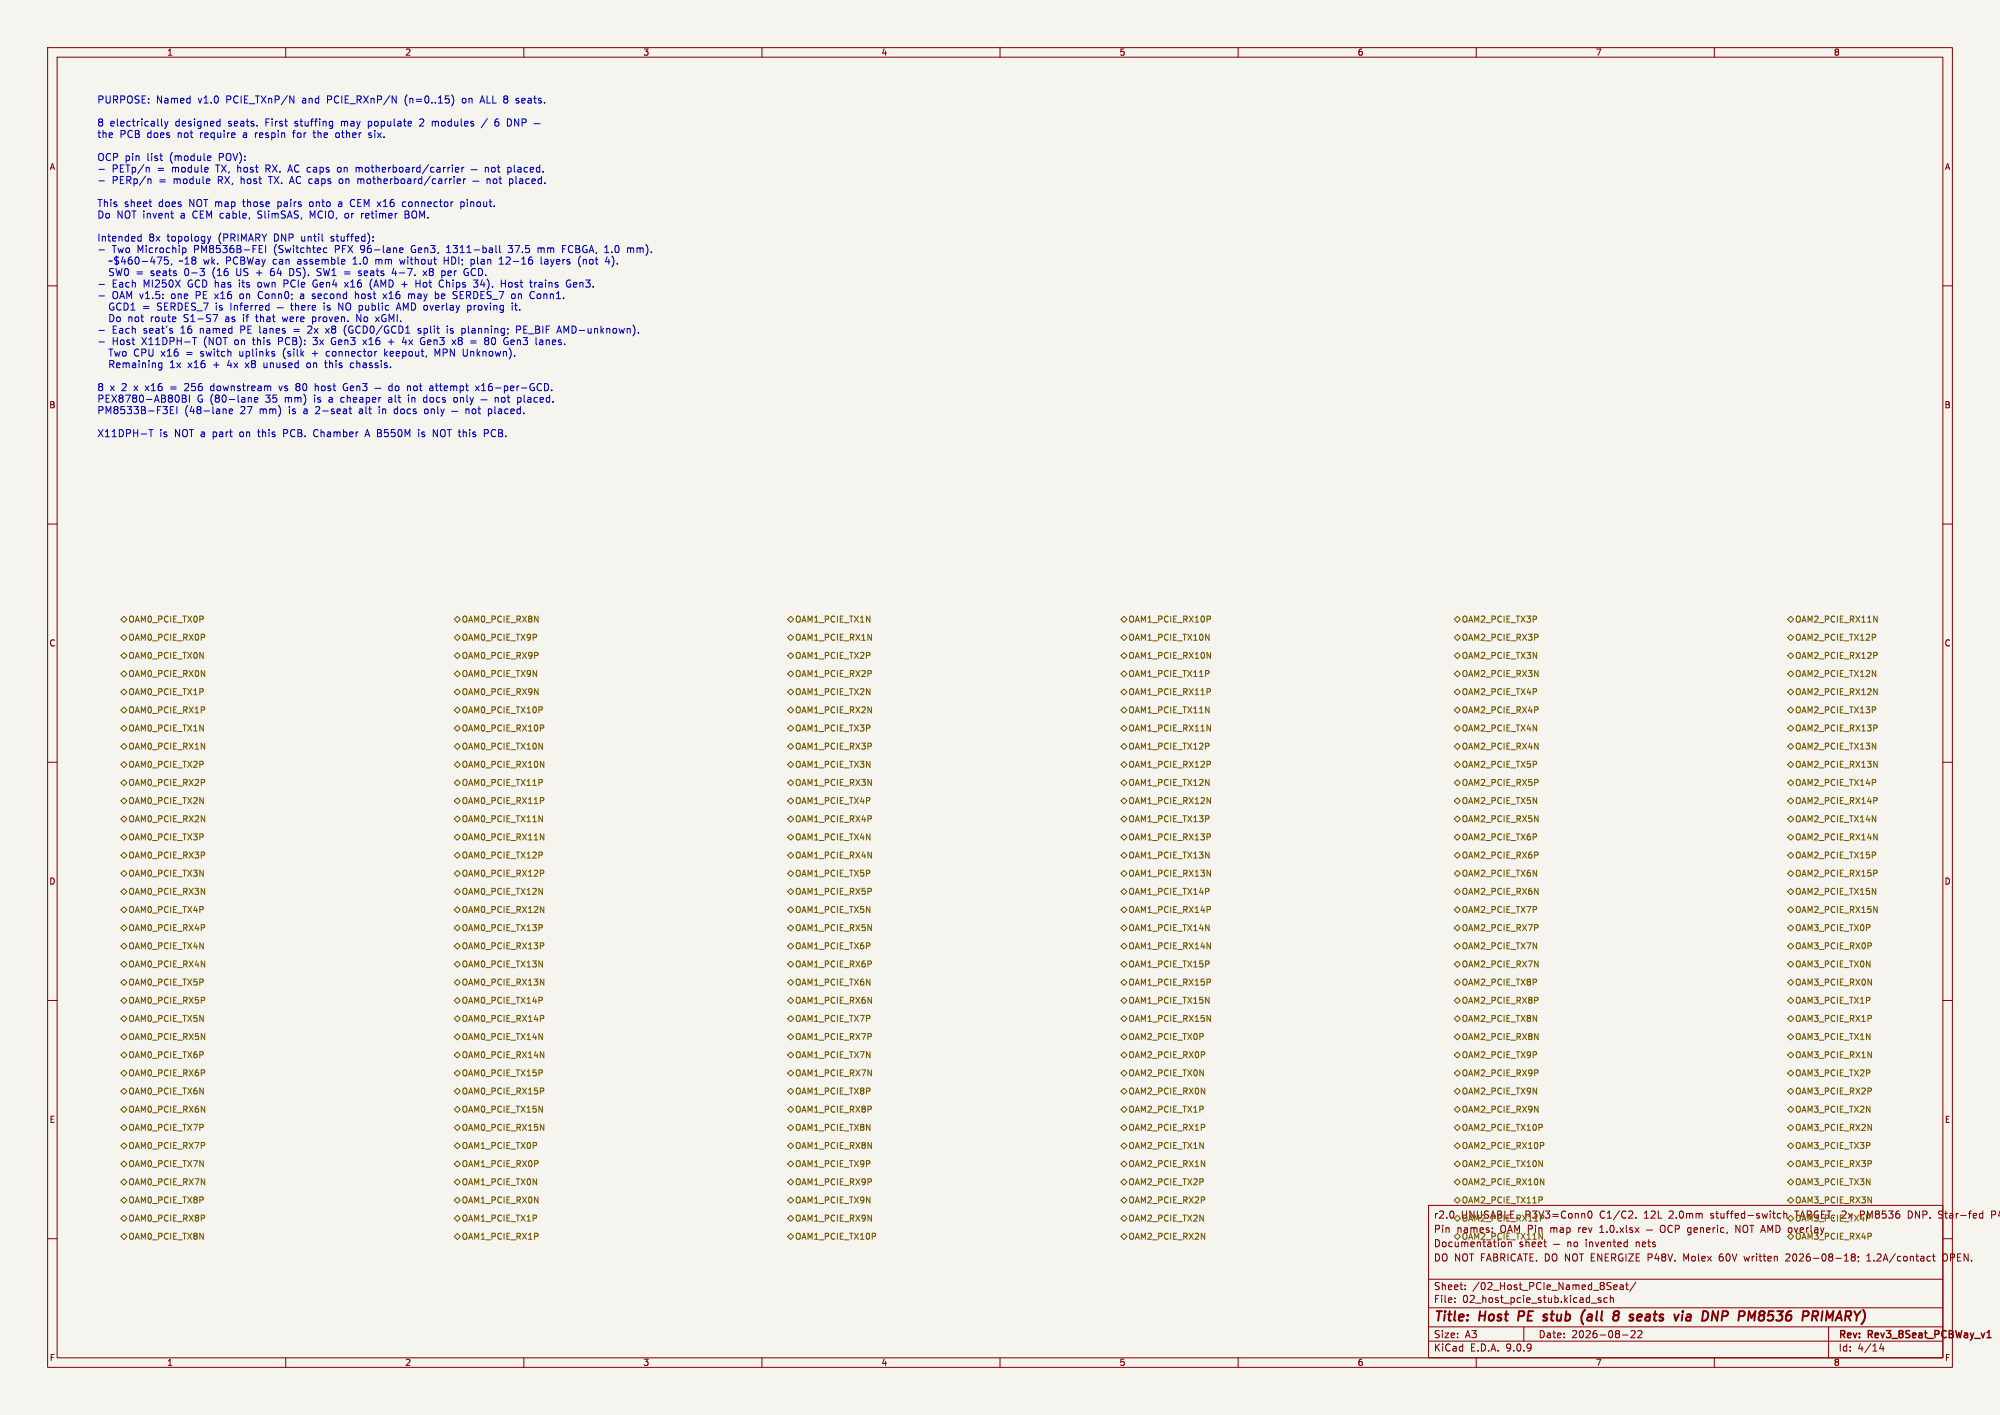
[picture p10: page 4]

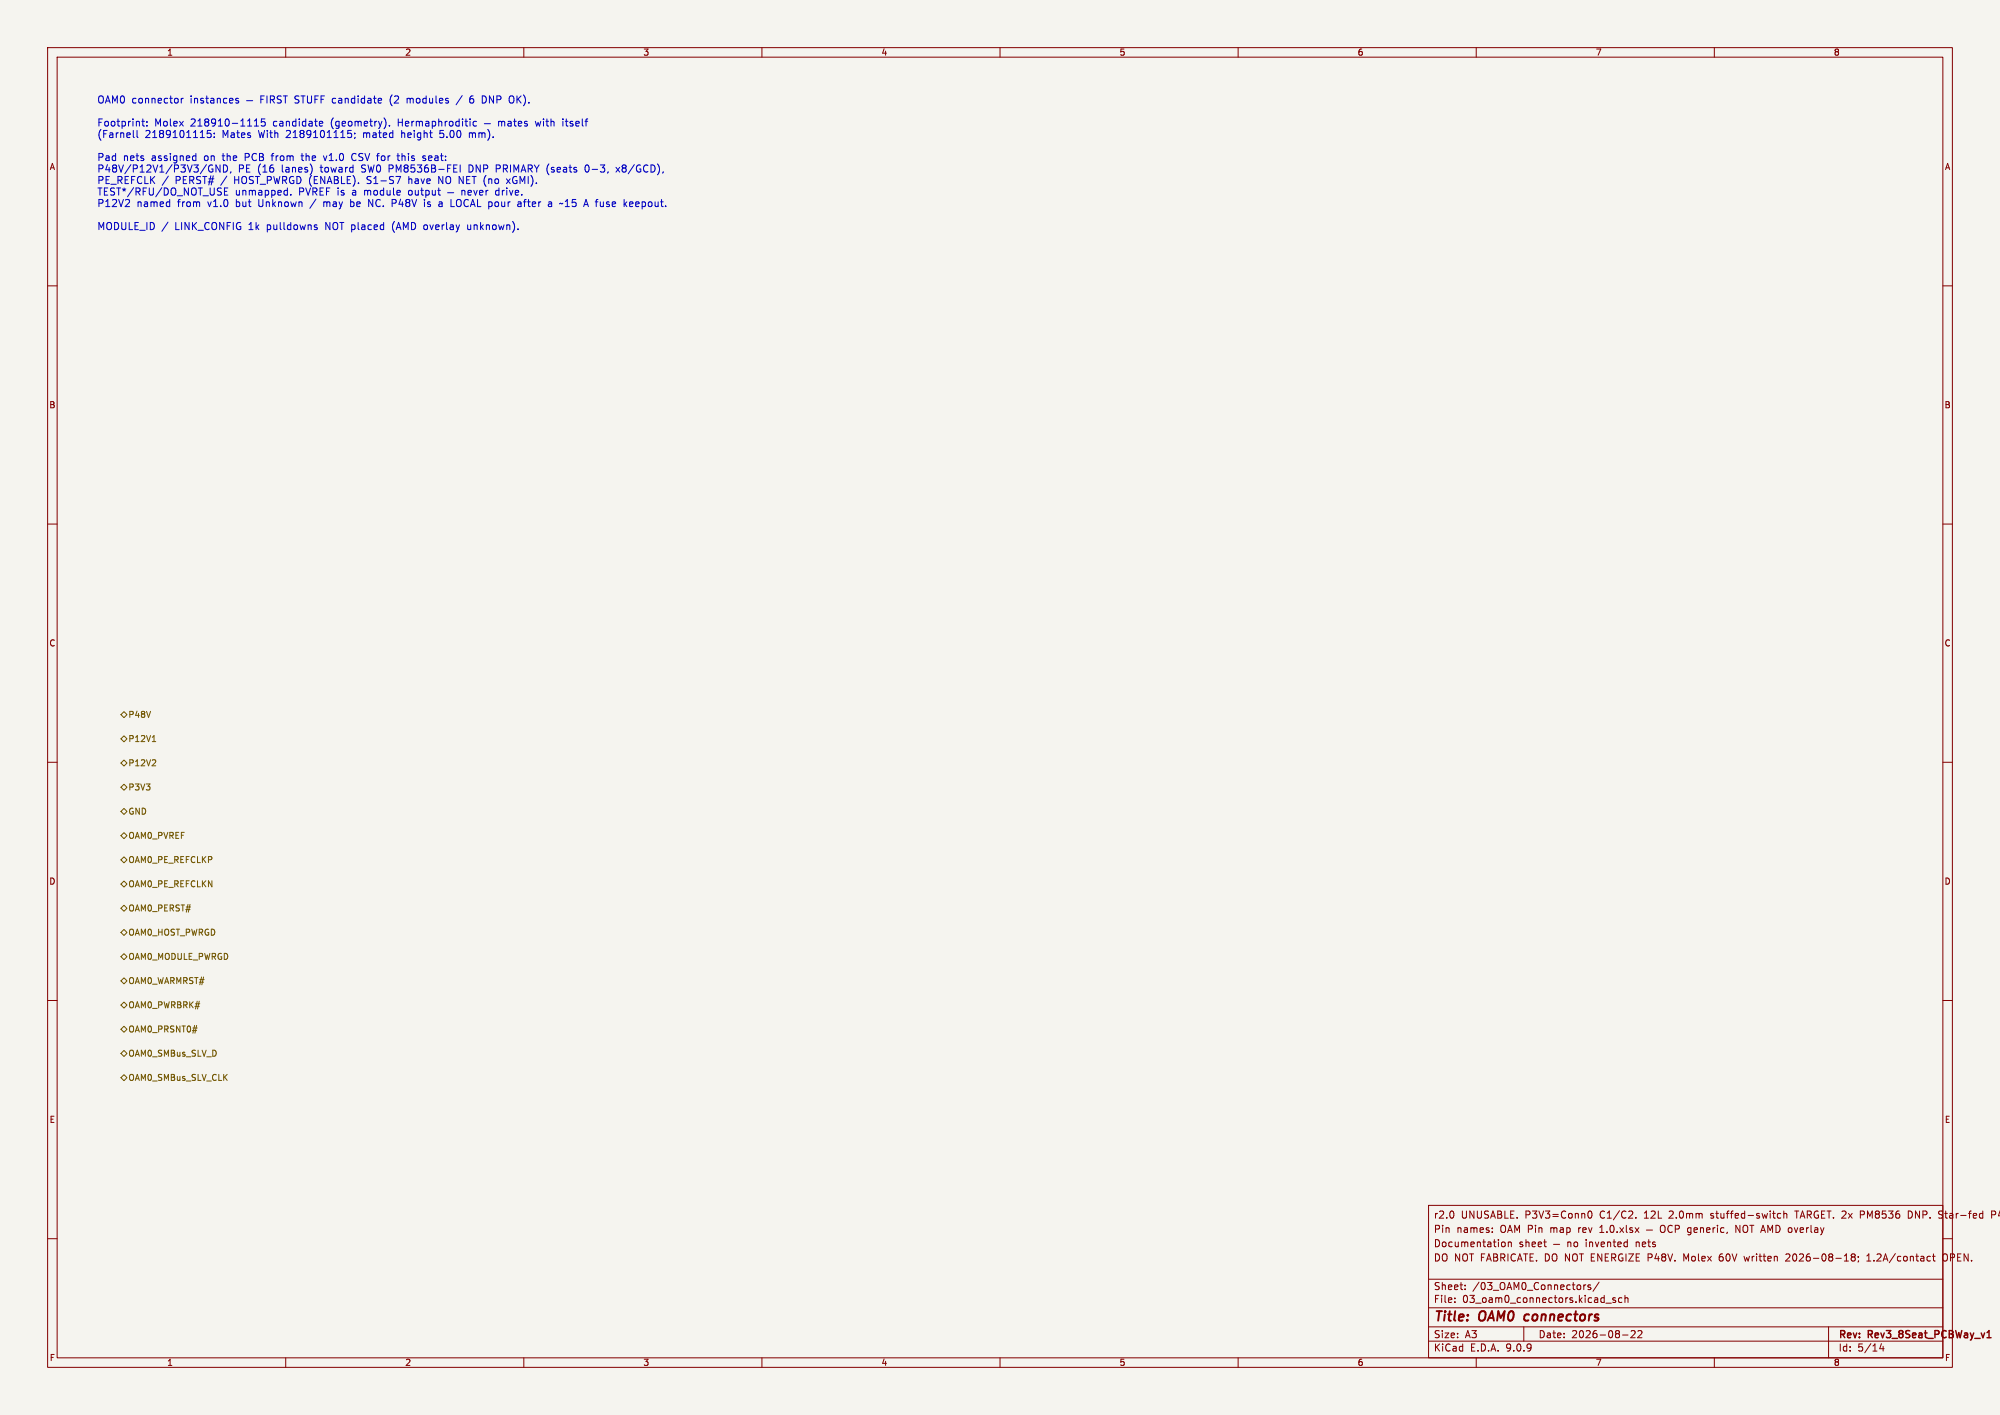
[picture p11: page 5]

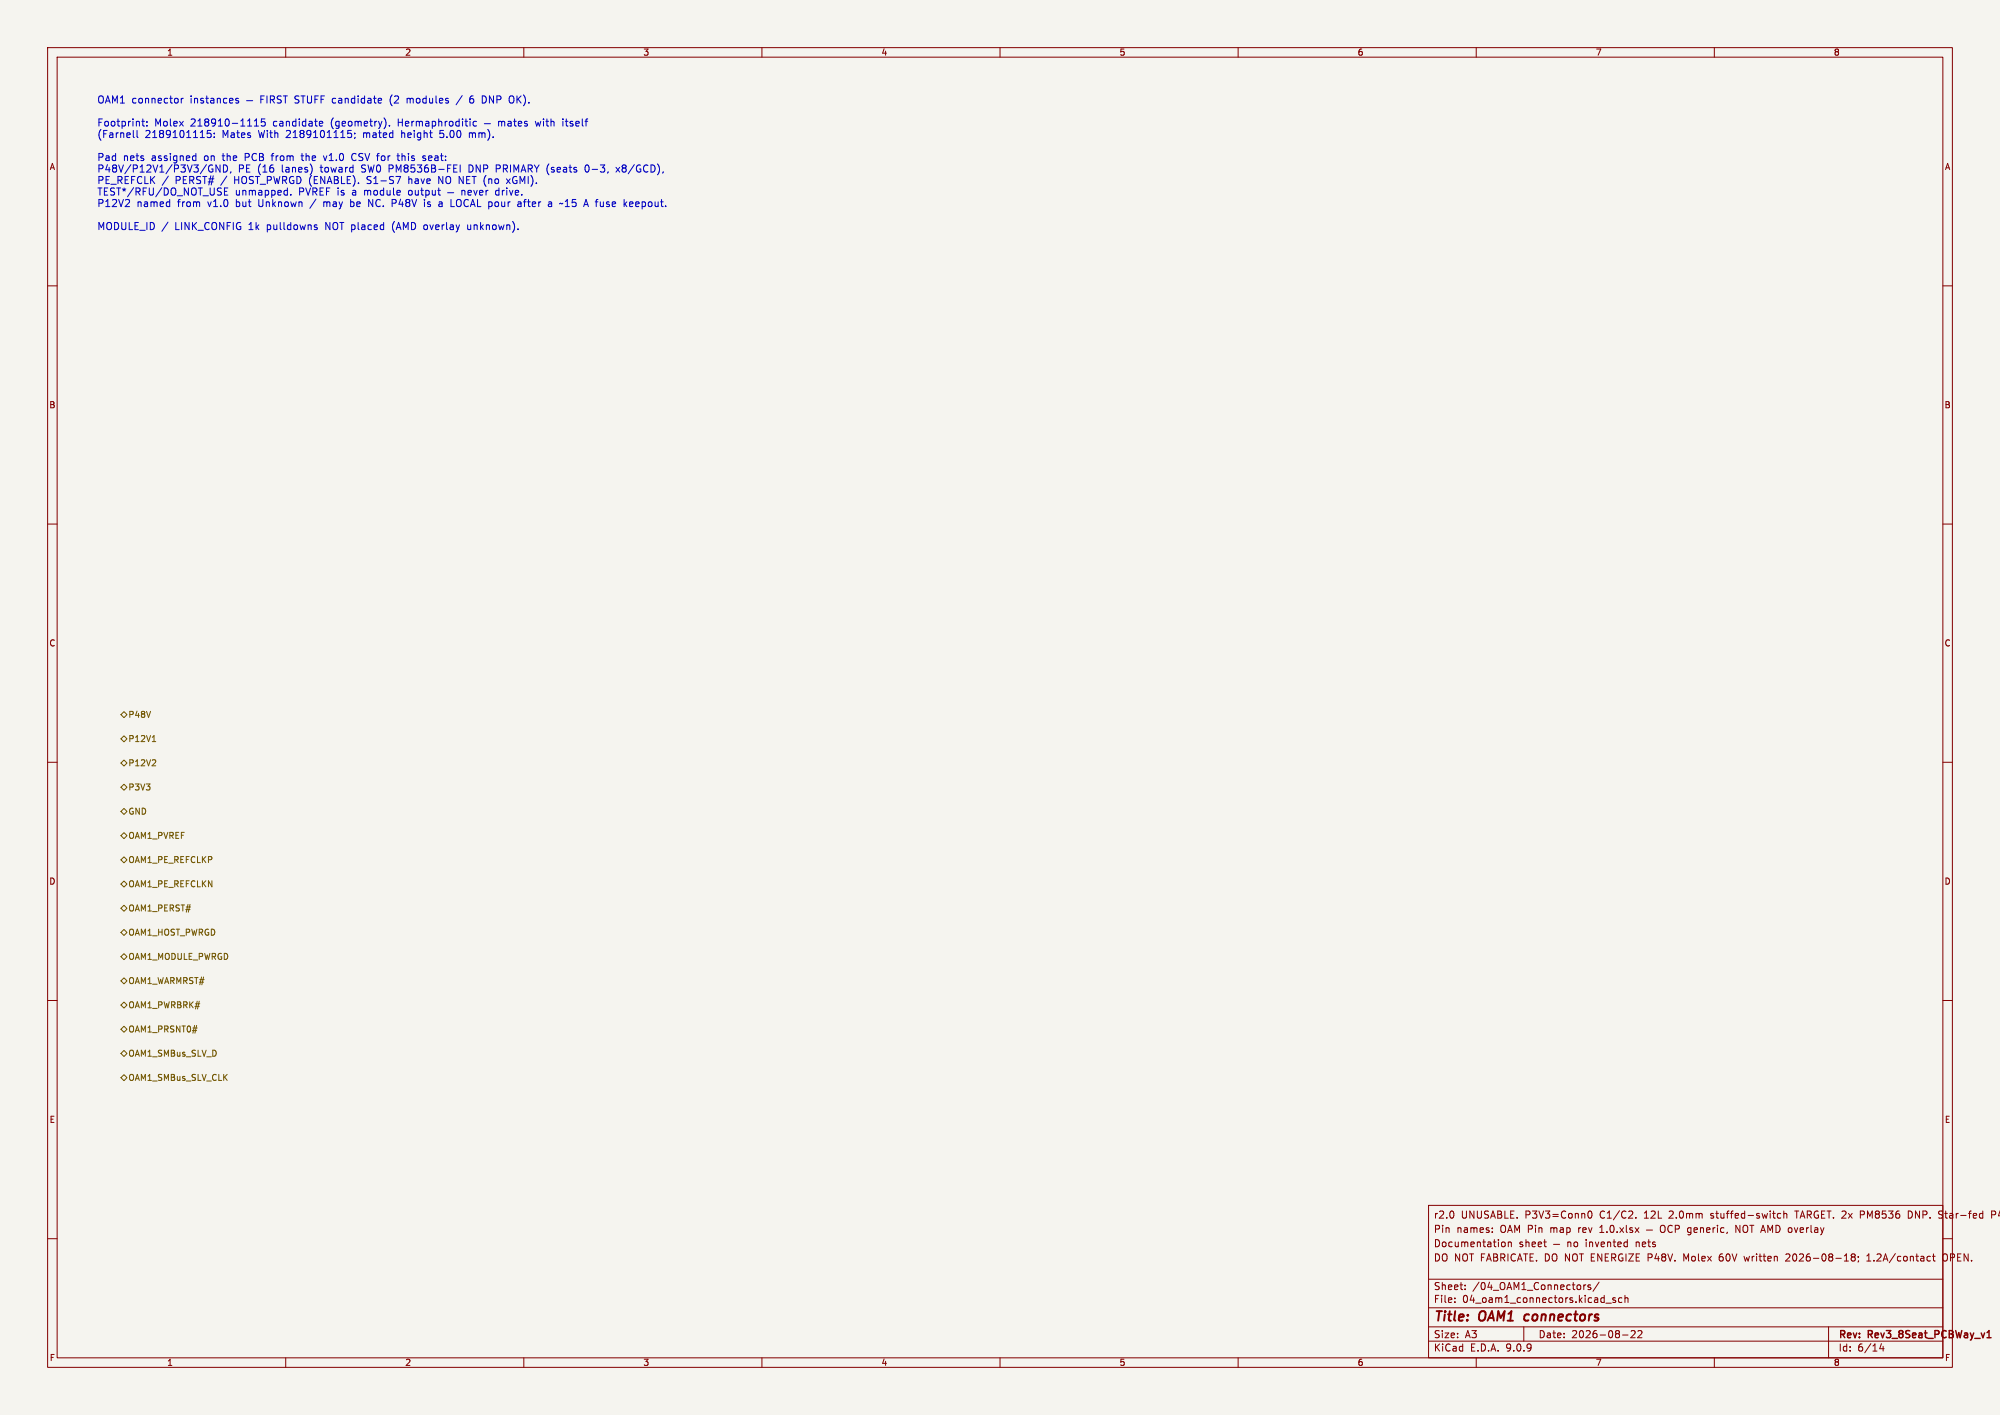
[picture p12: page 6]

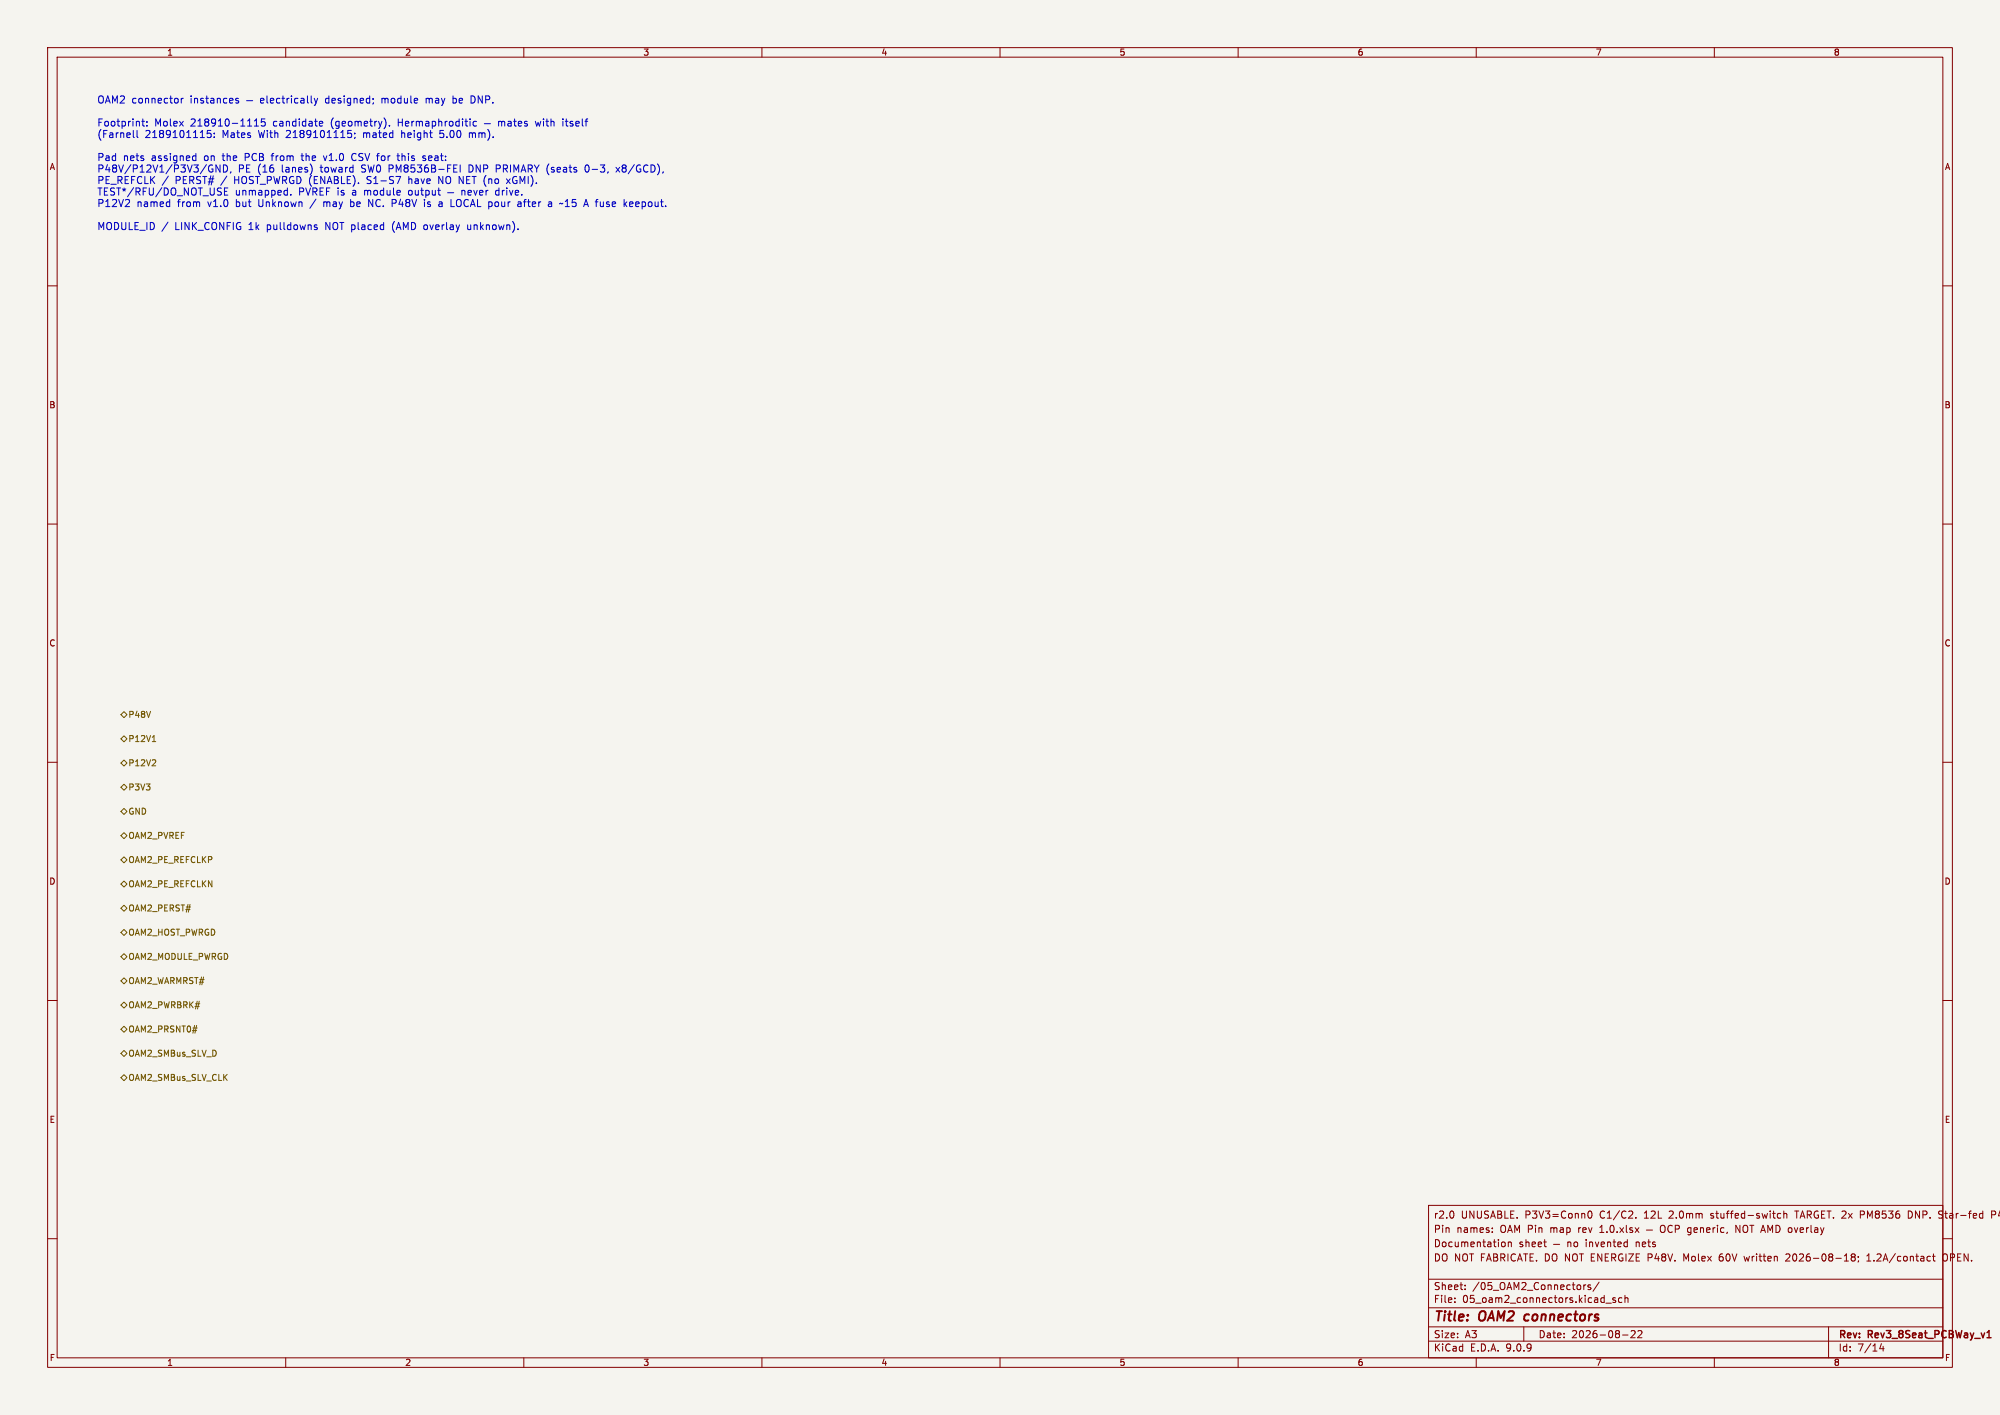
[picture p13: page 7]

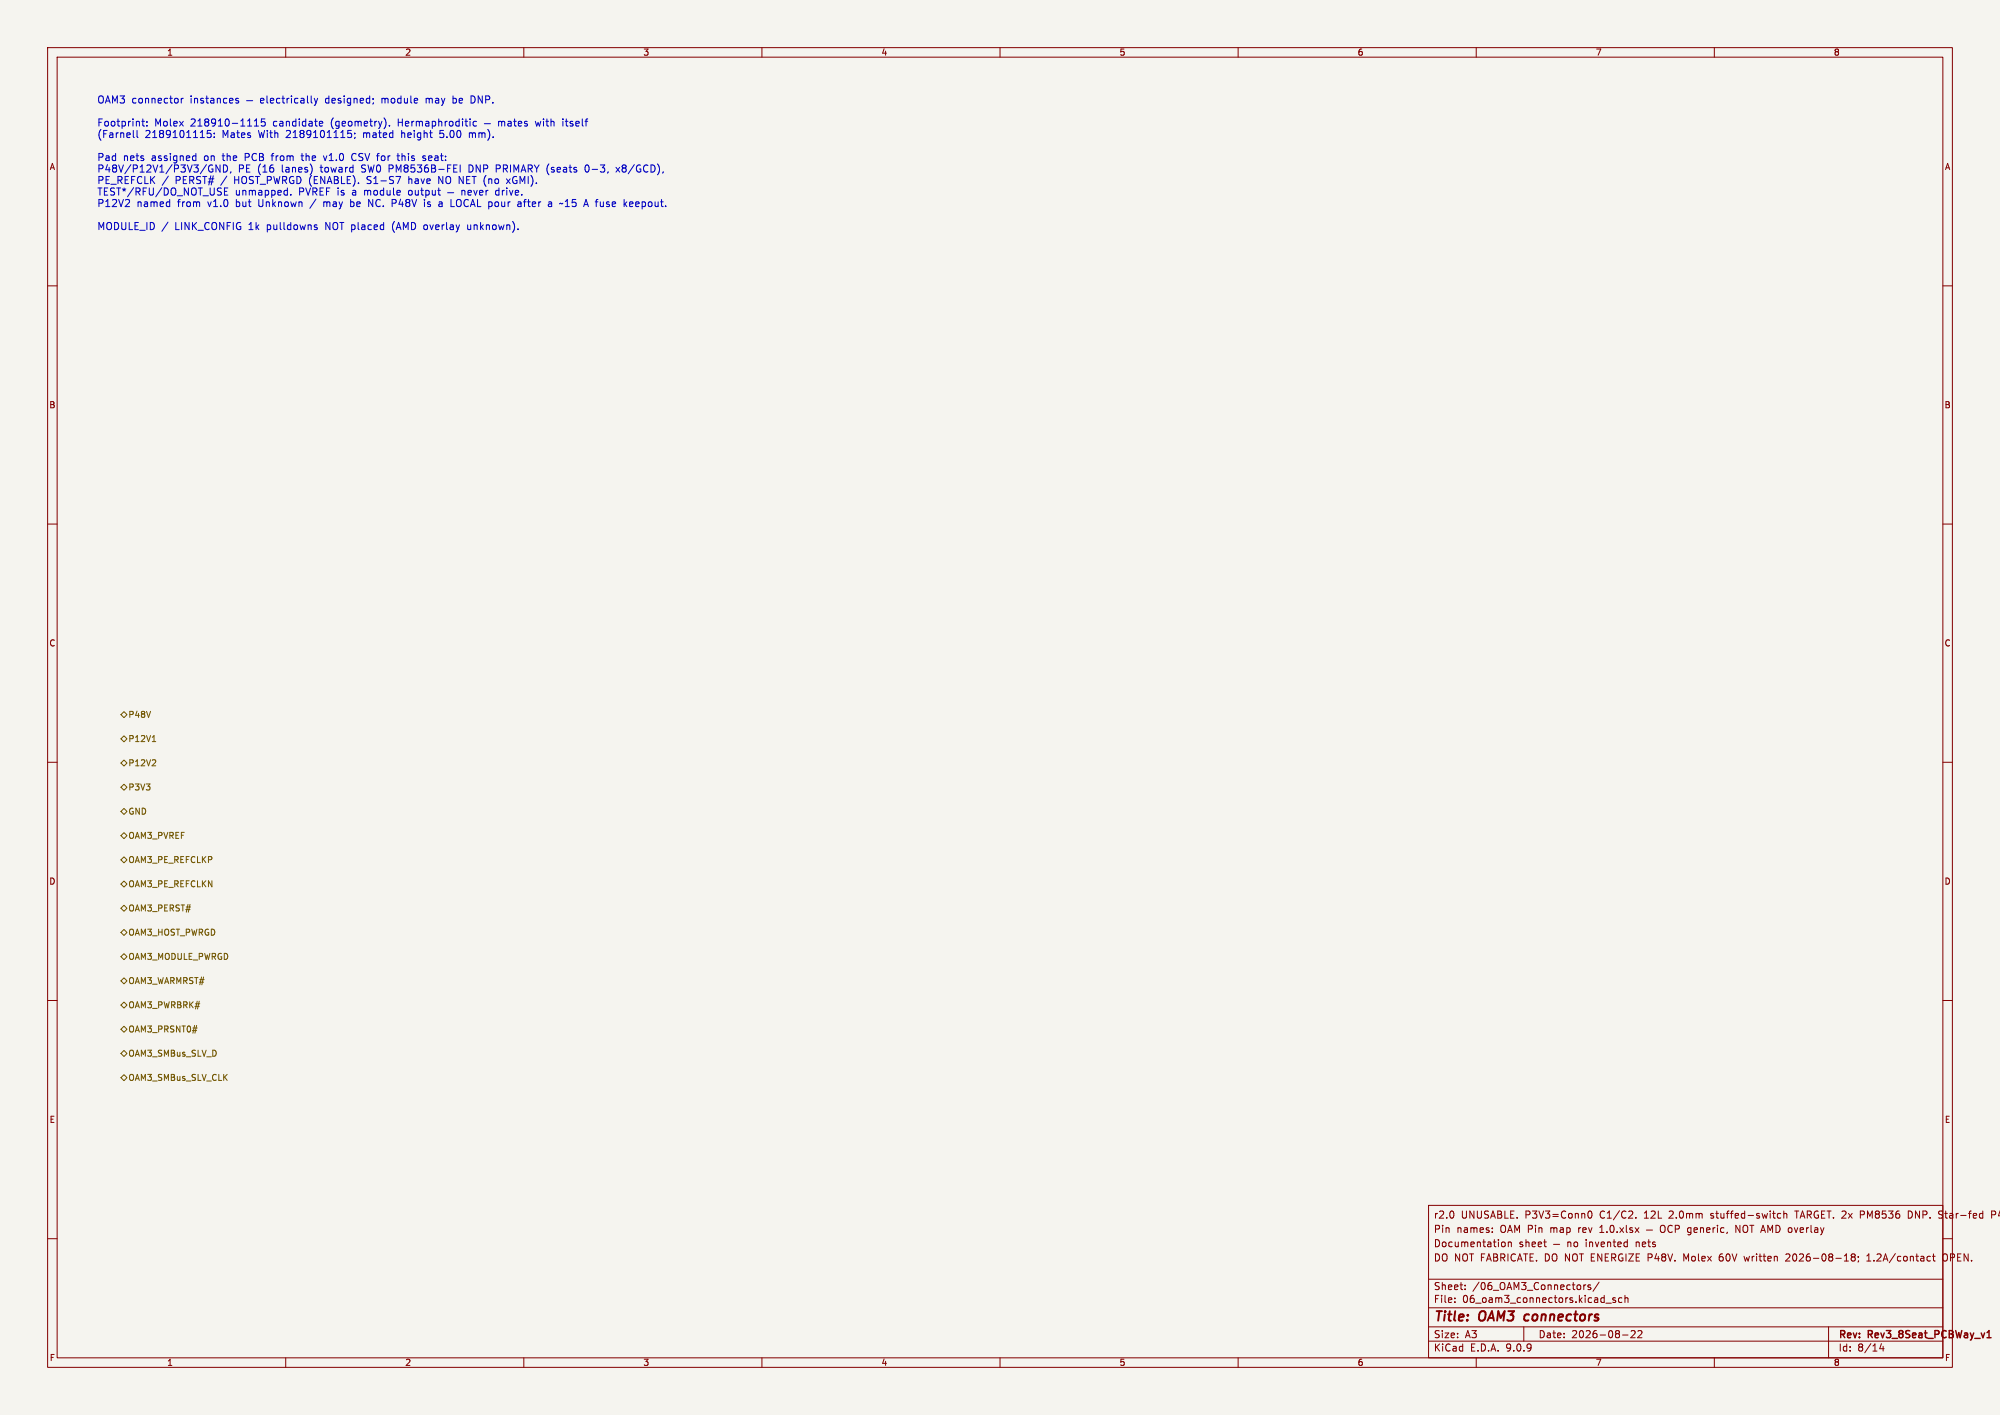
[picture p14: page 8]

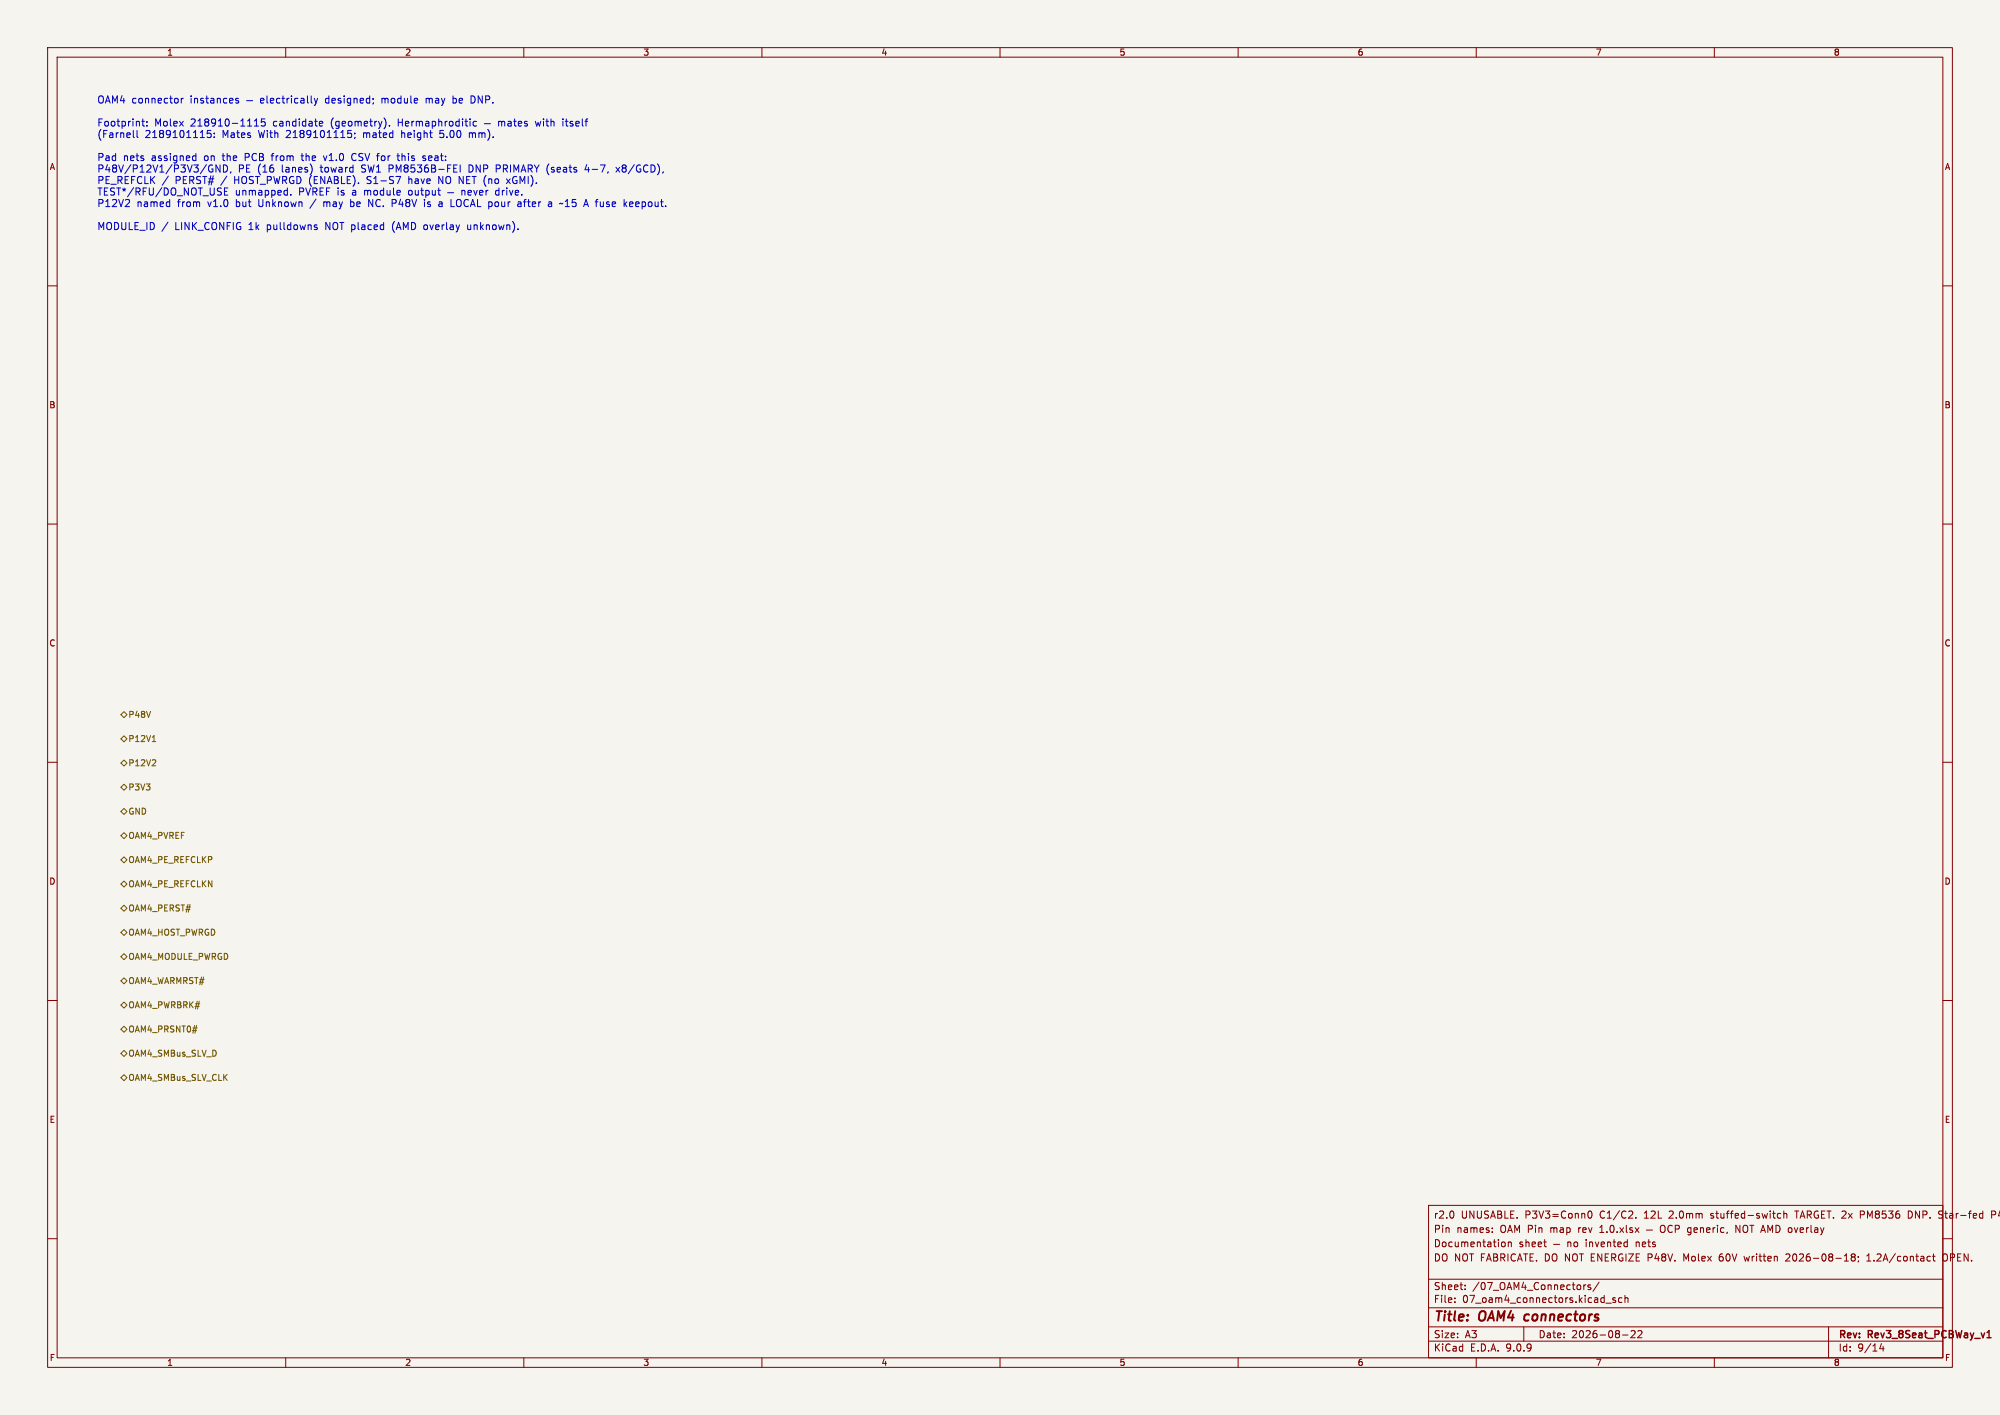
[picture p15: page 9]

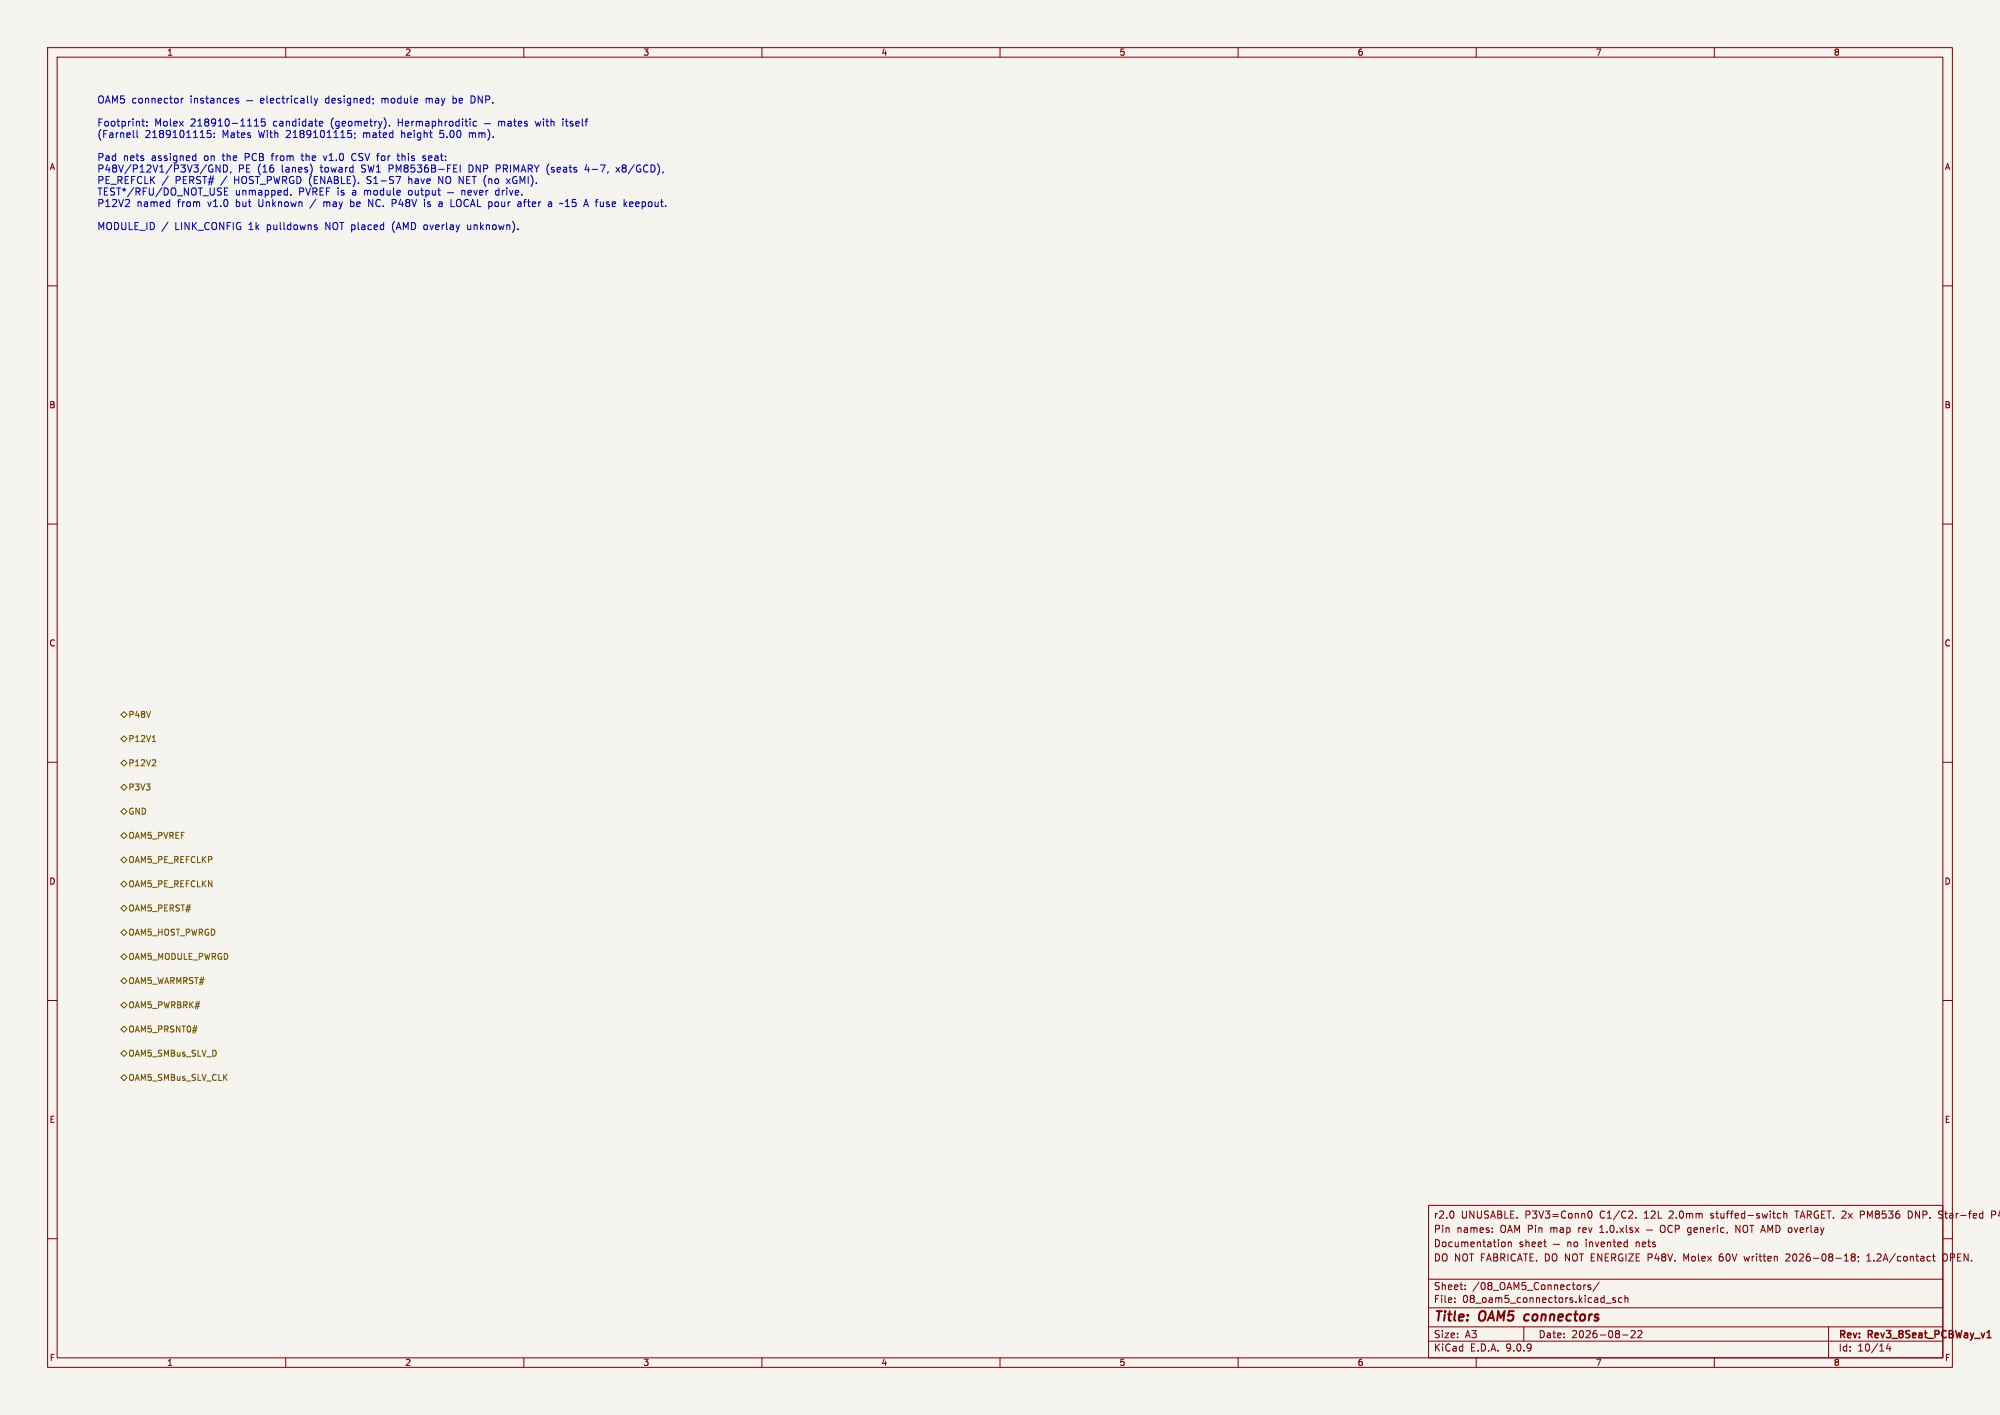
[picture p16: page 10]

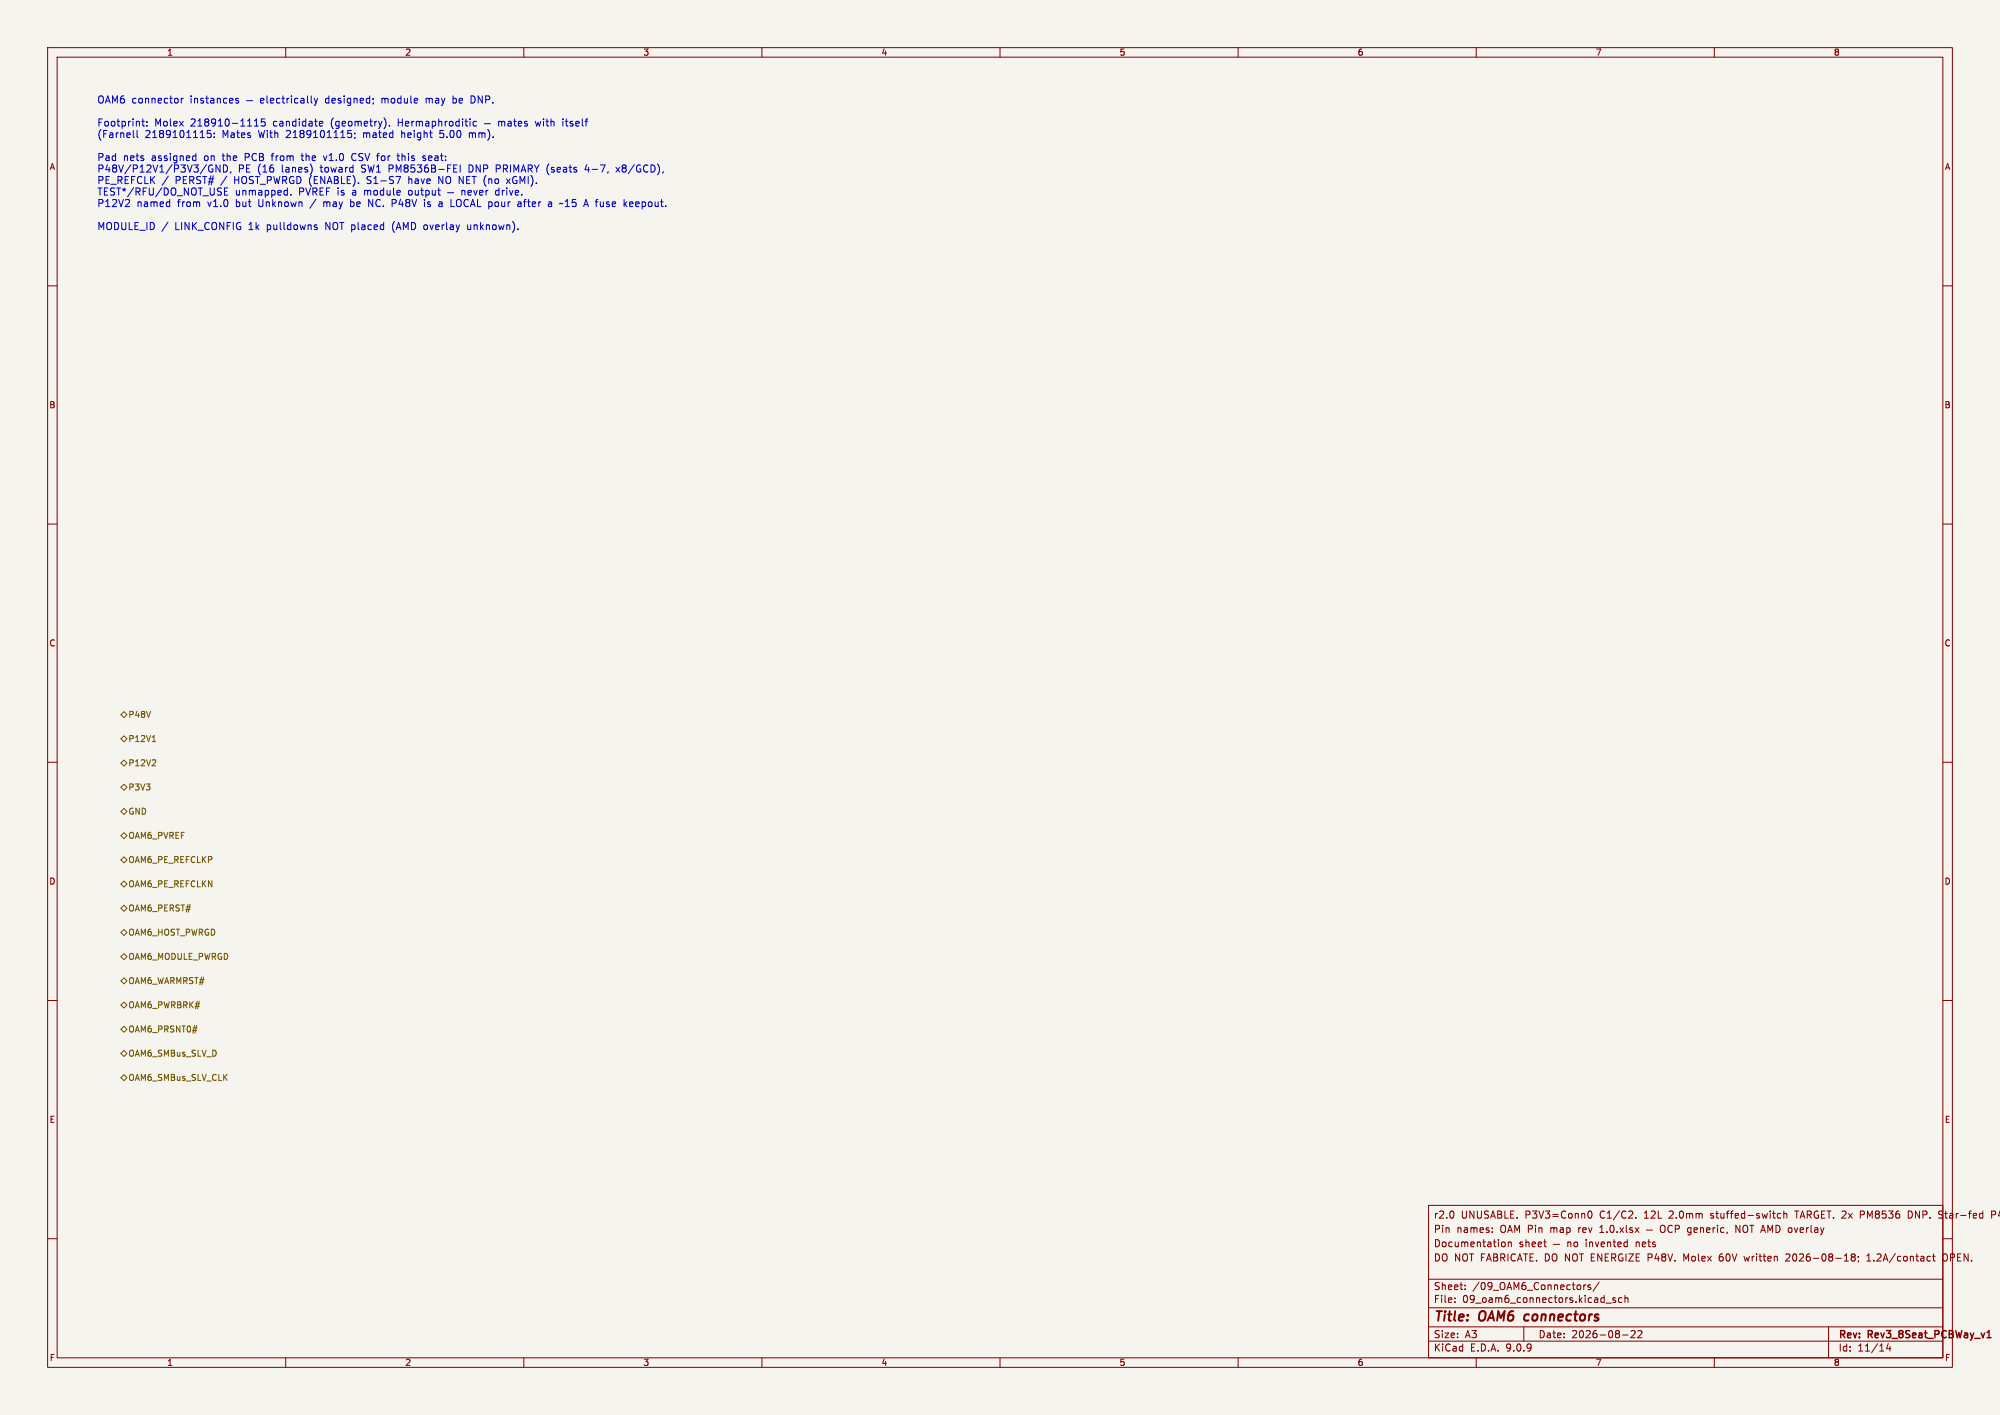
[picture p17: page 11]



(HOST_PWRGD >= 100 ms after MODULE_PWRGD). AMD delays still Unknown.


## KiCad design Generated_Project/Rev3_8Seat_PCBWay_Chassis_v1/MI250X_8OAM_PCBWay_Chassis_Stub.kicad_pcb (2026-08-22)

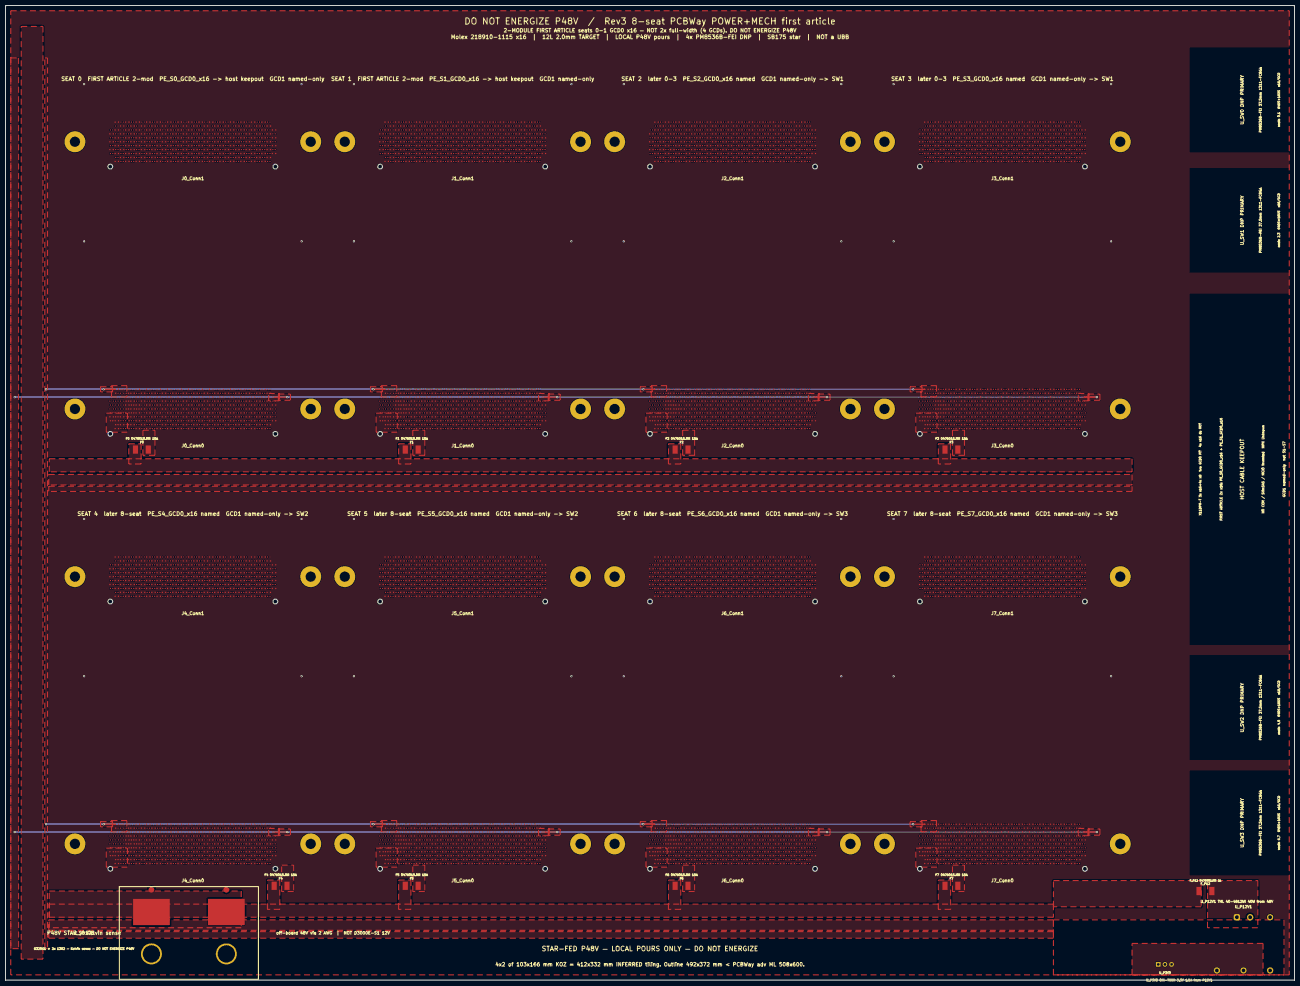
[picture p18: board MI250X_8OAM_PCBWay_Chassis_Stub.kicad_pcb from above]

Board: 12 copper layers, 492.0 x 372.0 mm, 60 parts (0 on the bottom side), 22 nets.

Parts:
F0, F1, F2, F3, F4, F5, F6, F7: 0476015.MR; Fuse_Littelfuse-NANO2-451_453
F_P12: 0476002.MR; Fuse_Littelfuse-NANO2-451_453
H01, H02, H03, H04, H11, H12, H13, H14, H21, H22, H23, H24, H31, H32, H33, H34, H41, H42, H43, H44, H51, H52, H53, H54, H61, H62, H63, H64, H71, H72, H73, H74: NPTH_3.9; NPTH_3.9_Fig2
J0_Conn0, J0_Conn1, J1_Conn0, J1_Conn1, J2_Conn0, J2_Conn1, J3_Conn0, J3_Conn1, J4_Conn0, J4_Conn1, J5_Conn0, J5_Conn1, J6_Conn0, J6_Conn1, J7_Conn0, J7_Conn1: 218910-1115; 218910-1115_candidate
J_SB175: 6325G1_SB175; Anderson_SB175_2pole
U_P3V3: OKI-78SR-3.3/1.5-W36-C; Converter_DCDC_Murata_OKI-78SR_Vertical
U_P12V1: THL 40-4812WI; Converter_DCDC_TRACO_THL40-xxxxWI_THT

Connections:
GND: J0_Conn0.A5, J0_Conn0.A6, J0_Conn0.A9, J0_Conn0.A10, J0_Conn0.A13, J0_Conn0.A14, J0_Conn0.A17, J0_Conn0.A18, J0_Conn0.A21, J0_Conn0.A22, J0_Conn0.A25, J0_Conn0.A26, J0_Conn0.A29, J0_Conn0.A30, J0_Conn0.A33, J0_Conn0.A34, J0_Conn0.A37, J0_Conn0.A38, J0_Conn0.A41, J0_Conn0.A42, J0_Conn0.A45, J0_Conn0.A46, J0_Conn0.A49, J0_Conn0.A50, J0_Conn0.A53, J0_Conn0.A54, J0_Conn0.A57, J0_Conn0.A58, J0_Conn0.B3, J0_Conn0.B4, J0_Conn0.B7, J0_Conn0.B8, J0_Conn0.B11, J0_Conn0.B12, J0_Conn0.B15, J0_Conn0.B16, J0_Conn0.B19, J0_Conn0.B20, J0_Conn0.B23, J0_Conn0.B24, J0_Conn0.B27, J0_Conn0.B28, J0_Conn0.B31, J0_Conn0.B32, J0_Conn0.B35, J0_Conn0.B36, J0_Conn0.B39, J0_Conn0.B40, J0_Conn0.B43, J0_Conn0.B44, J0_Conn0.B47, J0_Conn0.B48, J0_Conn0.B51, J0_Conn0.B52, J0_Conn0.B55, J0_Conn0.B56, J0_Conn0.B57, J0_Conn0.B58, J0_Conn0.C5, J0_Conn0.C6, J0_Conn0.C9, J0_Conn0.C10, J0_Conn0.C13, J0_Conn0.C14, J0_Conn0.C17, J0_Conn0.C18, J0_Conn0.C21, J0_Conn0.C22, J0_Conn0.C25, J0_Conn0.C26, J0_Conn0.C29, J0_Conn0.C30, J0_Conn0.C33, J0_Conn0.C34, J0_Conn0.C37, J0_Conn0.C38, J0_Conn0.C41, J0_Conn0.C42, J0_Conn0.C45, J0_Conn0.C46, J0_Conn0.C49, J0_Conn0.C50, J0_Conn0.C53, J0_Conn0.C54, J0_Conn0.C57, J0_Conn0.C58, J0_Conn0.D3, J0_Conn0.D4, J0_Conn0.D7, J0_Conn0.D8, J0_Conn0.D11, J0_Conn0.D12, J0_Conn0.D15, J0_Conn0.D16, J0_Conn0.D19, J0_Conn0.D20, J0_Conn0.D23, J0_Conn0.D24, J0_Conn0.D27, J0_Conn0.D28, J0_Conn0.D31, J0_Conn0.D32, J0_Conn0.D35, J0_Conn0.D36, J0_Conn0.D39, J0_Conn0.D40, J0_Conn0.D43, J0_Conn0.D44, J0_Conn0.D47, J0_Conn0.D48, J0_Conn0.D51, J0_Conn0.D52, J0_Conn0.D55, J0_Conn0.D56, J0_Conn0.D57, J0_Conn0.D58, J0_Conn0.E1, J0_Conn0.E2, J0_Conn0.E5, J0_Conn0.E6, J0_Conn0.E9, J0_Conn0.E10, J0_Conn0.E13, J0_Conn0.E14, J0_Conn0.E17, J0_Conn0.E18, J0_Conn0.E21, J0_Conn0.E22, J0_Conn0.E25, J0_Conn0.E26, J0_Conn0.E29, J0_Conn0.E30, J0_Conn0.E33, J0_Conn0.E34, J0_Conn0.E37, J0_Conn0.E38, J0_Conn0.E41, J0_Conn0.E42, J0_Conn0.E45, J0_Conn0.E46, J0_Conn0.E49, J0_Conn0.E50, J0_Conn0.E53, J0_Conn0.E54, J0_Conn0.E55, J0_Conn0.E56, J0_Conn0.E57, J0_Conn0.E58, J0_Conn0.F3, J0_Conn0.F4, J0_Conn0.F7, J0_Conn0.F8, J0_Conn0.F11, J0_Conn0.F12, J0_Conn0.F15, J0_Conn0.F16, J0_Conn0.F19, J0_Conn0.F20, J0_Conn0.F23, J0_Conn0.F24, J0_Conn0.F27, J0_Conn0.F28, J0_Conn0.F31, J0_Conn0.F32, J0_Conn0.F35, J0_Conn0.F36, J0_Conn0.F39, J0_Conn0.F40, J0_Conn0.F43, J0_Conn0.F44, J0_Conn0.F47, J0_Conn0.F48, J0_Conn0.F51, J0_Conn0.F52, J0_Conn0.F53, J0_Conn0.F54, J0_Conn0.F55, J0_Conn0.F56, J0_Conn0.F57, J0_Conn0.F58, J0_Conn0.G5, J0_Conn0.G6, J0_Conn0.G9, J0_Conn0.G10, J0_Conn0.G13, J0_Conn0.G14, J0_Conn0.G17, J0_Conn0.G18, J0_Conn0.G21, J0_Conn0.G22, J0_Conn0.G25, J0_Conn0.G26, J0_Conn0.G29, J0_Conn0.G30, J0_Conn0.G33, J0_Conn0.G34, J0_Conn0.G37, J0_Conn0.G38, J0_Conn0.G41, J0_Conn0.G42, J0_Conn0.G45, J0_Conn0.G46, J0_Conn0.G49, J0_Conn0.G50, J0_Conn0.G53, J0_Conn0.G54, J0_Conn0.G55, J0_Conn0.G56, J0_Conn0.G57, J0_Conn0.G58, J0_Conn0.G59, J0_Conn0.G60, J0_Conn0.G61, J0_Conn0.G62, J0_Conn0.G63, J0_Conn0.G64, J0_Conn0.H3, J0_Conn0.H4, J0_Conn0.H7, J0_Conn0.H8, J0_Conn0.H11, J0_Conn0.H12, J0_Conn0.H15, J0_Conn0.H16, J0_Conn0.H19, J0_Conn0.H20, J0_Conn0.H23, J0_Conn0.H24, J0_Conn0.H27, J0_Conn0.H28, J0_Conn0.H31, J0_Conn0.H32, J0_Conn0.H35, J0_Conn0.H36, J0_Conn0.H39, J0_Conn0.H40, J0_Conn0.H43, J0_Conn0.H44, J0_Conn0.H47, J0_Conn0.H48, J0_Conn0.H51, J0_Conn0.H52, J0_Conn0.H55, J0_Conn0.H56, J0_Conn0.H57, J0_Conn0.J1, J0_Conn0.J2, J0_Conn0.J5, J0_Conn0.J6, J0_Conn0.J9, J0_Conn0.J10, J0_Conn0.J13, J0_Conn0.J14, J0_Conn0.J17, J0_Conn0.J18, J0_Conn0.J21, J0_Conn0.J22, J0_Conn0.J25, J0_Conn0.J26, J0_Conn0.J29, J0_Conn0.J30, J0_Conn0.J33, J0_Conn0.J34, J0_Conn0.J37, J0_Conn0.J38, J0_Conn0.J41, J0_Conn0.J42, J0_Conn0.J45, J0_Conn0.J46, J0_Conn0.J49, J0_Conn0.J50, J0_Conn0.J53, J0_Conn0.J54, J0_Conn0.J57, J0_Conn0.J58, J0_Conn0.J59, J0_Conn0.K3, J0_Conn0.K4, J0_Conn0.K7, J0_Conn0.K8, J0_Conn0.K11, J0_Conn0.K12, J0_Conn0.K15, J0_Conn0.K16, J0_Conn0.K19, J0_Conn0.K20, J0_Conn0.K23, J0_Conn0.K24, J0_Conn0.K27, J0_Conn0.K28, J0_Conn0.K31, J0_Conn0.K32, J0_Conn0.K35, J0_Conn0.K36, J0_Conn0.K39, J0_Conn0.K40, J0_Conn0.K43, J0_Conn0.K44, J0_Conn0.K47, J0_Conn0.K48, J0_Conn0.K51, J0_Conn0.K52, J0_Conn0.K55, J0_Conn0.K56, J0_Conn0.K57, J0_Conn0.L5, J0_Conn0.L6, J0_Conn0.L9, J0_Conn0.L10, J0_Conn0.L13, J0_Conn0.L14, J0_Conn0.L17, J0_Conn0.L18, J0_Conn0.L21, J0_Conn0.L22, J0_Conn0.L25, J0_Conn0.L26, J0_Conn0.L29, J0_Conn0.L30, J0_Conn0.L33, J0_Conn0.L34, J0_Conn0.L37, J0_Conn0.L38, J0_Conn0.L41, J0_Conn0.L42, J0_Conn0.L45, J0_Conn0.L46, J0_Conn0.L49, J0_Conn0.L50, J0_Conn0.L53, J0_Conn0.L54, J0_Conn0.L57, J0_Conn0.L58, J0_Conn0.L59, J0_Conn1.A5, J0_Conn1.A6, J0_Conn1.A9, J0_Conn1.A10, J0_Conn1.A13, J0_Conn1.A14, J0_Conn1.A17, J0_Conn1.A18, J0_Conn1.A21, J0_Conn1.A22, J0_Conn1.A25, J0_Conn1.A26, J0_Conn1.A29, J0_Conn1.A30, J0_Conn1.A33, J0_Conn1.A34, J0_Conn1.A37, J0_Conn1.A38, J0_Conn1.A41, J0_Conn1.A42, J0_Conn1.A45, J0_Conn1.A46, J0_Conn1.A49, J0_Conn1.A50, J0_Conn1.A53, J0_Conn1.A54, J0_Conn1.A57, J0_Conn1.A58, J0_Conn1.A61, J0_Conn1.A62, J0_Conn1.B3, J0_Conn1.B4, J0_Conn1.B7, J0_Conn1.B8, J0_Conn1.B11, J0_Conn1.B12, J0_Conn1.B15, J0_Conn1.B16, J0_Conn1.B19, J0_Conn1.B20, J0_Conn1.B23, J0_Conn1.B24, J0_Conn1.B27, J0_Conn1.B28, J0_Conn1.B31, J0_Conn1.B32, J0_Conn1.B35, J0_Conn1.B36, J0_Conn1.B39, J0_Conn1.B40, J0_Conn1.B43, J0_Conn1.B44, J0_Conn1.B47, J0_Conn1.B48, J0_Conn1.B51, J0_Conn1.B52, J0_Conn1.B55, J0_Conn1.B56, J0_Conn1.B59, J0_Conn1.B60, J0_Conn1.C1, J0_Conn1.C2, J0_Conn1.C5, J0_Conn1.C6, J0_Conn1.C9, J0_Conn1.C10, J0_Conn1.C13, J0_Conn1.C14, J0_Conn1.C17, J0_Conn1.C18, J0_Conn1.C21, J0_Conn1.C22, J0_Conn1.C25, J0_Conn1.C26, J0_Conn1.C29, J0_Conn1.C30, J0_Conn1.C33, J0_Conn1.C34, J0_Conn1.C37, J0_Conn1.C38, J0_Conn1.C41, J0_Conn1.C42, J0_Conn1.C45, J0_Conn1.C46, J0_Conn1.C49, J0_Conn1.C50, J0_Conn1.C53, J0_Conn1.C54, J0_Conn1.C57, J0_Conn1.C58, J0_Conn1.C61, J0_Conn1.C62, J0_Conn1.D3, J0_Conn1.D4, J0_Conn1.D7, J0_Conn1.D8, J0_Conn1.D11, J0_Conn1.D12, J0_Conn1.D15, J0_Conn1.D16, J0_Conn1.D19, J0_Conn1.D20, J0_Conn1.D23, J0_Conn1.D24, J0_Conn1.D27, J0_Conn1.D28, J0_Conn1.D31, J0_Conn1.D32, J0_Conn1.D35, J0_Conn1.D36, J0_Conn1.D39, J0_Conn1.D40, J0_Conn1.D43, J0_Conn1.D44, J0_Conn1.D47, J0_Conn1.D48, J0_Conn1.D51, J0_Conn1.D52, J0_Conn1.D55, J0_Conn1.D56, J0_Conn1.D59, J0_Conn1.D60, J0_Conn1.D63, J0_Conn1.D64, J0_Conn1.E1, J0_Conn1.E2, J0_Conn1.E5, J0_Conn1.E6, J0_Conn1.E9, J0_Conn1.E10, J0_Conn1.E13, J0_Conn1.E14, J0_Conn1.E17, J0_Conn1.E18, J0_Conn1.E21, J0_Conn1.E22, J0_Conn1.E25, J0_Conn1.E26, J0_Conn1.E29, J0_Conn1.E30, J0_Conn1.E33, J0_Conn1.E34, J0_Conn1.E37, J0_Conn1.E38, J0_Conn1.E41, J0_Conn1.E42, J0_Conn1.E45, J0_Conn1.E46, J0_Conn1.E49, J0_Conn1.E50, J0_Conn1.E53, J0_Conn1.E54, J0_Conn1.E57, J0_Conn1.E58, J0_Conn1.E61, J0_Conn1.E62, J0_Conn1.F3, J0_Conn1.F4, J0_Conn1.F7, J0_Conn1.F8, J0_Conn1.F11, J0_Conn1.F12, J0_Conn1.F15, J0_Conn1.F16, J0_Conn1.F19, J0_Conn1.F20, J0_Conn1.F23, J0_Conn1.F24, J0_Conn1.F27, J0_Conn1.F28, J0_Conn1.F31, J0_Conn1.F32, J0_Conn1.F35, J0_Conn1.F36, J0_Conn1.F39, J0_Conn1.F40, J0_Conn1.F43, J0_Conn1.F44, J0_Conn1.F47, J0_Conn1.F48, J0_Conn1.F51, J0_Conn1.F52, J0_Conn1.F55, J0_Conn1.F56, J0_Conn1.F59, J0_Conn1.F60, J0_Conn1.F63, J0_Conn1.F64, J0_Conn1.G1, J0_Conn1.G2, J0_Conn1.G5, J0_Conn1.G6, J0_Conn1.G9, J0_Conn1.G10, J0_Conn1.G13, J0_Conn1.G14, J0_Conn1.G17, J0_Conn1.G18, J0_Conn1.G21, J0_Conn1.G22, J0_Conn1.G25, J0_Conn1.G26, J0_Conn1.G29, J0_Conn1.G30, J0_Conn1.G33, J0_Conn1.G34, J0_Conn1.G37, J0_Conn1.G38, J0_Conn1.G41, J0_Conn1.G42, J0_Conn1.G45, J0_Conn1.G46, J0_Conn1.G49, J0_Conn1.G50, J0_Conn1.G53, J0_Conn1.G54, J0_Conn1.G57, J0_Conn1.G58, J0_Conn1.G61, J0_Conn1.G62, J0_Conn1.H3, J0_Conn1.H4, J0_Conn1.H7, J0_Conn1.H8, J0_Conn1.H11, J0_Conn1.H12, J0_Conn1.H15, J0_Conn1.H16, J0_Conn1.H19, J0_Conn1.H20, J0_Conn1.H23, J0_Conn1.H24, J0_Conn1.H27, J0_Conn1.H28, J0_Conn1.H31, J0_Conn1.H32, J0_Conn1.H35, J0_Conn1.H36, J0_Conn1.H39, J0_Conn1.H40, J0_Conn1.H43, J0_Conn1.H44, J0_Conn1.H47, J0_Conn1.H48, J0_Conn1.H51, J0_Conn1.H52, J0_Conn1.H55, J0_Conn1.H56, J0_Conn1.H59, J0_Conn1.H60, J0_Conn1.H63, J0_Conn1.H64, J0_Conn1.J1, J0_Conn1.J2, J0_Conn1.J5, J0_Conn1.J6, J0_Conn1.J9, J0_Conn1.J10, J0_Conn1.J13, J0_Conn1.J14, J0_Conn1.J17, J0_Conn1.J18, J0_Conn1.J21, J0_Conn1.J22, J0_Conn1.J25, J0_Conn1.J26, J0_Conn1.J29, J0_Conn1.J30, J0_Conn1.J33, J0_Conn1.J34, J0_Conn1.J37, J0_Conn1.J38, J0_Conn1.J41, J0_Conn1.J42, J0_Conn1.J45, J0_Conn1.J46, J0_Conn1.J49, J0_Conn1.J50, J0_Conn1.J53, J0_Conn1.J54, J0_Conn1.J57, J0_Conn1.J58, J0_Conn1.J61, J0_Conn1.J62, J0_Conn1.K3, J0_Conn1.K4, J0_Conn1.K7, J0_Conn1.K8, J0_Conn1.K11, J0_Conn1.K12, J0_Conn1.K15, J0_Conn1.K16, J0_Conn1.K19, J0_Conn1.K20, J0_Conn1.K23, J0_Conn1.K24, J0_Conn1.K27, J0_Conn1.K28, J0_Conn1.K31, J0_Conn1.K32, J0_Conn1.K35, J0_Conn1.K36, J0_Conn1.K39, J0_Conn1.K40, J0_Conn1.K43, J0_Conn1.K44, J0_Conn1.K47, J0_Conn1.K48, J0_Conn1.K51, J0_Conn1.K52, J0_Conn1.K55, J0_Conn1.K56, J0_Conn1.K59, J0_Conn1.K60, J0_Conn1.L5, J0_Conn1.L6, J0_Conn1.L9, J0_Conn1.L10, J0_Conn1.L13, J0_Conn1.L14, J0_Conn1.L17, J0_Conn1.L18, J0_Conn1.L21, J0_Conn1.L22, J0_Conn1.L25, J0_Conn1.L26, J0_Conn1.L29, J0_Conn1.L30, J0_Conn1.L33, J0_Conn1.L34, J0_Conn1.L37, J0_Conn1.L38, J0_Conn1.L41, J0_Conn1.L42, J0_Conn1.L45, J0_Conn1.L46, J0_Conn1.L49, J0_Conn1.L50, J0_Conn1.L53, J0_Conn1.L54, J0_Conn1.L57, J0_Conn1.L58, J0_Conn1.L61, J0_Conn1.L62, J1_Conn0.A5, J1_Conn0.A6, J1_Conn0.A9, J1_Conn0.A10, J1_Conn0.A13, J1_Conn0.A14, J1_Conn0.A17, J1_Conn0.A18, J1_Conn0.A21, J1_Conn0.A22, J1_Conn0.A25, J1_Conn0.A26, J1_Conn0.A29, J1_Conn0.A30, J1_Conn0.A33, J1_Conn0.A34, J1_Conn0.A37, J1_Conn0.A38, J1_Conn0.A41, J1_Conn0.A42, J1_Conn0.A45, J1_Conn0.A46, J1_Conn0.A49, J1_Conn0.A50, J1_Conn0.A53, J1_Conn0.A54, J1_Conn0.A57, J1_Conn0.A58, J1_Conn0.B3, J1_Conn0.B4, J1_Conn0.B7, J1_Conn0.B8, J1_Conn0.B11, J1_Conn0.B12, J1_Conn0.B15, J1_Conn0.B16, J1_Conn0.B19, J1_Conn0.B20, J1_Conn0.B23, J1_Conn0.B24, J1_Conn0.B27, J1_Conn0.B28, J1_Conn0.B31, J1_Conn0.B32, J1_Conn0.B35, J1_Conn0.B36, J1_Conn0.B39, J1_Conn0.B40, J1_Conn0.B43, J1_Conn0.B44, J1_Conn0.B47, J1_Conn0.B48, J1_Conn0.B51, J1_Conn0.B52, J1_Conn0.B55, J1_Conn0.B56, J1_Conn0.B57, J1_Conn0.B58, J1_Conn0.C5, J1_Conn0.C6, J1_Conn0.C9, J1_Conn0.C10, J1_Conn0.C13, J1_Conn0.C14, J1_Conn0.C17, J1_Conn0.C18, J1_Conn0.C21, J1_Conn0.C22, J1_Conn0.C25, J1_Conn0.C26, J1_Conn0.C29, J1_Conn0.C30, J1_Conn0.C33, J1_Conn0.C34, J1_Conn0.C37, J1_Conn0.C38, J1_Conn0.C41, J1_Conn0.C42, J1_Conn0.C45, J1_Conn0.C46, J1_Conn0.C49, J1_Conn0.C50, J1_Conn0.C53, J1_Conn0.C54, J1_Conn0.C57, J1_Conn0.C58, J1_Conn0.D3, J1_Conn0.D4, J1_Conn0.D7, J1_Conn0.D8, J1_Conn0.D11, J1_Conn0.D12, J1_Conn0.D15, J1_Conn0.D16, J1_Conn0.D19, J1_Conn0.D20, J1_Conn0.D23, J1_Conn0.D24, J1_Conn0.D27, J1_Conn0.D28, J1_Conn0.D31, J1_Conn0.D32, J1_Conn0.D35, J1_Conn0.D36, J1_Conn0.D39, J1_Conn0.D40, J1_Conn0.D43, J1_Conn0.D44, J1_Conn0.D47, J1_Conn0.D48, J1_Conn0.D51, J1_Conn0.D52, J1_Conn0.D55, J1_Conn0.D56, J1_Conn0.D57, J1_Conn0.D58, J1_Conn0.E1, J1_Conn0.E2, J1_Conn0.E5, J1_Conn0.E6, J1_Conn0.E9, J1_Conn0.E10, J1_Conn0.E13, J1_Conn0.E14, J1_Conn0.E17, J1_Conn0.E18, J1_Conn0.E21, J1_Conn0.E22, J1_Conn0.E25, J1_Conn0.E26, J1_Conn0.E29, J1_Conn0.E30, J1_Conn0.E33, J1_Conn0.E34, J1_Conn0.E37, J1_Conn0.E38, J1_Conn0.E41, J1_Conn0.E42, J1_Conn0.E45, J1_Conn0.E46, J1_Conn0.E49, J1_Conn0.E50, J1_Conn0.E53, J1_Conn0.E54, J1_Conn0.E55, J1_Conn0.E56, J1_Conn0.E57, J1_Conn0.E58, J1_Conn0.F3, J1_Conn0.F4, J1_Conn0.F7, J1_Conn0.F8, J1_Conn0.F11, J1_Conn0.F12, J1_Conn0.F15, J1_Conn0.F16, J1_Conn0.F19, J1_Conn0.F20, J1_Conn0.F23, J1_Conn0.F24, J1_Conn0.F27, J1_Conn0.F28, J1_Conn0.F31, J1_Conn0.F32, J1_Conn0.F35, J1_Conn0.F36, J1_Conn0.F39, J1_Conn0.F40, J1_Conn0.F43, J1_Conn0.F44, J1_Conn0.F47, J1_Conn0.F48, J1_Conn0.F51, J1_Conn0.F52, J1_Conn0.F53, J1_Conn0.F54, J1_Conn0.F55, J1_Conn0.F56, J1_Conn0.F57, J1_Conn0.F58, J1_Conn0.G5, J1_Conn0.G6, J1_Conn0.G9, J1_Conn0.G10, J1_Conn0.G13, J1_Conn0.G14,
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

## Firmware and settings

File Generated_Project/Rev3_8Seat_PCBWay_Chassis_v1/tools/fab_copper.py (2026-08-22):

#!/usr/bin/env python3
"""POWER+MECH copper for the Rev3 first article.

Called by generate_from_v10_pinmap.write_pcb(). Returns KiCad s-expr strings.

Routing policy:
  Do NOT flood P48V as one 100 A pour, and do NOT drag fat traces across the
  688-ball mezzanine. P48V_STAR lives in the left margin + two row spines in
  the copper-free channels south of each Conn0 row. Each seat fuse sits on
  that spine with pad 1 on STAR and pad 2 on a short per-seat P48V tongue
  into the Conn0 island. P12V1 / P3V3 use the same channels. F.Cu GND is
  low-priority and fills leftover (mezz GND pads + inner-plane stitches).

Buyable MPNs: see docs/BOM.md / BOM.md.
"""
from __future__ import annotations

import uuid

MEZZ_ZONE_CLEAR_MM = 0.20  # Molex 0.9 mm pitch, 0.50 mm pads → 0.40 mm gap
STAR_CLEAR_MM = 0.64  # OCP UBB v1.5 >40 V internal 25 mil, star/fuse copper
GND_CLEAR_MM = 0.25

# Row spines in the channels south of Conn0 (not across balls).
# Row 0 Conn0 Y≈154, P48V pads ≈157–162, NPTH ≈163.5, row1 KOZ at 186.
# Row 1 Conn0 Y≈320, P48V pads ≈323–328, NPTH ≈329.5, board south 372.
ROW_SPINE = {
    # STAR bus sits SOUTH of the fuse so pad 2 (seat net) is not in STAR copper.
    0: {"star_y0": 173.0, "star_y1": 178.0, "fuse_y": 169.5, "p12_y0": 179.0, "p12_y1": 183.0,
        "p3_y0": 183.5, "p3_y1": 185.5},
    1: {"star_y0": 343.0, "star_y1": 348.0, "fuse_y": 336.0, "p12_y0": 349.0, "p12_y1": 353.0,
        "p3_y0": 353.5, "p3_y1": 356.0},
}

# 12 V brick cluster: host-strip SOUTH of SW3 keepout (y>=332).
# THL40 courtyard ≈ 26.9 × 26.9 mm (pin1-relative -10.95,-3.25 to 15.95,23.65).
P12_MOD_XY = (470.0, 348.0)  # pin 1; courtyard y 344.75–371.65, west of x=492
P3V3_MOD_XY = (440.0, 366.0)  # south of row1 KOZ (y=352), west of host strip x=452
FP12_XY = (458.0, 338.0)      # south of SW3 (y=332), north of THL courtyard

BOARD_W, BOARD_H = 492.0, 372.0


def uid() -> str:
    return str(uuid.uuid4())


def p48_net(oam: int) -> str:
    return "P48V" if oam == 0 else f"P48V_S{oam}"


def zone(net_id: int, name: str, layer: str, clearance: float,
         pts: list[tuple[float, float]], priority: int = 0,
         min_th: float = 0.25) -> str:
    poly = " ".join(f"(xy {x:.3f} {y:.3f})" for x, y in pts)
    return f'''  (zone (net {net_id}) (net_name "{name}") (layer "{layer}") (uuid "{uid()}")
    (hatch edge 0.5)
    (priority {priority})
    (connect_pads yes (clearance {clearance}))
    (min_thickness {min_th})
    (filled_areas_thickness no)
    (fill yes (thermal_gap {clearance}) (thermal_bridge_width 0.5))
    (polygon (pts {poly}))
  )'''


def rect(x0, y0, x1, y1) -> list[tuple[float, float]]:
    return [(x0, y0), (x1, y0), (x1, y1), (x0, y1)]


def track(a, b, w, layer, net) -> str:
    return (
        f'  (segment (start {a[0]:.3f} {a[1]:.3f}) (end {b[0]:.3f} {b[1]:.3f})'
        f' (width {w}) (layer "{layer}") (net {net}) (uuid "{uid()}"))'
    )


def via(xy, net, layers=("F.Cu", "In1.Cu")) -> str:
    return (
        f'  (via (at {xy[0]:.3f} {xy[1]:.3f}) (size 0.8) (drill 0.4)'
        f' (layers "{layers[0]}" "{layers[1]}") (net {net}) (uuid "{uid()}"))'
    )


def fp_nano(ref: str, xy, rot: float, value: str, net1, net2) -> str:
    x, y = xy
    n1i, n1n = net1
    n2i, n2n = net2
    rot_s = f" {rot:.0f}" if rot else ""
    return f'''  (footprint "footprints:Fuse_Littelfuse-NANO2-451_453" (layer "F.Cu") (uuid "{uid()}")
    (at {x:.3f} {y:.3f}{rot_s})
    (descr "{value} Nano2")
    (property "Reference" "{ref}" (at 0 -2.8) (layer "F.SilkS")
      (effects (font (size 0.8 0.8) (thickness 0.1))))
    (property "Value" "{value}" (at 0 2.8) (layer "F.Fab")
      (effects (font (size 0.7 0.7) (thickness 0.1))))
    (attr smd)
    (fp_rect (start -3.69 -1.83) (end 3.69 1.83)
      (stroke (width 0.05) (type solid)) (fill none) (layer "F.CrtYd"))
    (pad "1" smd rect (at -2.455 0) (size 1.96 3.15)
      (layers "F.Cu" "F.Mask" "F.Paste") (net {n1i} "{n1n}"))
    (pad "2" smd rect (at 2.455 0) (size 1.96 3.15)
      (layers "F.Cu" "F.Mask" "F.Paste") (net {n2i} "{n2n}"))
  )'''


def fp_thl40(ref: str, xy, nets: dict) -> str:
    x, y = xy
    def n(pin):
        i, name = nets[pin]
        return f'(net {i} "{name}")'
    return f'''  (footprint "footprints:Converter_DCDC_TRACO_THL40-xxxxWI_THT" (layer "F.Cu") (uuid "{uid()}")
    (at {x:.3f} {y:.3f})
    (descr "THL 40-4812WI 40W 12V from 48V. Isolated; both returns bonded to GND.")
    (property "Reference" "{ref}" (at 2.5 -4) (layer "F.SilkS")
      (effects (font (size 1 1) (thickness 0.12))))
    (property "Value" "THL 40-4812WI" (at 2.5 25) (layer "F.Fab")
      (effects (font (size 0.8 0.8) (thickness 0.1))))
    (attr through_hole)
    (fp_rect (start -10.95 -3.25) (end 15.95 23.65)
      (stroke (width 0.05) (type solid)) (fill none) (layer "F.CrtYd"))
    (pad "1" thru_hole roundrect (at 0 0) (size 2.4 2.4) (drill 1.4)
      (layers "*.Cu" "*.Mask") {n("1")})
    (pad "2" thru_hole circle (at 5.08 0) (size 2.4 2.4) (drill 1.4)
      (layers "*.Cu" "*.Mask") {n("2")})
    (pad "3" thru_hole circle (at -7.62 20.32) (size 2.4 2.4) (drill 1.4)
      (layers "*.Cu" "*.Mask") {n("3")})
    (pad "4" thru_hole circle (at 2.54 20.32) (size 2.4 2.4) (drill 1.4)
      (layers "*.Cu" "*.Mask"))
    (pad "5" thru_hole circle (at 12.7 20.32) (size 2.4 2.4) (drill 1.4)
      (layers "*.Cu" "*.Mask") {n("5")})
    (pad "6" thru_hole circle (at 12.7 0) (size 2.4 2.4) (drill 1.4)
      (layers "*.Cu" "*.Mask"))
  )'''


def fp_oki(ref: str, xy, rot: float, nets: dict) -> str:
    x, y = xy
    rot_s = f" {rot:.0f}" if rot else ""
    def n(pin):
        i, name = nets[pin]
        return f'(net {i} "{name}")'
    return f'''  (footprint "footprints:Converter_DCDC_Murata_OKI-78SR_Vertical" (layer "F.Cu") (uuid "{uid()}")
    (at {x:.3f} {y:.3f}{rot_s})
    (descr "OKI-78SR-3.3/1.5-W36-C 3.3V 1.5A from P12V1")
    (property "Reference" "{ref}" (at 2.54 3.2) (layer "F.SilkS")
      (effects (font (size 0.8 0.8) (thickness 0.1))))
    (property "Value" "OKI-78SR-3.3/1.5-W36-C" (at 2.54 4.6) (layer "F.Fab")
      (effects (font (size 0.6 0.6) (thickness 0.08))))
    (attr through_hole)
    (fp_rect (start -2.91 -5.44) (end 8 3.41)
      (stroke (width 0.05) (type solid)) (fill none) (layer "F.CrtYd"))
    (pad "1" thru_hole rect (at 0 0) (size 1.8 1.8) (drill 1)
      (layers "*.Cu" "*.Mask") {n("1")})
    (pad "2" thru_hole circle (at 2.54 0) (size 1.8 1.8) (drill 1)
      (layers "*.Cu" "*.Mask") {n("2")})
    (pad "3" thru_hole circle (at 5.08 0) (size 1.8 1.8) (drill 1)
      (layers "*.Cu" "*.Mask") {n("3")})
  )'''
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

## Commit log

2026-08-21 Add Rev3 8-seat PCBWay chassis stub (not fab-ready).
    Maps the v1.0 OAM pinout onto a 492x372 mm 4-layer 8-seat coupon so a PCBWay-size carrier can be discussed instead of buying an AS-4124GQ-TNMI tray. DO NOT FABRICATE; P48V is not energized.
    [00_do_not_fabricate.kicad_sch, 01_power_clock_reset.kicad_sch, 02_host_pcie_stub.kicad_sch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]
2026-08-21 Raise Rev3 chassis to 8 electrically designed seats.
    Name v1.0 power/PE/clock nets on all eight OAM seats toward two DNP
    PM8536B-FEI (x8 per GCD), keep SB175 star + local P48V pours, and generate
    the 12-layer 2.0 mm stuffed-switch target. First stuffing may still populate
    two modules; the PCB does not need a respin for the other six.
    Do not fabricate. Do not energize P48V.
    [00_do_not_fabricate.kicad_sch, 01_power_clock_reset.kicad_sch, 02_host_pcie_stub.kicad_sch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]
2026-08-22 Regenerate KiCad 9.0.9 ERC/DRC and 8-seat chassis previews.
    Record expected named-net stub counts (1280 ERC, 54 DRC + 499
    unconnected) and refresh top PNG/SVG plus inner GND layer plots.
    Not a fab sign-off. Do not fabricate or energize P48V.
2026-08-22 Label PEX8780-AB80BI G as the only switch CANDIDATE (DNP).
    Keepout is one 35 mm 1156-FCBGA for 8x x8 Gen3 plus one x16 host uplink.
    Do not invent a second MPN. Do not stuff. 8-layer is likely if this BGA
    is ever assembled; PCBWay 1156-FCBGA attach remains Unknown.
    Still do not fabricate or energize P48V. No xGMI, no CEM.
    [00_do_not_fabricate.kicad_sch, 01_power_clock_reset.kicad_sch, 02_host_pcie_stub.kicad_sch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]
2026-08-22 Make PM8536B-FEI the PRIMARY switch keepout (DNP x2).
    Two 37.5 mm 1311-FCBGA courtyards, x8 per GCD (SW0 seats 0-3, SW1 4-7),
    two CPU x16 uplinks. PEX8780 stays a cheaper 80-lane alt in docs only.
    GCD1 = SERDES_7 remains Inferred. No CEM, no xGMI, do not fabricate.
    [00_do_not_fabricate.kicad_sch, 01_power_clock_reset.kicad_sch, 02_host_pcie_stub.kicad_sch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]
2026-08-22 Record live 4L/8L PCBWay guest quotes; prefer 8L 2.0 mm DNP.
    Qty 5 min (qty 1 rejected), 492x372, 2 oz outer, ENIG. 8L 2.0 mm
    $832.74 is the no-switch stack; 12-16L remains stuffed-switch.
    Do not upload or order.
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2026-08-22 Regenerate 8-seat named-net chassis: all seats electrically designed.
    Sheet names seats 2-7 are connectors, not MechPower. Silk/title say named-net
    chassis. KiCad 9.0.9 ERC/DRC and top preview refreshed. Do not fabricate,
    do not energize P48V, do not upload to PCBWay.
    [00_do_not_fabricate.kicad_sch, 01_power_clock_reset.kicad_sch, 02_host_pcie_stub.kicad_sch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]
2026-08-22 Add PCBWay-submittable POWER+MECH fab package for the Rev3 8-seat chassis.
    Star-fed P48V (SB175 6325G1 + 2x 1382, per-seat 0476015.MR, local Conn0 pours),
    THL 40-4812WI and OKI-78SR bucks, filled 12L 2.0 mm Gerbers/drill/IPC-356/PnP.
    PM8536 stays DNP. Silk keeps DO NOT ENERGIZE P48V. Do not upload from this agent.
    [00_do_not_fabricate.kicad_sch, 01_power_clock_reset.kicad_sch, 02_host_pcie_stub.kicad_sch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]
2026-08-22 Make the Rev3 8-seat chassis full-width capable with four PM8536 DNP courtyards.
    Same 492x372 POWER+MECH PCB; architecture is now 16 named x16 PE buses
    (PE_Sn_GCD0_x16 + PE_Sn_GCD1_x16) and SW0-SW3 keepouts. Two 96-lane
    switches are enough for 8x x8/GCD, not 8x x16/GCD. Host stays X11DPH-T
    (~80 lanes) and cannot light 256 downstream. Do not energize P48V.
    [00_do_not_fabricate.kicad_sch, 01_power_clock_reset.kicad_sch, 02_host_pcie_stub.kicad_sch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]
2026-08-22 Retarget Rev3 first article to seats 0-1 GCD0 x16 (2-module path).
    Same 8-seat PCB. Without overlay, 2x MI250X means two modules can sit
    and at most GCD0 on each can be named toward the host keepout (2 GCDs),
    not 2x full-width (4 GCDs). Conn0 OCP PCIE_* is the only legal host PE.
    No CEM/MCIO MPN. Do not energize P48V.
    [00_do_not_fabricate.kicad_sch, 01_power_clock_reset.kicad_sch, 02_host_pcie_stub.kicad_sch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]
2026-08-22 Separate overlapping host-keepout silk on the 2-module first article.
    Move the X11DPH-T lane-budget line off HOST CABLE KEEPOUT so POWER+MECH
    DRC stays 0 errors (38 warnings). Regenerated Gerbers after the silk
    nudge. Do not energize P48V. Do not upload to PCBWay.
    [MI250X_8OAM_PCBWay_Chassis_Stub-B_Cu.gbr, MI250X_8OAM_PCBWay_Chassis_Stub-B_Mask.gbr, MI250X_8OAM_PCBWay_Chassis_Stub-B_Paste.gbr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]
2026-08-22 Document an 8x full-width chassis CONCEPT (ideas only, not fab).
    Sibling folder plus STATUS pointer. Comments-layer KiCad notes say
    CONCEPT / DO NOT FABRICATE. No overlay, ball map, CEM/MCIO, r2.0, or
    S1-S7 assignment. X11DPH-T cannot light 256 DS. Do not energize.
    Do not upload to PCBWay.
    [02_host_pcie_stub.kicad_sch, 11_pcie_switch_unknown.kicad_sch, MI250X_8OAM_PCBWay_Chassis_Stub.kicad_pcb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]
2026-08-22 Reserve late-bind hooks; 16x x16 PE remains a copper respin.
    Document what overlay, PM8536, host plug, Molex 1.2 A, and cooling
    already have vs what a later spin must add. Comment-layer corridors
    for seats 0-1 GCD0 toward host keepout and SW0; no guessed tracks.
    Do not claim the POWER+MECH zip works as a live GPU chassis.
    Do not energize. Do not upload to PCBWay.
    [MI250X_8OAM_PCBWay_Chassis_Stub.kicad_pcb]
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
